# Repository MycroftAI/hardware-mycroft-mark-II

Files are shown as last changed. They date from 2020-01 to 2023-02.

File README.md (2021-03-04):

# Mycroft Mark II Hardware

*⛵️ Note that this repository is a work-in-progress. It will be updated and improved on over time.*

This repository contains all of the designs and technical details of the Mycroft Mark II Prototypes.

Each sub-directory represents a prototype device. Currently this consists of:
- [Mark II RPi OTS](./mark-II-rpi-ots) - the first Mark II prototype released in February 2020 made from off-the-shelf components. [Deprecated]
- [Mark II RPi DevKit](./mark-II-Rpi-devkit) - the second iteration of the Mark II prototype. This includes a custom daughterboard (SJ201) that integrates the components from the OTS prototype into a single PCB.

## Our open hardware principles
* **Copy our designs** – build your own Mycroft Mark 2 - Raspberry Pi Edition or its individual parts
* **Modify our designs** – remixing is encouraged
* **Sell products based on our designs** – commercial use is permitted
* **Always keep the open license** – contribute your output back to the community
* **Credit the original author(s)** – like they do in science

## Feedback or ideas

We are always keen to hear from the community about ways to improve these designs. Whether you're a hacker, maker, engineer, or something else - join us in the:
- [Community Forums](https://community.mycroft.ai)
- [Community Chat](https://chat.mycroft.ai)
- or email us at [dev@mycroft.ai](mailto:dev@mycroft.ai)

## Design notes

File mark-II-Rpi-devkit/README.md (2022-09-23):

# Mycroft Mark II - DevKit Prototype

## Kit Major Components
* Raspberry Pi 4
* SJ201 Daugherboard
* Audio Chamber
* Dual 5W Speaker drivers
* 4.2" Full Color touchscreen LCD
* Acrylic Enclosure
* Universal 12V power supply (USA, EU,UK, AUS, CCC)

## SJ201 Daughterboard
This prototype includes a custom daughterboard (SJ201) that integrates the components from the OTS prototype into a single PCB.

The SJ201 interfaces directly to the Raspberry Pi 4 via the 40-pin GPIO adding a high-quality speaker and microphone array, as well as LEDs and hardware inputs for non-voice interaction and feedback.

The part number SJ201 is derived from Mike’s “Simon Jester” alias in “The Moon is a Harsh Mistress”.

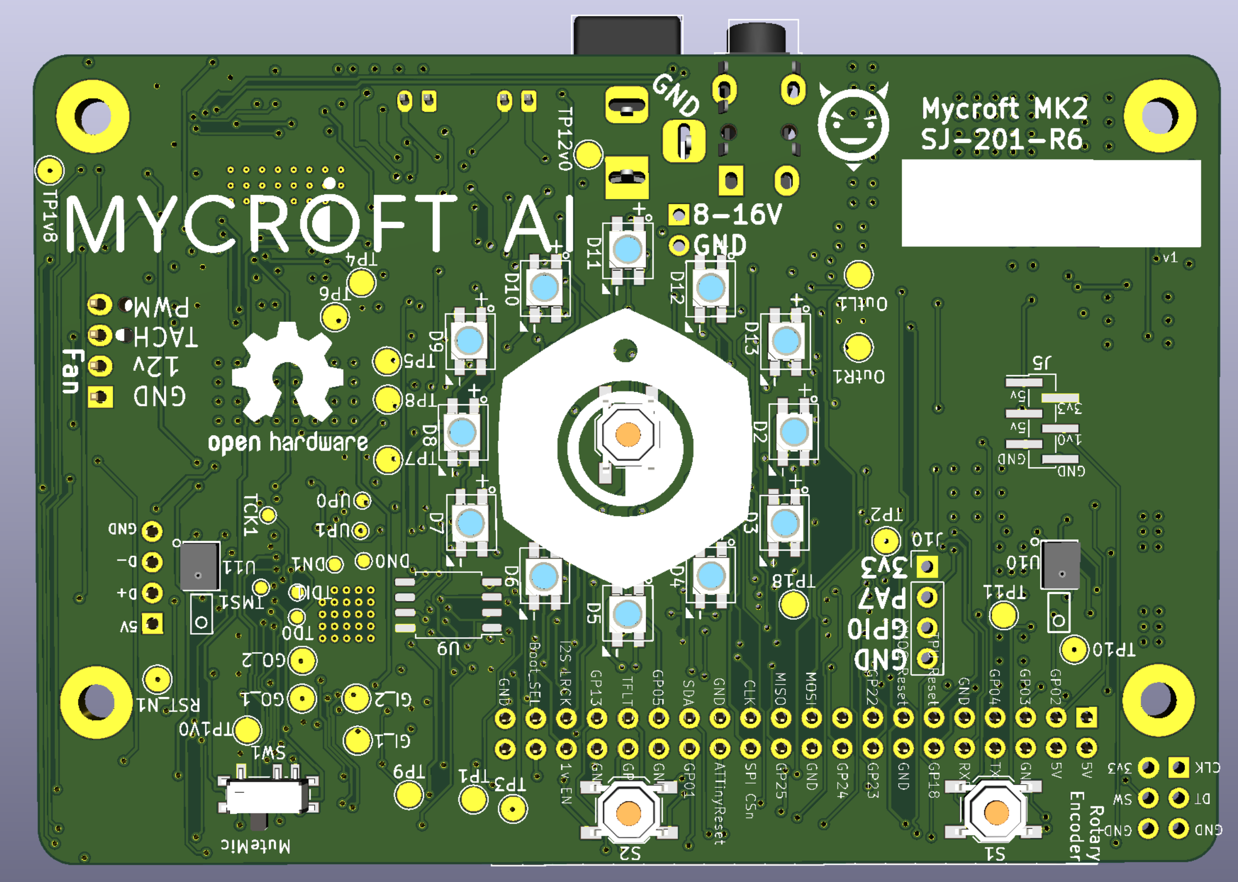
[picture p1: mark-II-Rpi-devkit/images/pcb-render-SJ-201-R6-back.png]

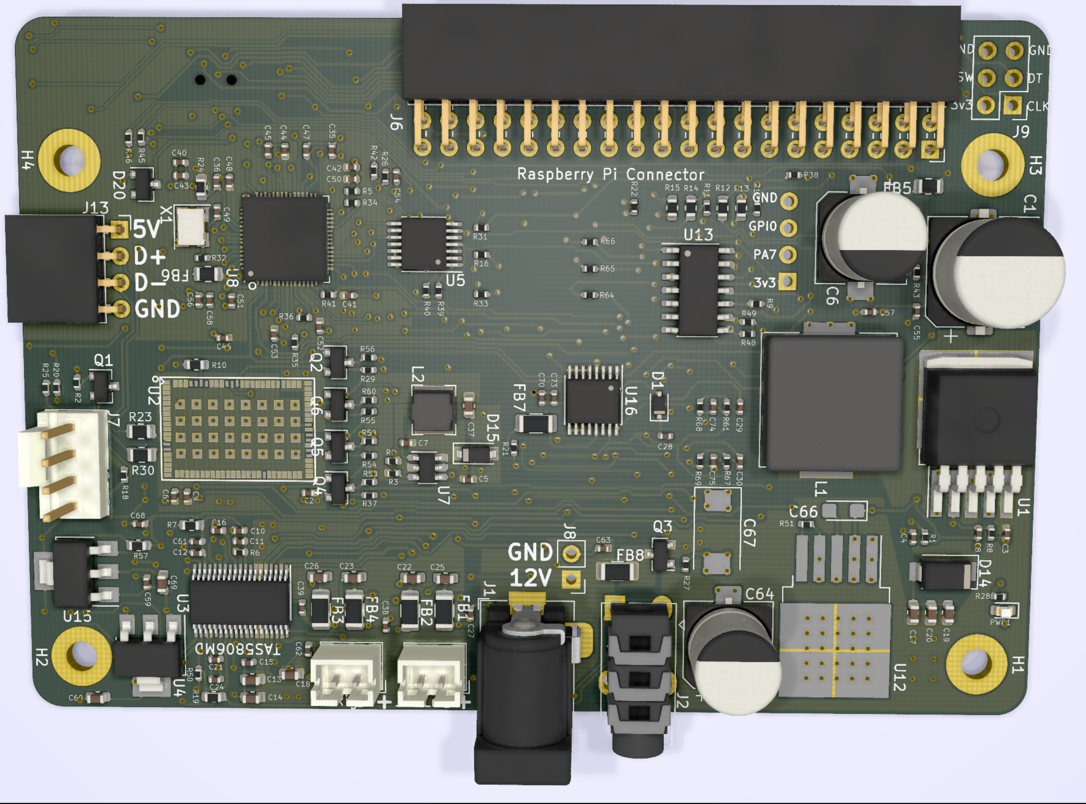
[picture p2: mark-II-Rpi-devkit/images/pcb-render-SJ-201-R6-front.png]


### SJ201 Major Components
* Audio Front End (XMOS XVF-3510) - for Microphone input processing
* I2S to Line Out (UDA1334ATS)
* 23W Amplifier (Texas Instruments TAS5806)
* 2 Digital MEMS Microphones (ST Micro MP34DT05)
* 12 RGB LEDs (WorldSemi WS2812B-MINI)
* 3 momentary buttons (volume up, volume down, action)
* 1 toggle switch (mic mute)
* ATtiny1614 - control LEDs, other I/O

### Technical Documentation
For technical details of these board see the 
* [SJ201-Datasheet](./KiCAD/SJ201-Raspberry%20Pi%204%20Daughterboard/README.md).

## New Form Factor
The SJ201 connects to the Raspberry Pi GPIO header at a 90 degree angle. This allows the microphone array and hardware inputs to be well positioned in the enclosure, whilst maintaining the simplicity of a direct connection to the main board. 

This interface makes a landscape form factor the most viable for this prototype. The blocking of the major components can be found within the [Mechanical CAD > MkII Blocking r2.zip](./Mechanical%20CAD/MkII%20Blocking%20r2.zip). 

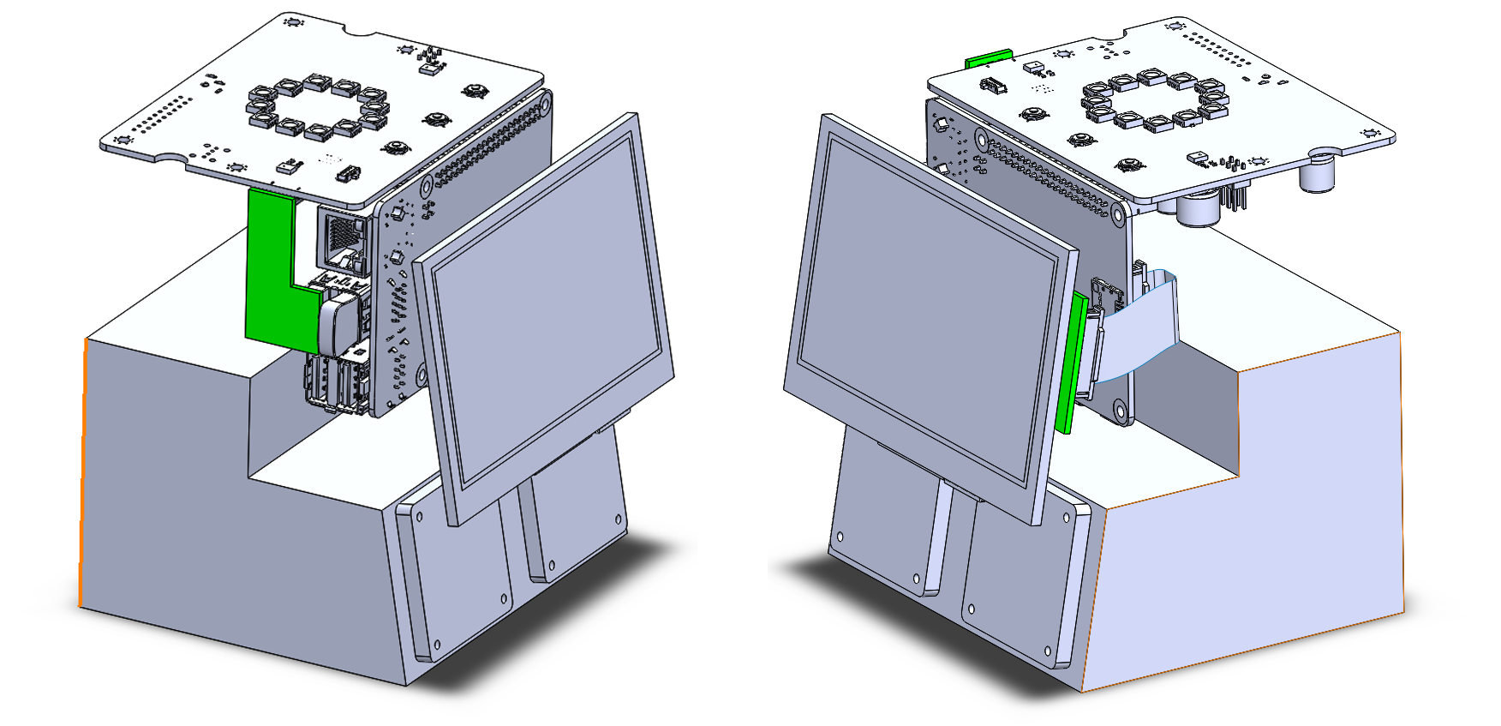
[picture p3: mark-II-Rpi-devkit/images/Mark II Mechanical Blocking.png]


## 3D Printable Case
STL files for 3D printing are available in this directory to print your own enclosure. For final construction you will also need threaded inserts and screws. For the inserts we recommend - Thread Diameter: M2.5; Pitch: 0.45; Outer Dia: 3.5mm; Length: 4mm. [Available here](https://www.amazon.com/uxcell-Threaded-Insert-Embedment-Knurled/dp/B01N8QX6RX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).

Complete assembly instructions can be found [here on Instructables](https://www.instructables.com/Mycroft-Mark-II-3D-Printed-Developer-Kit-Assembly/).

## Our open hardware principles
* **Copy our designs** – build your own Mycroft Mark 2 - Raspberry Pi Edition or its individual parts
* **Modify our designs** – remixing is encouraged
* **Sell products based on our designs** – commercial use is permitted
* **Always keep the open license** – contribute your output back to the community
* **Credit the original author(s)** – like they do in science

## Feedback or ideas

We are always keen to hear from the community about ways to improve these designs. Whether you're a hacker, maker, engineer, or something else - join us in the:
- [Community Forums](https://community.mycroft.ai)
- [Community Chat](https://chat.mycroft.ai)
- or email us at [dev@mycroft.ai](mailto:dev@mycroft.ai)

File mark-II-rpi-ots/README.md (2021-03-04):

# Mycroft Mark II - Rpi Prototype Hardware
*Mycroft's Mark II Raspberry Pi 3 based prototype designs*  
*⛵️ This design is not longer offcially supported by Mycroft *

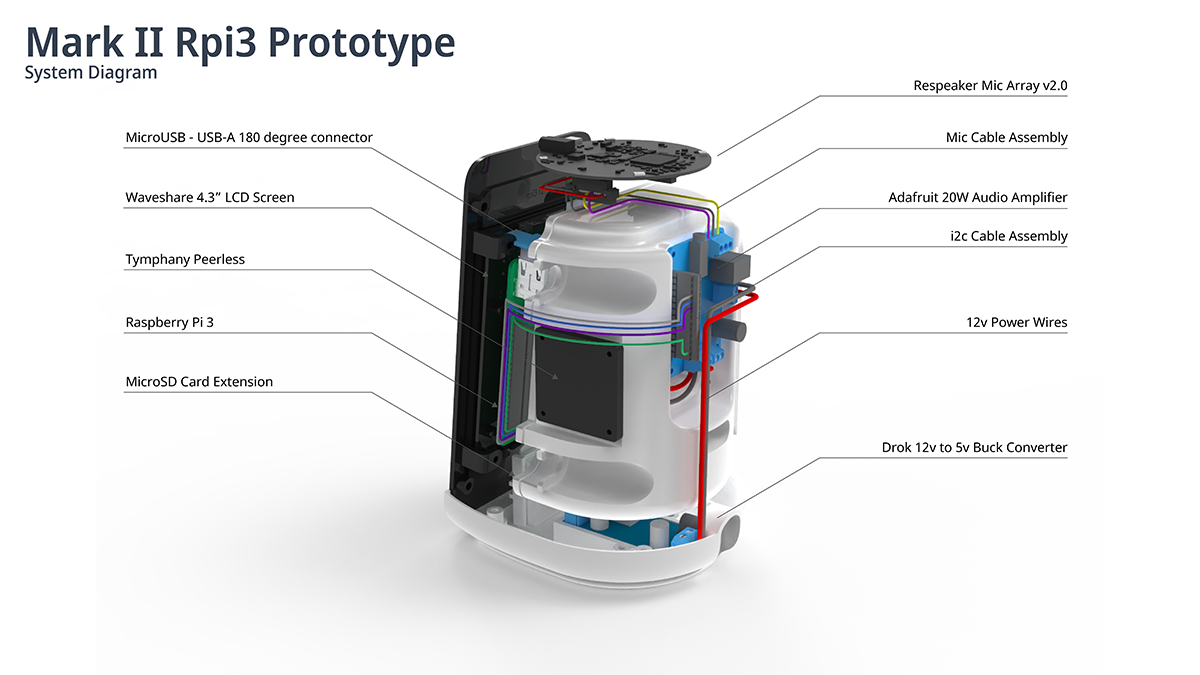
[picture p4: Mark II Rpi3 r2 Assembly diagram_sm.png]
Exploded view of prototype


## Our open hardware principles
* **Copy our designs** – build your own Mycroft Mark 2 - Raspberry Pi Edition or its individual parts
* **Modify our designs** – remixing is encouraged
* **Sell products based on our designs** – commercial use is permitted
* **Always keep the open license** – contribute your output back to the community
* **Credit the original author(s)** – like they do in science

## License
We're open-sourcing all our designs under the CERN Open Hardware License, which is one of the open hardware licenses recommended by OSHWA, the Open Source Hardware Association. The release involves every single piece of our design except components we have no control over, like the Raspberry Pi. We've also joined the Open Source Hardware Certification Program.

Open Source Hardware Logo OSHW (https://certification.oshwa.org/)

## Instructions
### Getting Started
To begin you need to purchase the parts listed in the [Bill of Materials (BOM)](BOM.md). The Mark II Raspberry Pi 3 prototype consists of 7 major components and many smaller components needed to connect them together. The 7 major components are:

* **Raspberry Pi 3B (not 3B+ or 4 yet)**
* **Seeed Studios Respeaker Mic Array v2.0**
* **Waveshare 4.3" IPS 800x480 LCD**
* **Drok 12v to 5v 5A buck converter part # 200217**
* **Adafruit 20W Stereo class D Amplifer - MAX9744**
* **A pair of Tymphany Peerless TC5FC07-04 speaker drivers**
* **A set of 3D printed Mark II Raspbery Pi 3 prototype parts**

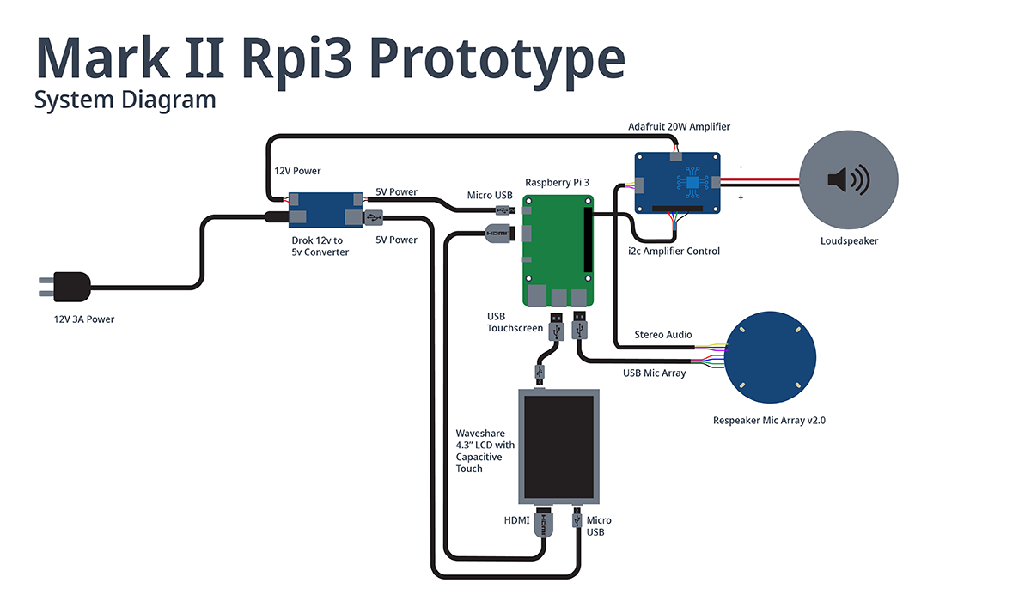
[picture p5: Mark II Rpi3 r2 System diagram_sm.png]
System diagram


### Creating the Custom Cable Assemblies
To connect the Raspberry Pi, Respeaker Mic Array V2.0, and Adafruit Amplifer two custom cable assemblies are required. The first cable assembly allows the Respeaker Mic Array to communicate to the Raspberry Pi via USB and to the Amplifer via analog stereo audio. To create the Microphone cable assembly follow this video guide:  
Microphone cable assembly video guide (https://youtu.be/UepmmYCgYgI)

The second cable assembly connects the i2c interface from the GPIO on the Raspberry Pi to the Adafruit amplifier. This allows the Raspberry Pi to digitally control the gain on the amplifier. To create the GPIO to i2c cable assembly follow this video guide:  
GPIO to i2c cable assembly video guide (https://youtu.be/yoYU8CrY8kU).

The connectors and ribbon cables required to build both of these cable assemblies are listed in the BOM.

### 3D Printing the Housing
The parts for the housing are shared as both STL and STP files under [CAD](https://github.com/MycroftAI/hardware-mycroft-mark-II-rpi/tree/master/CAD). Our prototypes are printed on a Formlabs SLA 3D printer but these can be adapted for printing on an FFF machine as well. You will need to orient the parts and slice them based on the requirements of your printer. Some parts require the additoin of threaded inserts for assembly. Two sizes of threaded inserts are used in the prototype m2.5 and m2. These can be installed in the parts with a soldering iron if using FFF printing, or with Cyanoacrylate glue (super glue) if you're using an SLA printer. SLA printed parts do not melt like FFF parts so installation with a soldering iron won't work. These images show the size and location of the threaded inserts [threaded insert locations](https://github.com/MycroftAI/hardware-mycroft-mark-II-rpi/tree/master/CAD/threaded%20insert%20locations)

### Assembling the Amplifier and Preparing the Speakers
Follow [this guide](https://learn.adafruit.com/adafruit-20w-stereo-audio-amplifier-class-d-max9744) on Adafruit's website to assemble the amplifier. Soldering skills are needed. You will also need to solder leads onto the Tymphany speaker drivers. There is a small dot marking the positive side of the speaker. It is important that you wire the speakers correctly or they will be out of phase. Use the red 22 gauge wire for positive and the black for negative.

### Assembling the Audio Chamber
The audio chamber is printed in two parts and glued together with hot glue. The Tymphany drivers are installed on either side of the Audio chamber and the wires go through holes in the back to allow for easy connection to the speaker terminals on the amplifier. Install the Amplifer to the back of the Audio Chamber with 4 m2x6mm screws.

### Final Assembly
A video is coming soon. Connect the Raspberry Pi3 to the Waveshare display with the Waveshare included stand-offs. Connect the HDMI to HDMI connector (included with Waveshare display) and USB-A to MicroUSB connector (included with the Waveshare display) to the Rpi3 and the display. Install the Waveshare display and Rpi3 assembly through the front facing side of the Front Piece. It is a tight squeeze so you will need to angle the display to get it in. The ports should be facing up. Secure the display with 4 m2.5x6mm screws through the 4 L-shaped brackets. Attach the two Body pieces to the threaded inserts on the Front Piece. Next attach the the Drok Power Supply to the Base. The barrel connector should line up with a hole in the base. Plug the Cerrxian USB-A to MicroUSB cable into the USB port on the Drok. Attach a MicroUSB cable with positive and negative leads to the terminal next to the USB port on the Drok power converter. Next hot glue the SD Card extension behind the Drok Power Converter so that it is facing down and the MicroSD card slot will be accessible from the bottom of the device. Bring the Body/Front Piece assembly and Base together and plug the MicroSD card extension into the Rpi3. Now attach the Base to the Body and Front Piece assembly via 4 m2.5x10mm screws through the holes in the base of the Mark II. Attach the Respeaker Mic Array v2.0 to the Top-2 with 3 m2x4mm screws. Attach the Top-2 and Mic Array assembly to the Top piece with 4 m2x6mm screws. Attach the Microphone Cable Assembly to the bottom of the Respeaker Mic Array. Plug the USB into the Raspberry Pi, and slide the assembled Microphone Array and Top into the slots at the top of the Body. Attach the i2c Cable Assembly to the Raspberry Pi 3. Install the Audio Chamber onto the 4 screw bosses on the Body. The Audio Chamber won't be secure until the Back is installed. Placing the Mark II face down on a soft surface at this point is probably the easiet for installation. Connect the 12v terminal on the Drok power converter to the 12v terminal on the Amplifier with red and black 22 gauge wire. Connect the 3 audio cables from the Mic Cable Assembly to the L, N, R terminals on Amplifier. Now install the back piece through the Audio Chamber and secure it to the Body. The Mark II prototype assembly is now complete.

### Software
We still need to release the GUI prototype software, but once the software is relased, download the image burn it to a 16gb or larger SD card with Etcher and plug it into the bottom of the Mark II. Plug in the power supply and follow the instructions.

## Contact
If you are doing, or planning to do, something interesting with our designs, or if you just have a question regarding the files, get in touch with our Chief of Design Derick! (He was the one who designed Mycroft Mark II’s enclosure.)

Derick

**Derick Schweppe**  
Mycroft AI’s Chief of Design  
derick.schweppe@mycroft.ai

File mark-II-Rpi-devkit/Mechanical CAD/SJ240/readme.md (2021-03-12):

# Mycroft Mark II - SJ240 3D Printed Housing
## This 3D printed Housing for use with the SJ201

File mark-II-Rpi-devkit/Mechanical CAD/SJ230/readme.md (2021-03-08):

# Mycroft Mark II - SJ230 Laser Cut Acrylic Housing

## This Acrylic Housing is used in the Enhanced Dev Kit
The cut file for the housing (DXF, SVG) contains the following parts arranged for cutting on a 12" x 18" Sheet of 1/4" Acrylic (ture thickness of 5.5mm)

* SJ230-01	Top (contains 4 m2.5 threaded inserts)
* SJ230-02	Right Side
* SJ230-03	Left Side
* SJ230-04	Front (contains 2 m2.5 threaded inserts)
* SJ230-05	Bottom
* SJ230-06	Speaker Mount, Right (contains 2 m2.5 threaded inserts)
* SJ230-07	Speaker Mount, Left (contains 2 m2.5 threaded inserts)
* SJ230-08	Camera alignment

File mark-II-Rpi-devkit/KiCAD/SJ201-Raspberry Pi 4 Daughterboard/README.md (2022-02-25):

# SJ201 Datasheet - Rev 8

This board interfaces directly to the Raspberry Pi 4 via the 40-pin GPIO adding a high-quality speaker and microphone array, as well as LEDs and hardware inputs for non-voice interaction and feedback.

The part number SJ201 is derived from Mike’s “Simon Jester” alias in “The Moon is a Harsh Mistress”.




## About this Document

This Datasheet will contain all the relevant information for the manufacturing of the SJ201 including information about PCB design, PCB manufacturing process.

## Major Components
* Audio Front End (XMOS XVF3510) - for Microphone input processing
* 23W I2S Digital Amplifier (Texas Instruments TAS5806MD)
* 2 Digital MEMS Microphones ([Knowles SPK0641HT4H-1](https://www.digikey.com/en/products/detail/knowles/SPK0641HT4H-1/8573345))
* 12 RGB LEDs (WorldSemi WS2812B-MINI)
* 3 momentary buttons (volume up, volume down, action)
* 1 toggle switch (mic mute)
* ATtiny1614 - control LEDs, other I/O

## Hardware Notes

- The SJ201 is plugged into the GPIO header of the Raspberry Pi 4 board.
- The pins required for the operation of the Raspberry Pi 4 MIPI and CSI are not used on the SJ201 GPIO header. The display and camera do not connect to the SJ201.
- The barrel jack on the SJ201 requires a 12V, 3A regulated DC input.

## Software Notes
- SHTDN (GPIO pin GPIO5) must be set high to enable the audio amplifier.
- The TAS5806 outputs I2S to the XMOS chip. 

## Configuration options

### Default Use Case

The SJ201 is connected to a Raspberry Pi4 via the header. 

12V is supplied to the SJ201 via the barrel jack.

The SJ201 creates 5V using a 3A buck converter, which powers the Raspberry Pi.

The SJ201 creates 3.3V using a linear regulator, which powers the on-board devices.

4.4ohm, 5W speakers are connected to the JST connectors. [Note, in the current implementation the amplifier is capable of supplying 13W to each speaker, so volume must be limited in software to avoid damage.]

### Test Configuration Options

The J5 header serves as a test point for the 3.3V, 5V and 12V supplies. 

The J5 header can also be used to bypass the on-board buck converter and/or linear regulator.

The buck converter does not need to be turned off - it can tolerate an external supply. To completely disable it, lift the appropriate pin.

The 1.0V supply can be tested using Test Point TP1_0V1 near the XMOS IC.

## Design Notes

### Power Domains

The SJ201 is powered by an external 12V 3A DC supply (wall wart) via a barrel connector. The SJ201 has 4 voltage domains:

- VDD 12V externally supplied power

- PVDD 12V Analog Audio Power

- 5V  5V derived from VDD

- 3V  3.3V derived from 5V

- 1V  1.0V derived from 5V for the XMOS core

All power domains share a common ground.

- GND  Ground

### Microphone DSP

### Audio Amplifier

**Filterless modulation**  
We are using the TAS5806, in a "filterless amplifier" design. This is lower cost than using a true LC filter for each output, but can be susceptible to large EMI output if not done properly. This can lead to failure to meet FCC and other standards required for consumer electronics. The following design rules are intended to minimize EMI in the system.

**Speaker power**  
With a 4ohm speaker and a 12V supply, each channel can achieve ~13W. The speaker we're using is 4.4ohm, 5W max. The volume must be limited in software to avoid damaging the speaker.

## PCB Layout Checklist

Boxes marked 🗹 are for version 6.02 (also labeled R6 v2) of the KiCAD files.

### Layers - PCB checklist

Layer 1:  Main ICs, connectors and signal routing - Power (1.0v, PVDD 12v)

Layer 2:  GND

Layer 3:  Power (12V, 5V, 3V3)

Layer 4:  Buttons, LEDs, signal routing (this layer faces upwards on device) 

### Power - PCB checklist

#### External Power Supply (VDD)

1. Barrel jack is centered on 10.6mm from the board edge.

2. Ferrite bead close to barrel jack to reduce EMI transmission along power cord to wall
   - Spec'd to handle 12V 3A

3. AO3401A MOSFET to protect against reverse voltage (i.e. user plugs in a non-standard external power supply with GND on the center pin instead of on the outside of the barrel connector.)

4. Low resistance traces for VDD and GND connecting to power planes.

#### Analog Audio Power (PVDD)

1. PVDD does not contain loops (areas of PVDD that enclose non-PVDD areas)

2. PVDD does not contain narrow antenna-like features.

3. PVDD is primarily located on layer 3

4. PVDD connects to layer 1 traces through multiple vias for lower resistance

5. See Audio Amplifier for additional considerations

#### 5V power

XL Semiconductor's XL4015 buck converter is used to generate 5V at up to 5A from the barrel jack power. This part supports a minimum input voltage of 8V and a max of 36V. 

🗹  <http://www.xlsemi.com/datasheet/XL4015%20datasheet.pdf>

🗹  R1 and R8 are 1% tolerance (these set the output voltage. 10% resistors could result in an output range of 4.4V - 5.9V.)

#### 3.3V power

A linear regulator is used to derive 3.3V from 5V.

-   AZ1117CH-3.3

-   <https://www.diodes.com/assets/Datasheets/AZ1117C.pdf> 

### Microphones (MP34DT05-A)- PCB checklist

🗹  <https://www.st.com/content/ccc/resource/technical/document/datasheet/group3/c7/90/d3/f6/b7/e7/40/c8/DM00415595/files/DM00415595.pdf/jcr:content/translations/en.DM004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> 

🗹  Power supply decoupling capacitors (100 nF ceramic, 1 μF ceramic) should be placed as near as possible to pin 1 of the device (common design practice). 

🗹  The L/R pin must be connected to Vdd or GND (refer to Table 6. L/R channel selection).

### LED (WS2812B-Mini)- PCB checklist

🗹  <https://datasheet.lcsc.com/szlcsc/2005251033_Worldsemi-WS2812B-Mini_C527089.pdf>

### Power on Reset - PCB checklist

-   <https://www.onsemi.com/pub/Collateral/NCP302-D.PDF> 

-   ~~This circuit monitors multiple power supply rails for undervoltage conditions. If any of the three power supplies are in an undervoltage condition, the NCP302 reset output will be immediately set to an active low level. All three power supplies must be above their minimum voltage levels for the NCP302 reset output to generate a "Power Good" level (Reset Output = Power Supply 1 or VP).~~ Replaced by Raspberry Pi control for startup routine.

### SG-210STF 24MHz clock - PCB checklist

🗹 Use recommended pad layout per datasheet.

-   <https://support.epson.biz/td/api/doc_check.php?mode=dl&lang=en&Parts=SG-210STF> 

### XMOS XVF3510 - PCB checklist 

Datasheets:

-   <https://www.xmos.com/documents/vocalfusionavs>

From page 26-27 of the XMOS VocalFusion XVF3510 datasheet (dated 2019-10-22).

10.1 SCHEMATICS DESIGN CHECK LIST

10.1.1. POWER SUPPLIES

🗹 The VDD (core) supply ramps monotonically (rises constantly) from 0V to its final value (0.95V - 1.05V) within 10ms (Section 6.1).

🗹 The VDD (core) supply is capable of supplying 1400mA (Section 6.1).

🗹 PLL_AVDD is filtered with a low pass filter, for example an RC filter, (Section 6.1)

10.1.2. POWER SUPPLY DECOUPLING

🗹 The design has multiple decoupling capacitors per supply, for example less than 12 402 or 0603 size surface mount capacitors of 100nF in value, per supply (Section 6.1).

🗹 A bulk decoupling capacitor of at least 10uF is placed on each supply (Section 6.1).

10.1.3. POWER ON RESET

🗹 The RST_N pins are asserted (low) until all supplies are good. There is enough time between VDDIO power good and RST_N to allow any boot flash to settle (Section 6.1).

10.1.4. CLOCKS

🗹 The CLK input pin is supplied with a clock with monotonic rising edges and low jitter.

🗹 A 24MHz reference clock must be connected to the CLK pin for all implementations.

🗹 MCLK_INOUT is connected to MCLK_IN via a PCB trace outside the device

🗹 All clock signals (CLK, MIC_CLK, QSPI_CLK, SPI_CLK, MCLK_IN, MCLK_INOUT, BCLK, LRCLK) and other audio signals must be routed well following high speed digital design guidelines, and may need buffering.

10.1.5. BOOT

~~🗹 To boot from QSPI flash, QSPI_CS_N, QSPI_D0 .. QSPI_D3, QSPI_D1_BOOTSEL, QSPI_CLK are connected and QSPI_D1_BOOTSEL is connected to QSPI D1 pin on flash device or pulled low/left floating (Section 6.4).~~ Boot from Raspi

🗹 To boot from the local host processor through SPI, QSPI_D1_BOOTSEL must be pulled high and SPI_CS_N, SPI_MOSI and SPI_MISO must be connected.

10.1.6. MICROPHONES

🗹 Both MIC_DATA pins are connected to the PCB (Section 4.4).

10.1.7. JTAG AND DEBUGGING

🗹 You have decided as to whether you need an XSYS header or not (Section 7)

🗹 If you have not included an XSYS header, you have devised a method to program the SPI-flash (Section 7).

10.2 PCB LAYOUT DESIGN CHECK LIST

10.2.1. GROUND PLANE

🗹 Multiple vias (eg, 16) have been used to connect the ground paddle to the PCB ground plane. These minimize impedance and conduct heat away from the device. (Section 6.1)

🗹 Other than ground vias, there are no (or only a few) vias underneath or closely around the device. This creates a good, solid, ground plane.

10.2.2. POWER SUPPLY DECOUPLING

🗹 The decoupling capacitors are all placed close to a supply pin (Section 6.1).

🗹 The decoupling capacitors are spaced around the device (Section 6.1).

🗹 The ground side of each decoupling capacitor has a direct path back to the center ground of the device.

10.2.3. PLL_AVDD

🗹 The PLL_AVDD filter (especially the capacitor) is placed close to the PLL_AVDD pin (Section 6.1).

### Audio Amplifier - PCB checklist

The following notes are related to the PCB layout wrt the TAS5806. We also used the MAX9744 design notes, as that was the amplifier for the first iteration and the notes are generally applicable.

1. 🗹 Ferrite bead close to 12V barrel connector
   - "It is sometimes helpful to insert RF chokes in series with the power supplies for the amplifier. Properly placed, they can confine high-frequency transient currents to local loops near the amplifier, instead of being conducted for long distances down the power supply wires." [Ref 1]

2. 🗹 Compact LC circuit from output of amplifier to JST speaker connectors
   - "the entire LC filter (including the speaker wiring) should be laid out as compactly as possible, and kept close to the amplifier." [Ref 1]

3. 🗹 Make speaker connections parallel and close to minimize area and therefore the "antenna" created
   - "Traces for current drive and return paths should be kept together to minimize loop areas." [Ref 1]

4. 🗹 Speaker wires from JST to speaker element are twisted pair and less than 10cm long.
   - "to minimize loop areas ... using twisted pairs for the speaker wires is helpful)" [Ref 1]

5. 🗹 Connect PGND to GND at a single point on the PCB. [Ref 3, p23]

6. 🗹 Connect all VDD power supplies together and bypass with a 1uF cap to GND. [Ref 3, p23]

7. 🗹 Place a bulk capacitor between PVDD and PGND. [Ref 3, p23]

8. 🗹 Use large, low-resistance output traces to speaker filters and JST connectors. [Ref 3, p23]

9. 🗹 Use large traces for the power-supply to PVDD and PGND. [Ref 3, p23]

10. 🗹 Thermal pad (area fill exposed copper) under amplifier on layer 1. [Ref 3, p23]
   - There should be no solder-mask in this area. [TODO: verify]

11. 🗹 Connect thermal pad on layer 1 to PGND on layer 2 using multiple vias. PGND area as large as practical for better heat dissipation. [Ref 3, p23]

## Production Checklist

WS2812 Mini

- [] This has to be baked for 48 hours at the baking temperature of 70-75℃ before being used. 

- [] Use up with 2 hours after taking out from oven.

- [] Please replace the unused LEDs into oven.

## References

1\. [Texas Instruments Class D Thermal Considerations](https://www.ti.com/lit/an/slaa880/slaa880.pdf?ts=1615242326443&ref_url=https%253A%252F%252Fwww.google.com%252F)

2\. [TAS5806MD data sheet](https://www.ti.com/lit/ds/symlink/tas5806md.pdf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)

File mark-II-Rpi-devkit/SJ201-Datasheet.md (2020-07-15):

# SJ201 Datasheet

## About this Document

This Datasheet will contain all the relevant information for the manufacturing of the SJ201 including information about PCB design, PCB manufacturing process.

*⛵️ Note that this repository is a work-in-progress. It will be updated and improved on over time.*

## Hardware Notes

- The SJ201 is plugged into the GPIO header of the Raspberry Pi 4 board.
- The pins required for the operation of the Raspberry Pi 4 MIPI and CSI are not used on the SJ201 GPIO header. The display and camera do not connect to the SJ201.
- The USB port on the SJ201 is aligned to connect to the USB port on the Raspberry Pi board. This utilizes a non-standard USB-A to USB-A PCB jumper board.
- The barrel jack on the SJ201 requires a 12V, 3A regulated DC input.
- We intend to experiment with lower voltage supplies, as 12V provides too much power for the speaker drivers we are likely to use in the Mark II Development Kit.

## Software Notes

- SHTDN (GPIO pin XYZ) must be set high to enable the audio amplifier.
- Due to limitations of the XMOS chip's current firmware, the audio output from the Raspberry Pi 4 goes to the USB Sound card, which then outputs to the XMOS and the amplifier in parallel. Software must configure the sound card and XMOS appropriately, including programming the XMOS to expect the proper delay from the digital audio between its input and the microphone inputs to get the best barge-in performance.
  -   In the preferred implementation, the XMOS would get the audio input from the Pi 4 directly via an I2S connection, and would then pass through that audio to the amplifier. This would reduce part count and complexity, as well as allowing the XMOS to perform DSP operations on the audio before sending it to the amplifier.

## Configuration options

### Default Use Case

The SJ201 is connected to a Raspberry Pi4 via the header. 

12V is supplied to the SJ201 via the barrel jack.

The SJ201 creates 5V using a 3A buck converter, which powers the Raspberry Pi.

The SJ201 creates 3.3V using a linear regulator, which powers the on-board devices.

4.4ohm, 5W speakers are connected to the JST connectors. [Note, in the current implementation the amplifier is capable of supplying 13W to each speaker, so volume must be limited in software to avoid damage.]

### Test Configuration Options

The J5 header serves as a test point for the 3.3V, 5V and 12V supplies. 

The J5 header can also be used to bypass the on-board buck converter and/or linear regulator.

The buck converter does not need to be turned off - it can tolerate an external supply. To completely disable it, lift the appropriate pin.

By cutting J2 trace, the J5 PVDD pin can be used to supply alternate voltages to the audio amplifiers PVDD domain, to allow for optimization of the amplifier subsystem.

The 1.0V supply can be tested using Test Point TP1_0V1 near the XMOS IC.

#### USB-Mode

To use this mode, solder USB_Power1 jumper closed.

The SJ201 can be used as a stand-alone USB device, without the Pi. In this use case, the board derives power from the USB port and does not utilize the 12V barrel supply. The audio amplifier is put into low-power shutdown mode and speaker connectors are inactive [The MAX9744 SHDN pin is pulled low by a 10K resistor].

In USB mode, it can be connected to a PC and used as a multi-mic processor with barge-in capability. The PC should be configured to output simultaneously to the SJ201 and the PC's speakers. The SJ201 is then used as a mic input to the PC, with the PC's output cancelled and the user voice isolated from the ambient room audio. 

## Design Notes

### Power Domains

The SJ201 is powered by an external 12V 3A DC supply (wall wart) via a barrel connector. The SJ201 has 4 voltage domains:

- VDD 12V externally supplied power

- PVDD  12V Analog Audio Power

- 5V  5V derived from VDD (or USB Powered if Jumper USB_Power1 soldered)

- 3V  3.3V derived from 5V

Additionally, there are two ground domains:

- GND  Ground

- PGND Analog Audio Ground

### Microphone DSP

### Audio Amplifier

**Filterless modulation**  
We are using the MAX9744, in a "filterless amplifier" design. This is lower cost than using a true LC filter for each output, but can be susceptible to large EMI output if not done properly. This can lead to failure to meet FCC and other standards required for consumer electronics. The following design rules are intended to minimize EMI in the system.

**Spread Spectrum Mode**  
The SYNC pin of the MAX9744 is pulled high to enable the spread spectrum, internally generated clock. 

**Speaker power**  
With a 4ohm speaker and a 12V supply, each channel can achieve ~13W. The speaker we're using is 4.4ohm, 5W max. The volume must be limited in software to avoid damaging the speaker. During evaluation, we may decide to supply a lower-voltage supply, such as a 7.5V wall-wart supply, to limit the output power to 5W. This would require redesign of the buck converter that derives the 5V domain for the Pi, as the current design requires a minimum of 9V.

**USB as power source**  
If USB-C is an option, then USB-powered amplification could be achieved. In the current implementation, however, this is not designed for.

### USB Sound card

- PCM2706

- <https://www.digikey.com/product-detail/en/texas-instruments/PCM2706CPJTR/296-40481-1-ND/5178358> 

### USB Hub

- FE1.1S

- <https://cdn-shop.adafruit.com/product-files/2991/FE1.1s+Data+Sheet+(Rev.+1.0).pdf>

## PCB Layout Checklist

Boxes marked 🗹 are for version 0.60 of the KiCAD files.

### Layers - PCB checklist

Layer 1:  Main ICs, connectors and signal routing - Power (1.0v, PVDD 12v)

Layer 2:  GND and PGND

Layer 3:  Power (12V, 5V)

Layer 4:  Buttons, LEDs, signal routing (this layer faces upwards on device) 

Power (3.3V) & PGND

### Power - PCB checklist

#### External Power Supply (VDD)

1. Barrel jack is centered on LED ring

2. Ferrite bead close to barrel jack to reduce EMI transmission along power cord to wall
   - Spec'd to handle 12V 3A

3. AOD4184A MOSFET to protect against reverse voltage (i.e. user plugs in a non-standard external power supply with GND on the center pin instead of on the outside of the barrel connector.)

4. Low resistance traces for VDD and GND connecting to power planes.

#### Analog Audio Power (PVDD)

1. PVDD does not contain loops (areas of PVDD that enclose non-PVDD areas)

2. PVDD does not contain narrow antenna-like features.

3. PVDD is primarily located on layer 3

4. PVDD connects to layer 1 traces through multiple vias for lower resistance

5. See Audio Amplifier for additional considerations

#### 5V power

XL Semiconductor's XL4015 buck converter is used to generate 5V at up to 5A from the barrel jack power. This part supports a minimum input voltage of 8V and a max of 36V. 

🗹  <http://www.xlsemi.com/datasheet/XL4015%20datasheet.pdf>

🗹  R1 and R8 are 1% tolerance (these set the output voltage. 10% resistors could result in an output range of 4.4V - 5.9V.)

#### 3.3V power

A linear regulator is used to derive 3.3V from 5V.

-   AZ1117CH-3.3

-   <https://www.diodes.com/assets/Datasheets/AZ1117C.pdf> 

### Microphones (MP34DT05-A)- PCB checklist

🗹  <https://www.st.com/content/ccc/resource/technical/document/datasheet/group3/c7/90/d3/f6/b7/e7/40/c8/DM00415595/files/DM00415595.pdf/jcr:content/translations/en.DM004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> 

🗹  Power supply decoupling capacitors (100 nF ceramic, 1 μF ceramic) should be placed as near as possible to pin 1 of the device (common design practice). 

🗹  The L/R pin must be connected to Vdd or GND (refer to Table 6. L/R channel selection).

### LED (WS2813-Mini)- PCB checklist

🗹  <https://datasheet.lcsc.com/szlcsc/1810010024_Worldsemi-WS2813-Mini-WS2813-3535_C189639.pdf>

### USB Hub (FE1.1S) - PCB checklist

🗹  <https://cdn-shop.adafruit.com/product-files/2991/FE1.1s+Data+Sheet+(Rev.+1.0).pdf>

### Power on Reset - PCB checklist

-   <https://www.onsemi.com/pub/Collateral/NCP302-D.PDF> 

-   This circuit monitors multiple power supply rails for undervoltage conditions. If any of the three power supplies are in an undervoltage condition, the NCP302 reset output will be immediately set to an active low level. All three power supplies must be above their minimum voltage levels for the NCP302 reset output to generate a "Power Good" level (Reset Output = Power Supply 1 or VP).

### SG-210STF 24MHz clock - PCB checklist

🗹 Use recommended pad layout per datasheet.

-   <https://support.epson.biz/td/api/doc_check.php?mode=dl&lang=en&Parts=SG-210STF> 

### XMOS XVF3510 - PCB checklist 

Datasheets:

-   <https://www.xmos.com/documents/vocalfusionavs>

From page 26-27 of the XMOS VocalFusion XVF3510 datasheet (dated 2019-10-22).

10.1 SCHEMATICS DESIGN CHECK LIST

10.1.1. POWER SUPPLIES

🗹 The VDD (core) supply ramps monotonically (rises constantly) from 0V to its final value (0.95V - 1.05V) within 10ms (Section 6.1).

☐ The VDD (core) supply is capable of supplying 1400mA (Section 6.1).

🗹 PLL_AVDD is filtered with a low pass filter, for example an RC filter, (Section 6.1)

10.1.2. POWER SUPPLY DECOUPLING

🗹 The design has multiple decoupling capacitors per supply, for example less than 12 402 or 0603 size surface mount capacitors of 100nF in value, per supply (Section 6.1).

🗹 A bulk decoupling capacitor of at least 10uF is placed on each supply (Section 6.1).

10.1.3. POWER ON RESET

🗹 The RST_N pins are asserted (low) until all supplies are good. There is enough time between VDDIO power good and RST_N to allow any boot flash to settle (Section 6.1).

10.1.4. CLOCKS

🗹 The CLK input pin is supplied with a clock with monotonic rising edges and low jitter.

🗹 A 24MHz reference clock must be connected to the CLK pin for all implementations.

🗹 MCLK_INOUT is connected to MCLK_IN via a PCB trace outside the device

🗹 All clock signals (CLK, MIC_CLK, QSPI_CLK, SPI_CLK, MCLK_IN, MCLK_INOUT, BCLK, LRCLK) and other audio signals must be routed well following high speed digital design guidelines, and may need buffering.

10.1.5. BOOT

🗹 To boot from QSPI flash, QSPI_CS_N, QSPI_D0 .. QSPI_D3, QSPI_D1_BOOTSEL, QSPI_CLK are connected and QSPI_D1_BOOTSEL is connected to QSPI D1 pin on flash device or pulled low/left floating (Section 6.4).

🗹 To boot from the local host processor through SPI, QSPI_D1_BOOTSEL must be pulled high and SPI_CS_N, SPI_MOSI and SPI_MISO must be connected.

10.1.6. MICROPHONES

🗹 Both MIC_DATA pins are connected to the PCB (Section 4.4).

10.1.7. JTAG AND DEBUGGING

🗹 You have decided as to whether you need an XSYS header or not (Section 7)

🗹 If you have not included an XSYS header, you have devised a method to program the SPI-flash (Section 7).

10.2 PCB LAYOUT DESIGN CHECK LIST

10.2.1. GROUND PLANE

🗹 Multiple vias (eg, 16) have been used to connect the ground paddle to the PCB ground plane. These minimize impedance and conduct heat away from the device. (Section 6.1)

🗹 Other than ground vias, there are no (or only a few) vias underneath or closely around the device. This creates a good, solid, ground plane.

10.2.2. POWER SUPPLY DECOUPLING

🗹 The decoupling capacitors are all placed close to a supply pin (Section 6.1).

🗹 The decoupling capacitors are spaced around the device (Section 6.1).

🗹 The ground side of each decoupling capacitor has a direct path back to the center ground of the device.

10.2.3. PLL_AVDD

🗹 The PLL_AVDD filter (especially the capacitor) is placed close to the PLL_AVDD pin (Section 6.1).

### Audio Amplifier - PCB checklist

The following notes are related to the PCB layout wrt the MAX9744.

1. 🗹 Ferrite bead close to 12V barrel connector
   - "It is sometimes helpful to insert RF chokes in series with the power supplies for the amplifier. Properly placed, they can confine high-frequency transient currents to local loops near the amplifier, instead of being conducted for long distances down the power supply wires." [Ref 1]

2. 🗹 Compact LC circuit from output of MAX9744 to JST speaker connectors
   - "the entire LC filter (including the speaker wiring) should be laid out as compactly as possible, and kept close to the amplifier." [Ref 1]

3. 🗹 Make speaker connections parallel and close to minimize area and therefore the "antenna" created
   - "Traces for current drive and return paths should be kept together to minimize loop areas." [Ref 1]

4. 🗹 Speaker wires from JST to speaker element are twisted pair and less than 10cm long.
   - "to minimize loop areas ... using twisted pairs for the speaker wires is helpful)" [Ref 1]

5.  🗹 Connect PGND to GND at a single point on the PCB. [Ref 3, p23]

6. 🗹 Connect all VDD power supplies together and bypass with a 1uF cap to GND. [Ref 3, p23]

7. 🗹 Place a bulk capacitor between PVDD and PGND. [Ref 3, p23]

8. 🗹 Use large, low-resistance output traces to speaker filters and JST connectors. [Ref 3, p23]

9. 🗹 Use large traces for the power-supply to PVDD and PGND. [Ref 3, p23]

10. 🗹 Thermal pad (area fill exposed copper) under MAX9744 on layer 1. [Ref 3, p23]
   - There should be no solder-mask in this area. [TODO: verify]

11. 🗹 Connect thermal pad on layer 1 to PGND on layer 2 using multiple vias. PGND area as large as practical for better heat dissipation. [Ref 3, p23]

## Production Checklist

WS2813 Mini

- [] This has to be baked for 48 hours at the baking temperature of 70-75℃ before being used. 

- [] Use up with 2 hours after taking out from oven.

- [] Please replace the unused LEDs into oven.

## References

1\. Analog Class D Amps

- <https://www.analog.com/en/analog-dialogue/articles/class-d-audio-amplifiers.html>
  - Class-D audio amplifiers. 
  - Good information about the why's of component placement and trace layout.

2\. MAXIM Class D Thermal Considerations

- <https://www.maximintegrated.com/en/design/technical-documents/app-notes/3/3879.html>
  - Board layout
  - Speaker impedance choice

3\. MAX9744 data sheet

## Part Numbering Schema

**SJXYY[-ZZ] [rRR][.MM]**

The SJ prefix is used for component and assembly part numbers. The MYC prefix is used for packaged and ready-to-ship products.

If any part of the numbering is omitted, the reference is to the part in general or the grouping. This is permitted in documentation, but when it comes to inventory or bug reports the entire part number must be used.

SJXYY is the product family. SJ2YY refers to the Mark II family of parts. E.g. SJ200 is the Mark II Development Kit, assembled. SJ201 is the daughterboard described by this document. SJ201-01 is this datasheet.

ZZ is an optional sub-component number. E.g. SJ201-01 is this Datasheet. If SJ203 is the plastic enclosure in its entirety, SJ203-01 might be the left half, SJ203-02 might be the right half, etc.

RR is the revision number. The revision number is updated if any material changes have been made after the previous manufacturing run. This number is not changed during the iterative development process. Those revisions are tracked via the revision control system in use for development (e.g. GitHub).

MM is the manufacturing run number. Each run is assigned a new number, whether it is the same or a different facility. A large run may get multiple numbers if the manufacturer makes material changes during production. For components purchased in bulk (rather than manufactured), this number refers to the purchase number. This number may not appear on the product itself, or may simply be a sticker, but must be used for purchase orders and for labeling inventory.

## Related Parts
<table>
<tr>
    <th align="left" width="120px">Part number</th>
    <th align="left">Description</th>
</tr>
<tr>
    <td valign=top>MYC200 r01.01</td>
    <td>
    Packaged, ready-to-ship, Mark II for N.A. 
    r01 refers to the specific manifest of subcomponents used, which includes packaging, power supply, instructions, etc, which may be different from region to region. r01.01 refers to the first "print run" (i.e. purchase order).
    </td>
</tr>
<tr>
    <td valign=top>MYC201 r01.01</td>
    <td>
    Packaged, ready-to-ship, Mark II for the EU.
    The same manifest as the MYC200, with the exception of a different wall-wart.
    </td>
</tr>
<tr>
    <td valign=top>SJ200</td>
    <td>
    The assembled Mark II, sans external power supply. SJ200 (without the revision and manufacture designation) is a class of products, not a specific thing we can inventory.
    </td>
</tr>
<tr>
    <td valign=top>SJ200 r01.01</td>
    <td>
    The assembled Mark II, sans external power supply, rev 1, run 1
    r01 refers to the specific manifest of subcomponents used. 
    .01 is required for the purchase order. The same manifest (r01) may be used over and over if, for example, we order test assembly runs from a large inventory. Each of these gets a unique r01.##.
    </td>
</tr>
<tr>
    <td valign=top>SJ201</td>
    <td>
    The Raspberry Pi 4 Daughterboard (the part described by this document)
    </td>
</tr>
<tr>
    <td valign=top>SJ201-01</td>
    <td>
    This document.
    </td>
</tr>
<tr>
    <td valign=top>SJ201-01 r01</td>
    <td>
    This document, matched to the SJ201 r01 version.
    </td>
</tr>
<tr>
    <td valign=top>SJ202</td>
    <td>
    USB jumper board to connect the Pi4 to the SJ201
    </td>
</tr>
<tr>
    <td valign=top>SJ203</td>
    <td>
    The plastic enclosure, design A (anticipating that there might be more than one form factor someday). This does not refer to a manufactured item, because the enclosure consists of multiple parts.
    </td>
</tr>
<tr>
    <td valign=top>SJ203-ZZ</td>
    <td>
    The plastic enclosure parts, for ZZ = 00 to ??.
    </td>
</tr>
<tr>
    <td valign=top>SJ204-ZZ</td>
    <td>
    Retail packaging parts for production of MYC200, enclosure SJ205. ZZ = 00 to ??, for things like the printed cardbox box, quick-start pamphlet, etc. Not all of these parts will be used in a particular MYC20X manufacturing run, because it contains variants for different regions.
    </td>
</tr>
<tr>
    <td valign=top>SJ205</td>
    <td>
    LCD with custom FPC. Connects via MIPI on the Pi 4.
    </td>
</tr>
<tr>
    <td valign=top>SJ206</td>
    <td>
    Camera. Connects via the Pi 4 CSI connector.
    </td>
</tr>
<tr>
    <td valign=top>SJ207</td>
    <td>
    120V AC to 12V 3A DC power supply, N.A. style
    </td>
</tr>
<tr>
    <td valign=top>SJ208</td>
    <td>
    The Raspberry Pi 4. This part number is used for specifying the correct part for purchase orders and to inventory it for final assembly.
    </td>
</tr>
</table>

## Serial Numbers

TODO. Concept: Use large random numbers to make it difficult to make knock-off products that take advantage of Mycroft warranty or support. Serial numbers are to be pseudo-random numbers generated using a secure algorithm. Serial numbers are sent securely to the manufacturer. At a TBD Serial Number verification website, a number can be entered, and it will report if it is a genuine Mycroft serial number, and what product it is for, and if we know of any unlicensed copies. This website will have a rate limiter for queries, so serially searching for valid numbers will be unlikely to find valid numbers.

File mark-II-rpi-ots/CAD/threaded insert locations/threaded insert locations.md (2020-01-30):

These are the locations for the m2.5 and m2 threaded inserts

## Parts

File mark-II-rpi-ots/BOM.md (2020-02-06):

# Mark II Raspberry Pi Prototype 3 Bill of Materials

| Part # | Part | Description | Link |
| --- | ---- | --- | ---- |
| 1 | Raspberry Pi 3 | Single Board Computer | [Element 14](https://www.newark.com/raspberry-pi/raspberrypi3-modb-1gb/sbc-raspberry-pi-3-mod-b-1gb-ram/dp/77Y6520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)
| 2 | Respeaker Mic Array v2.0 | Multi microphone array and DSP | [Seeed Respeaker Mic Array](https://www.seeedstudio.com/ReSpeaker-Mic-Array-v2-0.html)
| 3 | Waveshare LCD | WS 4.3" Capacitive touch 800x480 LCD |  [Waveshare](https://www.waveshare.com/4.3inch-hdmi-lcd-b.htm)
| 4 | Amplifier | Adafruit 20W Class D Audio Amplifier | [Adafruit](https://www.adafruit.com/product/1752)
| 5 | Power Converter | Drok 12v to 5.2v 5A Buck Converter | [Drok](https://www.droking.com/Power-Supply-Module-DC-9V-36V-to-5.2V-5A-Double-Output-Buck-Converter-USB-Charger-Voltage-Regulator-Adapter-Driver-Module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)
| 6 | Speaker Drivers | Peerless TC5FC07-04 1-1/2" Full-Range Driver 4 Ohm | [parts express](https://www.parts-express.com/peerless-tc5fc07-04-1-1-2-paper-cone-full-range-driver-4-ohm--264-1626)
| 7 | MicroSD Extension | 15cm MicroSD card extender | [ebay](https://www.ebay.com/c/1331472913)
| 8 | Power Supply | Tri-Mag 12v 3A 36W power supply | [digikey](https://www.digikey.com/product-detail/en/tri-mag-llc/L6R36-120/364-1282-ND/7682645)
| 9 | Mic Headers | Two 2x8 Headers Amphenol 57202-G52-08LF | [Digikey](https://www.digikey.com/product-detail/en/amphenol-icc-fci/57202-G52-08LF/609-2620-ND/1090045)
| 10 | Mic Connector | Connectors Pro 16 pin IDT 2mm 2x8 | [Amazon](https://www.amazon.com/dp/B07F3V7MRM/ref=psdc_172544_t1_B07F3VHMDB)
| 11 | Mic wire | 1mm 16p ribbon wire | [Amazon](https://www.amazon.com/uxcell-Ribbon-Length-1-27mm-Connecting/dp/B07S7WDCQC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)
| 12 | Mic USB connector | USB A break out board | [Amazon](https://www.amazon.com/gp/product/B07MQFJQLT/ref=ppx_yo_dt_b_asin_title_o09_s00?ie=UTF8&psc=1)
| 13 | i2c - Rpi Connector | 40 pin 2.54mmm pitch 2x20 Rpi connector | [Amazon](https://www.amazon.com/gp/product/B00K2NTSJE/ref=ppx_yo_dt_b_search_asin_title?ie=UTF8&psc=1)
| 14 | i2c - Amplifier Connector | 16 pin 2mm pitch | [Mouser](https://www.mouser.com/ProductDetail/200-IDSS16D05.00G)
| 15 | i2c 40p Cable | 40 pin IDC 1.27mm pitch riboon cable | [Amazon](https://www.amazon.com/dp/B07V4MH8HH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)
| 16 | Mic Screws | m2 x 4mm Philips Machine Screw | [m2 x 4mm screws](https://www.mcmaster.com/92000a011)
| 17 | M2.5x6 screws | m2.5 x 6mm Philips Machine Screw 92000A104 | [m2.5 x 6m screws](https://www.mcmaster.com/92000a104)
| 18 | M2.5x10 screws | m2.5 x 10mm Philips Machine Screw 92000A106 | [m2.5 x 10m screws](https://www.mcmaster.com/92000A106)
| 19 | Red wire | Red 22 gauge solid core wire | [Adafruit](https://www.adafruit.com/product/288)
| 20 | Black wire | Black 22 gauge solid core wire | [Adafruit](https://www.adafruit.com/product/290)
| 21 | LA USB-A to LA MicroUSB | Cerrxian Left Angle USB-A to Left Angle MicroUSB | [Amazon](https://www.amazon.com/gp/product/B01N5OOYE1/ref=ppx_yo_dt_b_asin_title_o01_s00?ie=UTF8&th=1)
| 22 | Mark II Rpi3 R2 Housing | The Mark II Rpi3 R2 3d printed housing | [CAD](https://github.com/MycroftAI/hardware-mycroft-mark-II-rpi/tree/master/CAD)
| 23 | M2.5 Threaded inserts | Uxcell M2.5 Threaded inserts 3.5 mm OD x 4 mm | [Amazon](https://www.amazon.com/gp/product/B01N8QX6RX/ref=ppx_yo_dt_b_search_asin_title?ie=UTF8&psc=1)
| 24 | M2 Threaded inserts | Uxcell M2 Threaded inserts 3.2 mm OD x 3 mm | [Amazon](https://www.amazon.com/gp/product/B07LBQFNQD/ref=ppx_yo_dt_b_search_asin_title?ie=UTF8&psc=1)

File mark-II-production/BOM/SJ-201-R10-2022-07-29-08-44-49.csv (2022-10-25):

Ref | Qnty | Value | Footprint | Description | Vendor | MPN | SKU | Digikey | LCSC | Link | Qty100 | Ref20
C1 | 1 | 220uF/50V | Capacitor_SMD:CP_Elec_10x10 |  | LCSC | VE-221M1HTR-1010 |  |  | C134732 | https://datasheet.lcsc.com/szlcsc/Lelon-VE-221M1HTR-1010_C134732.pdf | 100 | C1
C2,C9,C11,C12,C28,C29,C30,C31,C32,C33,C35,C36,C40,C41,C42,C43,C44,C45,C46,C47,C48,C49,C50,C51,C52,C53,C54,C57,C58,C63,C65 | 31 | 100NF | Capacitor_SMD:C_0402_1005Metric | Unpolarized capacitor, small symbol |  | CC0402KRX7R8BB104 | 302010024 |  | C1525 |  | 3100 | C2,C9,C11,C12,C28...
C3,C4,C15,C16,C21,C24,C34,C55,C56,C61 | 10 | 1uF | Capacitor_SMD:C_0402_1005Metric | Unpolarized capacitor, small symbol |  | CL05A105KA5NQNC |  |  | C52923 |  | 1000 | C3,C4,C15,C16,C21...
C5,C59 | 2 | 10UF | Capacitor_SMD:C_0402_1005Metric | Unpolarized capacitor, small symbol |  | CC0402MRX5R5BB106 | 302010053 |  | C15525 |  | 200 | C5,C59
C6 | 1 | 330uF/25V | Capacitor_SMD:CP_Elec_8x10.5 |  |  | RVT1E331M0810 |  |  | C286135 |  | 100 | C6
C7 | 1 | 10nF | Capacitor_SMD:C_0402_1005Metric | Unpolarized capacitor, small symbol |  | CL05B103KB5NNNC |  |  | C15195 |  | 100 | C7
C8 | 1 | 33NF | Capacitor_SMD:C_0402_1005Metric | Unpolarized capacitor, small symbol |  | GRM155R71A333KA01D |  |  | C1585 |  | 100 | C8
C10 | 1 | 4.7UF | Capacitor_SMD:C_0402_1005Metric | Unpolarized capacitor, small symbol |  | CL05A475MP5NRNC |  |  | C23733 |  | 100 | C10
C13,C14,C19,C20,C37,C60 | 6 | 22UF | Capacitor_SMD:C_0603_1608Metric | Unpolarized capacitor, small symbol |  | CL10A226MQ8NRNE |  |  | C59461 |  | 600 | C13,C14,C19,C20,C...
C17,C18 | 2 | 100NF | Capacitor_SMD:C_0603_1608Metric | Unpolarized capacitor, small symbol |  | CC0603KRX7R9BB104 |  |  | C14663 |  | 200 | C17,C18
C22,C23,C25,C26 | 4 | 220nF | Capacitor_SMD:C_0603_1608Metric | Unpolarized capacitor, small symbol |  | CL10B224KA8NNNC |  |  | C21120 |  | 400 | C22,C23,C25,C26
C27,C38,C39,C62 | 4 | 1NF | Capacitor_SMD:C_0402_1005Metric | Unpolarized capacitor, small symbol |  | 0402B102K500NT |  |  | C1523 |  | 400 | C27,C38,C39,C62
C64 | 1 | 470UF/16V | Capacitor_SMD:CP_Elec_8x10.5 |  |  | SMD CAP Aluminum 470uF-16V;D8.0*H10.2mm | 302030006 |  | C176671 |  | 100 | C64
D1 | 1 | 250mA/100V | Diode_SMD:D_SOD-323F | Diode |  | 1N4148WSF-7 |  |  | C2128 |  | 100 | D1
D2,D3,D4,D5,D6,D7,D8,D9,D10,D11,D12,D13 | 12 | WS2812B | Mycroft:LED_WS2812_Mini_3.5x3.5mm_P1.1mm | RGB LED with integrated controller |  | WS2812B-MINI(WS2812B-3535) |  |  | C527089 | https://lcsc.com/product-detail/Others_WS2812B-Mini-WS2812B-3535_C189639.html | 1200 | D2,D3,D4,D5,D6,D7...
D14 | 1 | D_Schottky | Diode_SMD:D_SMA | Schottky diode |  | SS54F |  |  | C22452 |  | 100 | D14
D15 | 1 | D_Schottky | Diode_SMD:D_SOD-123 | Schottky diode |  | B5819W |  |  | C8598 |  | 100 | D15
D16,D20 | 2 | TVS | Diode_SMD:D_SMB | Transient voltage suppressor diode (bi-directional) |  |  |  |  | C78408 |  | 200 | D16,D20
D17,D18,D19 | 3 | TVS | Diode_SMD:D_SOD-323 | Transient voltage suppressor diode (bi-directional) |  |  |  |  | C139297 |  | 300 | D17,D18,D19
F1 | 1 | 0.5A Hold, 1A Trip | Fuse:Fuse_1206_3216Metric | Resettable fuse, polymeric positive temperature coefficient, small symbol |  |  |  |  | C163512 |  | 100 | F1
FB1,FB2,FB3,FB4 | 4 | FB | Resistor_SMD:R_1206_3216Metric |  |  | MLB3216-301P3A(f) |  |  | C29107 |  | 400 | FB1,FB2,FB3,FB4
FB5,FB6 | 2 | 1000R | Resistor_SMD:R_0805_2012Metric |  |  | MMZ1608Y601BTA00 |  |  | C1017 |  | 200 | FB5,FB6
FB8 | 1 | 4A 28mΩ | Resistor_SMD:R_1812_4532Metric |  |  | FBMH4532HM681-T |  |  | C92881 |  | 100 | FB8
J1 | 1 | Barrel_Jack | Connector_BarrelJack:BarrelJack_Horizontal | DC Barrel Jack with an internal switch |  | DC-005-5A-2.0 |  |  | C381116 | https://lcsc.com/product-detail/Power-Connectors_XKB-Connectivity-DC-012-5A-2-0_C381117.html | 100 | J1
J3,J4 | 2 | SPK | Connector_JST:JST_PH_B2B-PH-K_1x02_P2.00mm_Vertical |  |  | B2B-PH-K-S(LF)(SN) |  |  | C131337 |  | 200 | J3,J4
J6 | 1 | Raspberry_Pi_4 | Connector_PinSocket_2.54mm:PinSocket_2x20_P2.54mm_Horizontal | expansion header for Raspberry Pi 2 & 3 |  | FH412-2*20P 0.8U |  |  |  | https://www.taydaelectronics.com/connectors-sockets/2x20-pin-2-54mm-dounle-row-right-angle-female-pin-header.html | 100 | J6
J7 | 1 | FanConnector | Mycroft:FanPinHeader_1x04_P2.54mm_Vertical | Generic connector, single row, 01x04, script generated (kicad-library-utils/schlib/autogen/connector/) |  | 744-81-04TG1B |  |  | C402775 |  | 100 | J7
J11 | 1 | I2C | Connector_IDC:IDC-Header_2x05_P2.54mm_Horizontal | Generic connector, double row, 02x05, odd/even pin numbering scheme (row 1 odd numbers, row 2 even numbers), script generated (kicad-library-utils/schlib/autogen/connector/) |  | C9140 |  |  | C9140 |  | 100 | J11
L1 | 1 | 47uH | Inductor_SMD:L_Wuerth_HCI-1365 | Inductor |  | YSPI1365-470M |  |  | C497913 | https://lcsc.com/product-detail/Power-Inductors_YJYCOIN-YSPI1365-470M_C497913.html | 100 | L1
L2 | 1 | 2.7uH ±30% 2.35A | Inductor_SMD:L_Bourns-SRN4018 | Inductor |  | SRR4028-2R7Y |  |  |  | https://www.digikey.com/en/products/detail/SRR4028-2R7Y/SRR4028-2R7YCT-ND/2127503 | 100 | L2
Q1 | 1 | MMBT3904 | Package_TO_SOT_SMD:SOT-23 | 0.2A Ic, 40V Vce, Small Signal NPN Transistor, SOT-23 |  | MMBT3904 |  |  | C382281 | https://lcsc.com/product-detail/New-Arrivals_KEXIN-MMBT3904_C382281.html | 100 | Q1
Q3 | 1 | WST4041 | Package_TO_SOT_SMD:SOT-23 | MOSFET P-CH 30V 4A SOT23 |  | WST4041 |  |  | C148357 |  | 100 | Q3
R1,R25,R38,R39,R50 | 5 | 10k | Resistor_SMD:R_0402_1005Metric | Resistor, small symbol |  | RC0402FR-0710KL |  |  | C25744 |  | 500 | R1,R25,R38,R39,R50
R2,R18,R41,R42 | 4 | 4.7k | Resistor_SMD:R_0402_1005Metric | Resistor, small symbol |  | 0402WGF4701TCE |  |  | C25900 |  | 400 | R2,R18,R41,R42
R3,R10 | 2 | 47k | Resistor_SMD:R_0402_1005Metric | Resistor, small symbol |  | 0402WGF4702TCE |  |  | C25792 |  | 200 | R3,R10
R4 | 1 | 200k | Resistor_SMD:R_0402_1005Metric | Resistor, small symbol |  | 0402WGF2003TCE |  |  | C25764 |  | 100 | R4
R5 | 1 | 10R | Resistor_SMD:R_0402_1005Metric | Resistor, small symbol |  | 0402WGF100JTCE |  |  | C25077 |  | 100 | R5
R6 | 1 | 120k | Resistor_SMD:R_0402_1005Metric | Resistor, small symbol |  | 0402WGF1203TCE |  |  | C25750 |  | 100 | R6
R7,R8,R9,R12,R13,R14,R15 | 7 | 3.3K | Resistor_SMD:R_0402_1005Metric | Resistor, small symbol |  | 0402WGF3301TCE |  |  | C25890 |  | 700 | R7,R8,R9,R12,R13,...
R11,R17,R19,R21,R64 | 5 | 470R | Resistor_SMD:R_0603_1608Metric | Resistor, small symbol |  | 0603WAF4700T5E |  |  | C23179 |  | 500 | R11,R17,R19,R21,R64
R16,R32,R33,R34,R65 | 5 | 33R | Resistor_SMD:R_0402_1005Metric | Resistor, small symbol |  | 0402WGF330JTCE |  |  | C25105 |  | 500 | R16,R32,R33,R34,R65
R20 | 1 | 27k | Resistor_SMD:R_0402_1005Metric | Resistor, small symbol |  | 0402WGF2702TCE |  |  | C25771 |  | 100 | R20
R22 | 1 | 330R | Resistor_SMD:R_0402_1005Metric | Resistor, small symbol |  | RC0402FR-07330RL | 301010466 |  | C25104 |  | 100 | R22
R24 | 1 | 4R7 | Resistor_SMD:R_0603_1608Metric | Resistor, small symbol |  | RC0402FR-074R7L |  |  | C23164 |  | 100 | R24
R27 | 1 | 100k | Resistor_SMD:R_0402_1005Metric | Resistor, small symbol |  | RC0402JR-07100KL | 301010033 |  | C25741 |  | 100 | R27
R40 | 1 | 47K | Resistor_SMD:R_0402_1005Metric | Resistor, small symbol |  | RC0402JR-0747KL |  |  | C25792 |  | 100 | R40
R43,R44,R45,R46 | 4 | 100R | Resistor_SMD:R_0402_1005Metric | Resistor, small symbol |  | 0402WGF1000TCE |  |  | C25076 |  | 400 | R43,R44,R45,R46
S1,S2,S3 | 3 | Button | Button_Switch_SMD:SW_SPST_TL3342 | SWITCH PUSHBUTTON SPST 1A 30V |  | TL3342F160QG/TR |  | EG2531TR-ND | C318884 | https://www.digikey.com/product-detail/en/e-switch/TL3342F160QG-TR/EG2531CT-ND/379004 | 300 | S1,S2,S3
SW1 | 1 | MuteMic | Button_Switch_SMD:SW_SPDT_PCM12 | Switch, single pole double throw |  | PCM12SMTR |  | 401-2016-2-ND | C221841 |  | 100 | SW1
U1 | 1 | XL4501E1 | Package_TO_SOT_SMD:TO-263-5_TabPin3 |  |  | XL4501E1 |  |  | C73025 | https://lcsc.com/product-detail/DC-DC-Converters_XLSEMI-XL4501E1_C73025.html | 100 | U1
U3 | 1 | TAS5806MD | TAS:TAS5806MDDCPR |  |  | TAS5806MDDCPR |  |  |  | https://www.mouser.com/ProductDetail/Texas-Instruments/TAS5806MDDCPR/ | 100 | U3
U4 | 1 | AMS1117-3.3 | Package_TO_SOT_SMD:SOT-223-3_TabPin2 | 1A 20V Fixed LDO Linear Regulator, 3.3V, SOT-89/SOT-223/TO-220/TO-252/TO-263 |  | AMS1117-3.3 |  |  | C6186 | https://lcsc.com/product-detail/Dropout-Regulators-LDO_ON-Semiconductor-ON-NCP565ST12T3G_C556400.html | 100 | U4
U5 | 1 | SN74LVC125APWR | Package_SO:TSSOP-14_4.4x5mm_P0.65mm |  |  | SN74LVC125APWR |  |  | C7813 |  | 100 | U5
U7 | 1 | MP2359 | Package_TO_SOT_SMD:TSOT-23-6 |  |  | MP2359DJ-LF-Z |  |  | C14259 | https://www.mouser.com/ProductDetail/Monolithic-Power-Systems-MPS/MP2359DJ-LF-Z/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 | 100 | U7
U8 | 1 | XMOS-XVF3510 | XMOS:QFN-60-1EP_7x7mm_P0.4mm_EP5.6x5.6mm |  |  | XVF3510-QF60-C |  |  |  | https://www.digikey.com/products/en/integrated-circuits-ics/audio-special-purpose/741?k=XVF3510 | 100 | U8
U10,U11 | 2 | SPK0641HT4H-1 | user:HCLGA-MP34DT05 |  |  | SPK0641HT4H-1 |  | 423-1425-1-ND |  | https://www.digikey.com/product-detail/en/knowles/SPK0641HT4H-1/423-1425-1-ND/8573351 | 200 | U10,U11
X1 | 1 | 24MHz | Oscillator:Oscillator_SMD_SeikoEpson_SG210-4Pin_2.5x2.0mm | CMOS Crystal Oscillator SPXO |  | 2N24000G33YC |  |  | C252326 | https://lcsc.com/product-detail/Oscillators_SJK-SHENZHEN-CRYSTAL-TECH-2N24000G33YC_C252326.html | 100 | X1

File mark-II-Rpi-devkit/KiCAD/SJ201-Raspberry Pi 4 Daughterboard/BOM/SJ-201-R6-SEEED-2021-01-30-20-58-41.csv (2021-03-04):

Designator | MPN | Qty | Link
C1 | VE-221M1HTR-1010 | 1 | https://datasheet.lcsc.com/szlcsc/Lelon-VE-221M1HTR-1010_C134732.pdf
C3,C4,C15,C16,C21,C24,C29,C30,C55,C56,C61 | CL05A105KA5NQNC | 11
C5,C59,C73 | 302010053 | 3
C6 | RVT1E331M0810 | 1
C7,C74,C75 | CL05B103KB5NNNC | 3
C8 | GRM155R71A333KA01D | 1
C10 | CL05A475MP5NRNC | 1
C11,C12,C28,C35,C36,C40,C41,C42,C43,C44,C45,C46,C47,C48,C49,C50,C51,C52,C53,C54,C57,C58,C63,C70 | 302010024 | 24
C13,C14,C19,C20,C37,C60 | CL10A226MQ8NRNE | 6
C17,C18 | CC0603KRX7R9BB104 | 2
C22,C23,C25,C26 | CL10B224KA8NNNC | 4
C27,C38,C39,C62 | 0402B102K500NT | 4
C64 | 302030006 | 1
D1 | 1N4148WSF-7 | 1
D2,D3,D4,D5,D6,D7,D8,D9,D10,D11,D12,D13 | WS2812B-MINI(WS2812B-3535) | 12 | https://lcsc.com/product-detail/Others_WS2812B-Mini-WS2812B-3535_C189639.html
D14 | SS54F | 1
D15 | B5819W | 1
D20 | BAT54ALT1G | 1
FB1,FB2,FB3,FB4,FB7,FB8 | MLB3216-301P3A(f) | 6
FB5,FB6 | MMZ1608Y601BTA00 | 2
J1 | DC-005-5A-2.0 | 1 | https://lcsc.com/product-detail/Power-Connectors_XKB-Connectivity-DC-012-5A-2-0_C381117.html
J2 | PJ-3210-4A | 1 | https://lcsc.com/product-detail/Audio-Video-Connectors_Korean-Hroparts-Elec-PJ-3210-4A_C136686.html
J3,J4 | B2B-PH-K-S(LF)(SN) | 2
J6 | FH412-2*20P 0.8U | 1 | https://www.taydaelectronics.com/connectors-sockets/2x20-pin-2-54mm-dounle-row-right-angle-female-pin-header.html
J7 | 744-81-04TG1B | 1
J13 | A2541HWR-4P | 1 | https://lcsc.com/product-detail/Pin-Header-Female-Header_CJT-Changjiang-Connectors-A2541HWR-4P_C225512.html
L1 | YSPI1365-470M | 1 | https://lcsc.com/product-detail/Power-Inductors_YJYCOIN-YSPI1365-470M_C497913.html
L2 | SRR4018-1R8Y | 1 | https://www.digikey.com/en/products/detail/bourns-inc/SRR4018-1R8Y/2563553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
PWR1 | 19-217/GHC-YR1S2/3T | 1 | https://lcsc.com/product-detail/Light-Emitting-Diodes-LED_0603-Green-light_C72043.html/?href=jlc-SMT
Q1 | MMBT3904 | 1 | https://lcsc.com/product-detail/New-Arrivals_KEXIN-MMBT3904_C382281.html
Q3 | AO3401A | 1
R1,R11,R17,R21,R25,R38,R39,R48,R49,R50 | RC0402FR-0710KL | 10
R2,R9,R18,R41,R42 | 0402WGF4701TCE | 5
R3 | 0402WGF4702TCE | 1
R4 | 0402WGF2003TCE | 1
R5 | 0402WGF100JTCE | 1
R6 | 0402WGF1203TCE | 1
R7 | 0603WAF0000T5E | 1
R8 | 0402WGF3301TCE | 1
R12,R13,R14,R15,R19 | 0603WAF4700T5E | 5
R16,R31,R32,R33,R34,R35,R36,R64,R65,R66 | 0402WGF330JTCE | 10
R20 | 0402WGF2702TCE | 1
R22 | 301010466 | 1
R24 | RC0402FR-074R7L | 1
R26,R40 | RC0402JR-0747KL | 2
R27 | 301010033 | 1
R28 | 0402WGF6800TCE | 1
R43,R44,R45,R46,R68,R69 | 0402WGF1000TCE | 6
R61,R67 | 0402WGF2203TCE | 2
S1,S2,S3 | TL3342F160QG/TR | 3 | https://www.digikey.com/product-detail/en/e-switch/TL3342F160QG-TR/EG2531CT-ND/379004
SW1 | PCM12SMTR | 1
U1 | XL4501E1 | 1 | https://lcsc.com/product-detail/DC-DC-Converters_XLSEMI-XL4501E1_C73025.html
U3 | TAS5806MDDCPR | 1 | https://www.mouser.com/ProductDetail/Texas-Instruments/TAS5806MDDCPR/
U4 | AMS1117-3.3 | 1 | https://lcsc.com/product-detail/Dropout-Regulators-LDO_ON-Semiconductor-ON-NCP565ST12T3G_C556400.html
U5 | SN74LVC125APWR | 1
U7 | MP2359DJ-LF-Z | 1 | https://www.mouser.com/ProductDetail/Monolithic-Power-Systems-MPS/MP2359DJ-LF-Z/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
U8 | XVF3510-QF60-C | 1 | https://www.digikey.com/products/en/integrated-circuits-ics/audio-special-purpose/741?k=XVF3510
U10,U11 | SPK0641HT4H-1 | 2 | https://www.digikey.com/product-detail/en/knowles/SPK0641HT4H-1/423-1425-1-ND/8573351
U13 | ATTINY1614-SSNR | 1
U16 | UDA1334ATS/N2,118 | 1 | https://lcsc.com/product-detail/New-Arrivals_NXP-Semicon-UDA1334ATS-N2-118_C494494.html
X1 | SG-210STF 24.0000ML3 | 1 | https://www.digikey.com/product-detail/en/epson/SG-210STF-24.0000ML3/SER4323CT-ND/7932310

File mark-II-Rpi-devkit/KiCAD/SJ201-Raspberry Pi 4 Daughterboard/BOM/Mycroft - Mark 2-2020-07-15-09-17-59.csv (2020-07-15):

Ref | Qnty | Value | Footprint | Description | Vendor | MPN | SKU | Digikey | Link
ACT1, P1, P2, P3, P4, PWR1, PWR2, | 7 | LED | LED_SMD:LED_0603_1608Metric | Light emitting diode |  | TJ-S1608SW6TGLC2R-A5
C1, | 1 | 220uF/50V | Capacitor_SMD:CP_Elec_10x10 | Polarized capacitor |  | VZH221M1HTR-1010
C2, C3, C4, C9, C11, C12, C15, C16, C55, C56, C61, | 11 | 1uF | Capacitor_SMD:C_0402_1005Metric |  |  | CC0402KRX5R6BB105 | 302010040
C6, | 1 | 330uF/25V | user:CP_Elec_8x10.5_OPL |  |  | RVT1E331M0810 | -----------------
C8, | 1 | 33NF | Capacitor_SMD:C_0402_1005Metric |  |  | GRM155R71A333KA01D | -----------------
C10, | 1 | 10UF | OPL_Capacitor:AVX-A(1206) |  |  | TAJA106K010RNJ | 302020011
C13, C14, C24, C25, C26, C27, | 6 | 470pF | Capacitor_SMD:C_0402_1005Metric |  |  | 0402B471K500NT | -----------------
C17, C18, C19, C20, C21, C22, C28, C29, C31, C33, C35, C36, C40, C41, C42, C43, C44, C45, C46, C47, C48, C49, C50, C51, C52, C53, C54, C57, C58, C63, | 30 | 100NF | Capacitor_SMD:C_0402_1005Metric |  |  | CC0402KRX7R8BB104 | 302010024
C23, | 1 | 2.2UF | Capacitor_SMD:C_0402_1005Metric |  |  | CC0402MRX5R5BB225 | 302010233
C30, C32, C34, C37, C39, C59, | 6 | 10UF | Capacitor_SMD:C_0402_1005Metric | Unpolarized capacitor, small symbol |  | CC0402MRX5R5BB106 | 302010053
C38, | 1 | 47pf | Capacitor_SMD:C_0402_1005Metric |  |  | CC0402JRNPO9BN470 | 302010007
C60, | 1 | 22UF | Capacitor_SMD:C_0603_1608Metric | Unpolarized capacitor, small symbol |  | CL10A226MQ8NRNC
C62, C64, | 2 | 470UF/16V | user:CP_Elec_8x10.5_OPL |  |  | SMD CAP Aluminum 470uF-16V;D8.0*H10.2mm | 302030006
C65, | 1 | 2.2NF | Capacitor_SMD:C_0402_1005Metric |  |  | CC0402KRX7R9BB222 | 302010022
C66, | 1 | 1NF | Capacitor_SMD:C_0402_1005Metric |  |  | CC0402KRX7R9BB102 | 302010005
D1, | 1 | 250mA/100V | Diode_SMD:D_SOD-323F | Diode |  | 1N4148WSF-7
D2, D3, D4, D5, D6, D7, D8, D9, D10, D11, D12, D13, | 12 | WS2813 | user:LED_WS2813_3.5x3.5mm_P1.1mm | RGB LED with integrated controller |  | WS2813-MINI(WS2813-3535)
D14, | 1 | D_Schottky | Diode_SMD:D_SMA | Schottky diode |  | SS54F
D20, | 1 | BAT54A | Package_TO_SOT_SMD:SOT-23 | schottky barrier diode |  | BAT54ALT1G
FB1, FB2, FB3, FB4, FB7, FB8, | 6 | FB | Resistor_SMD:R_0805_2012Metric | Ferrite bead, small symbol |  | MPZ2012S101AT000
FB5, FB6, | 2 | 1000R | Resistor_SMD:R_0603_1608Metric | Ferrite bead, small symbol |  | MMZ1608Y601BTA00
H1, H2, H3, H4, | 4 | MountingHole | MountingHole:MountingHole_3mm_Pad_Via | Mounting Hole without connection
H5, | 1 | MountingHole | mycroft:mycroft_logo_graphic | Mounting Hole without connection
H6, | 1 | MountingHole | Symbol:OSHW-Symbol_6.7x6mm_SilkScreen | Mounting Hole without connection
H7, | 1 | MountingHole | mycroft:mycroft_logo_words | Mounting Hole without connection
J1, | 1 | Barrel_Jack | mycroft:CUI_PJ-090H | DC Barrel Jack with an internal switch |  | PJ-090H |  | 102-5561-2-ND | https://www.digikey.com/product-detail/en/cui-devices/PJ-090H/102-5561-1-ND/9830192
J2, | 1 | PVDD Jumper | Jumper:SolderJumper-2_P1.3mm_Bridged_RoundedPad1.0x1.5mm | Generic connector, single row, 01x02, script generated (kicad-library-utils/schlib/autogen/connector/)
J3, | 1 | SPKLEFT | Connector_JST:JST_PH_B2B-PH-SM4-TB_1x02-1MP_P2.00mm_Vertical | Generic connector, single row, 01x02, script generated (kicad-library-utils/schlib/autogen/connector/)
J4, | 1 | SPKRIGHT | Connector_JST:JST_PH_B2B-PH-SM4-TB_1x02-1MP_P2.00mm_Vertical | Generic connector, single row, 01x02, script generated (kicad-library-utils/schlib/autogen/connector/)
J5, | 1 | PowerTP | Connector_PinHeader_2.54mm:PinHeader_2x03_P2.54mm_Vertical | Generic connector, double row, 02x03, odd/even pin numbering scheme (row 1 odd numbers, row 2 even numbers), script generated (kicad-library-utils/schlib/autogen/connector/)
J6, | 1 | Raspberry_Pi_4 | Connector_PinSocket_2.54mm:PinSocket_2x20_P2.54mm_Horizontal | expansion header for Raspberry Pi 2 & 3 |  | FH412-2*20P 0.8U |  |  | https://www.taydaelectronics.com/connectors-sockets/2x20-pin-2-54mm-dounle-row-right-angle-female-pin-header.html
J7, | 1 | USB_B_Micro | user:USB_Micro-B_GCT_USB3076-30-A | USB Micro Type B connector |  | U254-051T-4BH83-F1B |  | 2073-USB3076-30-ATR-ND
J9, | 1 | USB_A | Connector_USB:USB_A_Wuerth_614004134726_Horizontal | USB Type A connector
J10, | 1 | Debug Connector | Connector_PinHeader_2.54mm:PinHeader_2x10_P2.54mm_Vertical | Generic connector, double row, 02x10, odd/even pin numbering scheme (row 1 odd numbers, row 2 even numbers), script generated (kicad-library-utils/schlib/autogen/connector/)
L1, | 1 | 47uH | Inductor_SMD:L_Wuerth_HCI-1365 | Inductor |  | TMAX-1365-470-M
L3, | 1 | 2.2UH-20%-1.2A_0805 | OPL_Inductor:L0805 |  |  | LQM2MPN2R2MG0 | 303010086
NT1, | 1 | Net-Tie_2 | NetTie:NetTie-2_SMD_Pad0.5mm | Net tie, 2 pins
Q3, | 1 | AO3415A | digikey-footprints:SOT-23-3 | MOSFET P-CH 30V 4A SOT23 |  | AO3415A |  | 785-1193-1-ND
Q4, | 1 | FDV301N | digikey-footprints:SOT-23-3 | MOSFET N-CH 25V 220MA SOT-23 |  | FDV301N
R1, R20, R39, R42, R47, R48, R49, R50, R51, R52, | 10 | 10k | Resistor_SMD:R_0402_1005Metric | Resistor, small symbol |  | RC0402FR-0710KL
R8, | 1 | 3.3K | Resistor_SMD:R_0402_1005Metric | Resistor, small symbol |  | 0402WGF3301TCE
R9, R12, R13, R14, R15, R16, | 6 | 22R | Resistor_SMD:R_0402_1005Metric | Resistor, small symbol |  | RC0402FR-0722RL
R10, | 1 | 1M | Resistor_SMD:R_0402_1005Metric | Resistor, small symbol |  | 0402WGF1004TCE
R11, R19, | 2 | 1k5 | Resistor_SMD:R_0402_1005Metric | Resistor, small symbol |  | 0402WGF1501TCE
R17, R18, R21, R22, | 4 | 20k | Resistor_SMD:R_0402_1005Metric | Resistor, small symbol |  | 0402WGF2002TCE
R23, R25, R26, R40, | 4 | 47K | Resistor_SMD:R_0402_1005Metric | Resistor, small symbol |  | RC0402JR-0747KL | 301010005
R24, | 1 | 4R7 | Resistor_SMD:R_0402_1005Metric | Resistor, small symbol |  | RC0402FR-074R7L
R27, R30, | 2 | 100k | Resistor_SMD:R_0402_1005Metric | Resistor, small symbol |  | 0402WGF1003TCE
R28, R29, R33, R38, R53, | 5 | 330R | Resistor_SMD:R_0402_1005Metric | Resistor, small symbol |  | RC0402FR-07330RL | 301010466
R31, | 1 | 2.7k | Resistor_SMD:R_0402_1005Metric | Resistor, small symbol |  | 0402WGF2701TCE
R32, R35, R36, | 3 | 33R | Resistor_SMD:R_0402_1005Metric | Resistor, small symbol |  | 0402WGF330JTCE
R34, | 1 | 43R2 | Resistor_SMD:R_0402_1005Metric | Resistor, small symbol |  | RC0402FR-0743R2L
R37, | 1 | 30K | Resistor_SMD:R_0402_1005Metric | Resistor, small symbol |  | RC0402FR-0730KL
R41, | 1 | 4.7k | Resistor_SMD:R_0402_1005Metric | Resistor, small symbol |  | 0402WGF4701TCE
R43, R44, R45, R46, | 4 | 100R | Resistor_SMD:R_0402_1005Metric | Resistor, small symbol |  | 0402WGF1000TCE
S1, | 1 | Action | Button_Switch_SMD:SW_SPST_TL3342 | SWITCH PUSHBUTTON SPST 1A 30V |  | TL3342F160QG/TR |  | EG2531TR-ND | https://www.digikey.com/product-detail/en/e-switch/TL3342F160QG-TR/EG2531CT-ND/379004
S2, | 1 | VolUp | Button_Switch_SMD:SW_SPST_TL3342 | SWITCH PUSHBUTTON SPST 1A 30V |  | TL3342F160QG/TR |  | EG2531TR-ND | https://www.digikey.com/product-detail/en/e-switch/TL3342F160QG-TR/EG2531CT-ND/379004
S3, | 1 | VolDown | Button_Switch_SMD:SW_SPST_TL3342 | SWITCH PUSHBUTTON SPST 1A 30V |  | TL3342F160QG/TR |  | EG2531TR-ND | https://www.digikey.com/product-detail/en/e-switch/TL3342F160QG-TR/EG2531CT-ND/379004
SW1, | 1 | MuteMic | Button_Switch_SMD:SW_SPDT_PCM12 | Switch, single pole double throw |  | PCM12SMTR |  | 401-2016-2-ND
TP0, TP1, TP1_0V1, TP2, TP3, TP4, TP5, TP6, TP7, TP8, TP9, TP10, TP11, TP12, TP13, TP14, TP15, TP16, TP17, TP18, TP19, TP20, TP21, TP22, TP23, TP24, TP26, TP27, | 28 | TestPoint | TestPoint:TestPoint_Pad_D1.0mm | test point
U1, | 1 | XL4015 | Package_TO_SOT_SMD:TO-263-5_TabPin3 |  |  | XL4015E1
U2, | 1 | PCM2706 | Package_QFP:TQFP-32_7x7mm_P0.8mm |  |  | PCM2706CPJTR |  |  | https://www.digikey.com/product-detail/en/texas-instruments/PCM2706CPJTR/296-40481-1-ND/5178358
U3, | 1 | MAX9744 | max9744:max9744eth&plus_ | IC AMP AUDIO PWR 22.5W D 44TQFN |  | MAX9744ETH+T
U4, | 1 | AZ1117CH-3.3 | Package_TO_SOT_SMD:SOT-223-3_TabPin2 | 1A 20V Fixed LDO Linear Regulator, 3.3V, SOT-89/SOT-223/TO-220/TO-252/TO-263 |  | AZ1117CH-3.3TRG1
U5, | 1 | 74LVC125A | mycroft:DHVQFN14 |  |  | 74LVC125ABQ,115
U6, | 1 | FE1.1s | Package_SO:SSOP-28_3.9x9.9mm_P0.635mm | USB 2.0 High Speed 4-Port Hub Controller, SSOP-28 |  | FE1.1S
U7, | 1 | AP3428A | Package_TO_SOT_SMD:TSOT-23-5 |  |  | AP3428A |  |  | https://www.digikey.com/product-detail/en/diodes-incorporated/AP3428AKTTR-G1/AP3428AKTTR-G1DITR-ND/6186983
U8, | 1 | XMOS-XVF3510 | user:QFN-60-1EP_7x7mm_P0.4mm_EP5.6x5.6mm | XMOS-XVF3510 |  | XVF3510 |  |  | https://www.digikey.com/products/en/integrated-circuits-ics/audio-special-purpose/741?k=XVF3510
U9, | 1 | AT25SF161 16MBIT | Package_SO:SOIC-8_3.9x4.9mm_P1.27mm | Microchip SPI Serial EEPROM, DIP-8/SOIC-8/TSSOP-8 |  | AT25SF161 16MBIT |  | 1265-1230-1-ND | https://www.digikey.com/product-detail/en/adesto-technologies/AT25SF161-SSHD-T/1265-1230-2-ND/6124893
U10, U11, | 2 | MP34DT05 | user:HCLGA-MP34DT05 |  |  | MP34DT05 |  | 497-17809-1-ND | https://www.digikey.com/product-detail/en/stmicroelectronics/MP34DT05TR-A/497-17809-1-ND/8535500
U12, | 1 | NCP303LSN30 | Package_TO_SOT_SMD:SOT-23-5 |  |  | NCP303LSN30T1G
USB_Power1, | 1 | USB Jumper | Jumper:SolderJumper-2_P1.3mm_Open_TrianglePad1.0x1.5mm | Generic connector, single row, 01x02, script generated (kicad-library-utils/schlib/autogen/connector/)
X1, | 1 | SG-210STF 24M | Oscillator:Oscillator_SMD_SeikoEpson_SG210-4Pin_2.5x2.0mm | CMOS Crystal Oscillator SPXO |  | SG-210STF 24M |  |  | https://www.digikey.com/product-detail/en/epson/SG-210STF-24.0000ML3/SER4323CT-ND/7932310
Y1, Y2, | 2 | 12MHz | Crystal:Crystal_SMD_3225-4Pin_3.2x2.5mm | Four pin crystal, GND on pins 2 and 3 |  | X322512MSB4SI

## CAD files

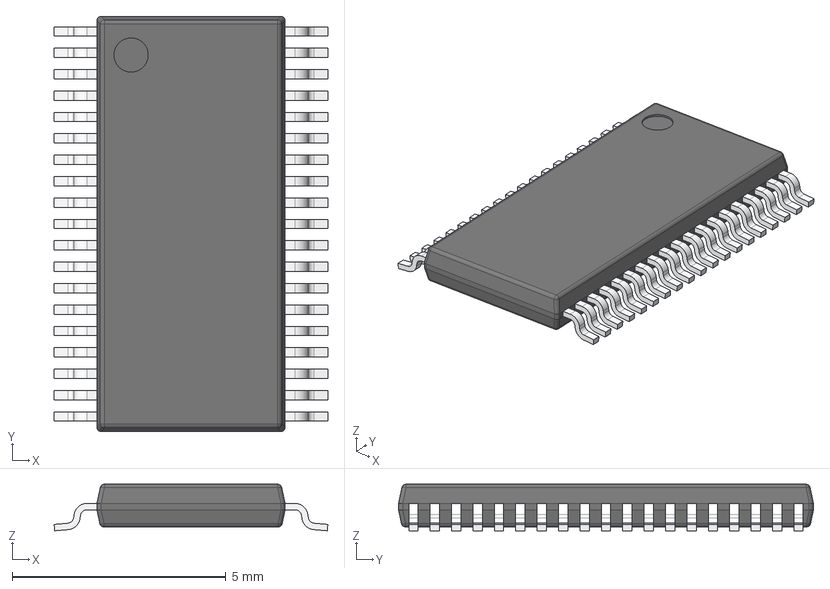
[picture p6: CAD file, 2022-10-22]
mark-II-production/shapes3D/TAS5806MD.stp
6.40 x 9.70 x 1.09 mm
BODY-TSSOP
LEAD-TSSOP x 38
PIN1
DAP

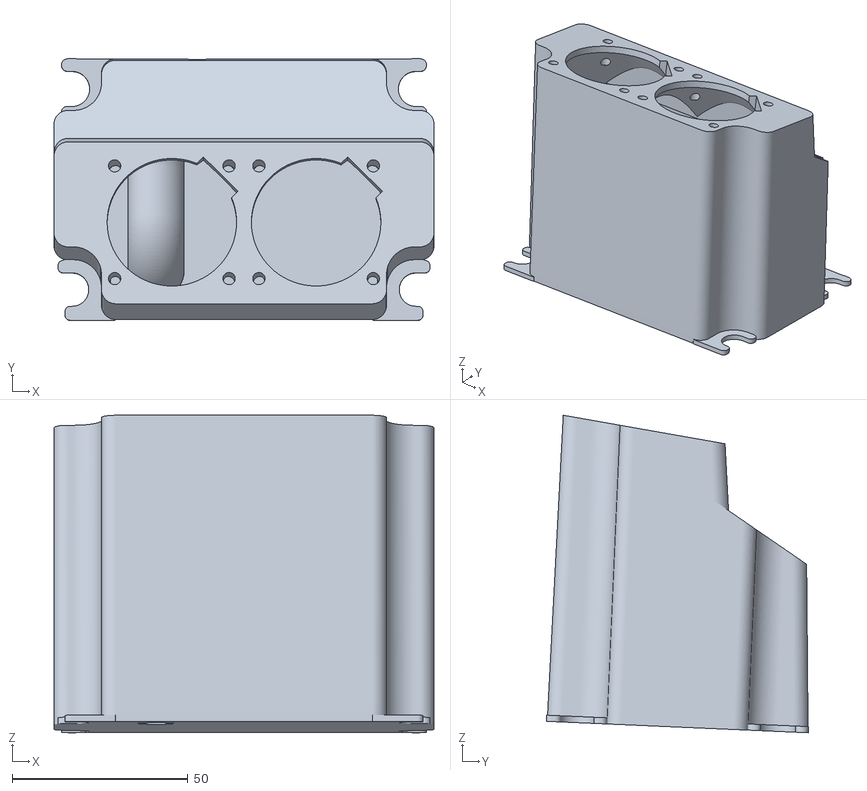
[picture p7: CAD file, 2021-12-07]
mark-II-Rpi-devkit/Mechanical CAD/SJ230/MKII Audio Chamber r9.STL
108.0 x 74.5 x 90.2

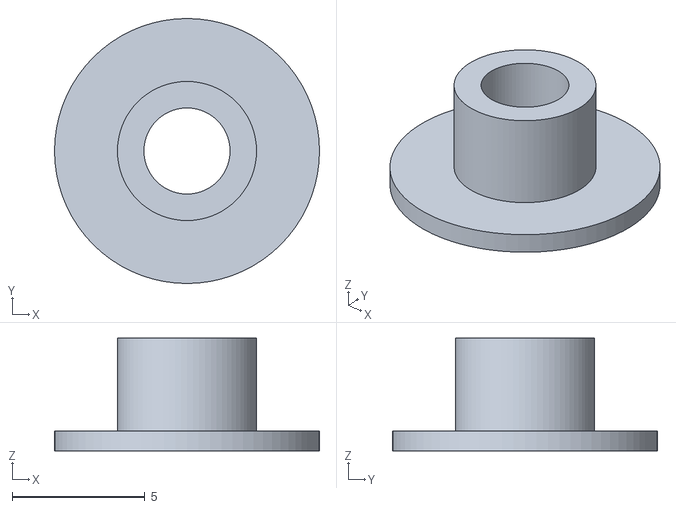
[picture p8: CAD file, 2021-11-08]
mark-II-Rpi-devkit/Mechanical CAD/SJ240/MKII AC spacer r2.STL
10.0 x 10.0 x 4.25

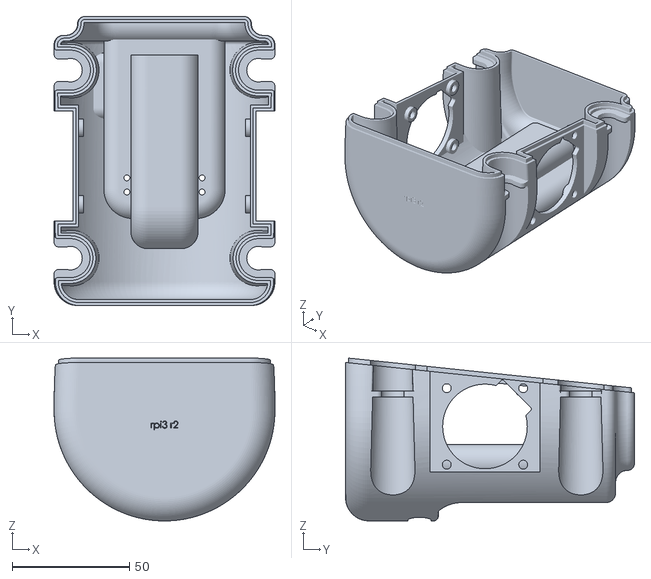
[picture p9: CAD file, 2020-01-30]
mark-II-rpi-ots/CAD/STL/MIIr_AC_pi3_r2.1.STL
94.0 x 123.0 x 69.3

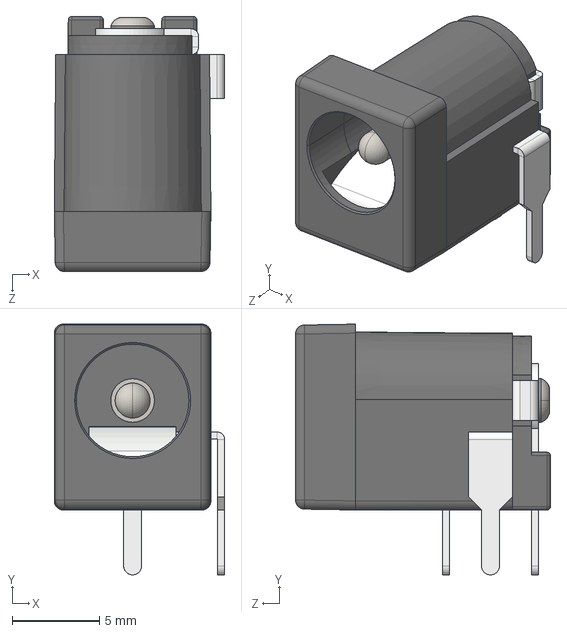
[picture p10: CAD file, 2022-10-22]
mark-II-production/shapes3D/DC Power Jack 5.5mm x 2.1mm.STEP
9.77 x 14.4 x 14.6 mm

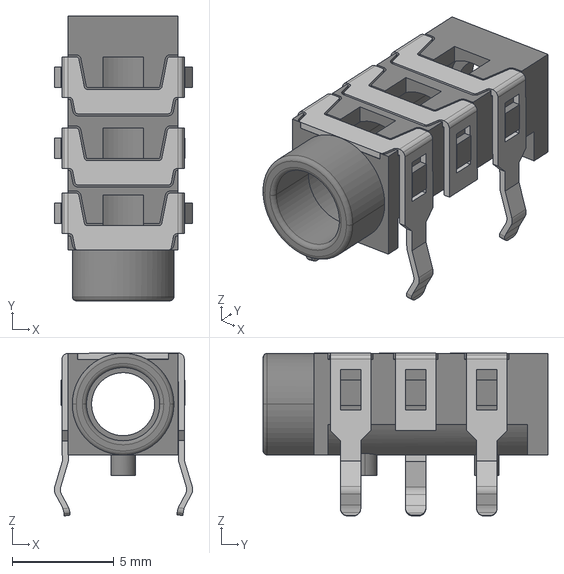
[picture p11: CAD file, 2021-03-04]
mark-II-Rpi-devkit/KiCAD/SJ201-Raspberry Pi 4 Daughterboard/shapes3D/TRS Jack.step
6.81 x 14.0 x 8.02 mm

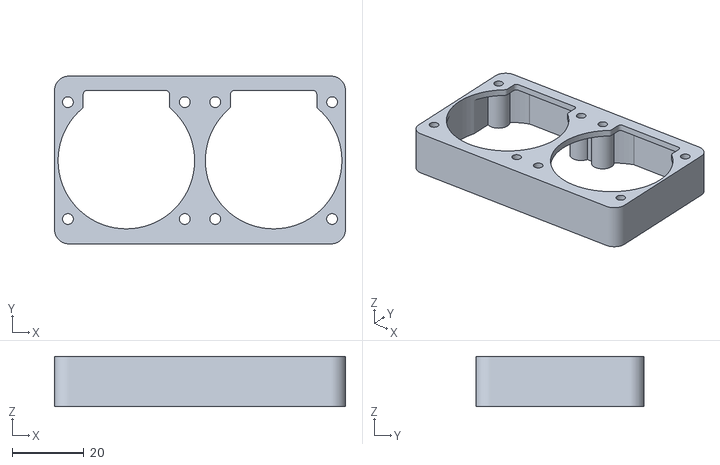
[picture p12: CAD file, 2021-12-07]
mark-II-Rpi-devkit/Mechanical CAD/SJ230/MKII speaker_spacer r9.STL
81.0 x 46.7 x 14.0

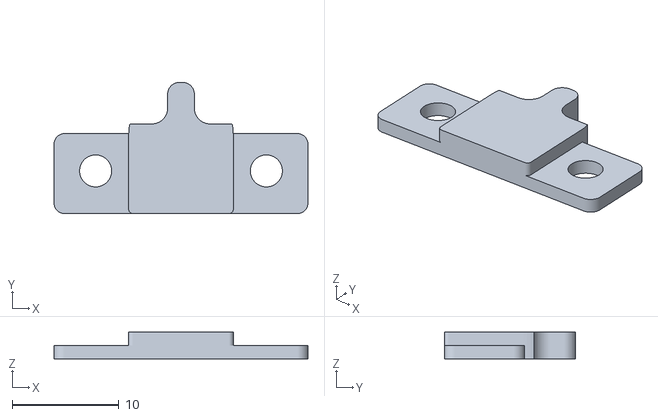
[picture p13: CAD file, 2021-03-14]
mark-II-Rpi-devkit/Mechanical CAD/SJ240/UM2_MKII wire holder r9.stl
23.8 x 12.3 x 2.50

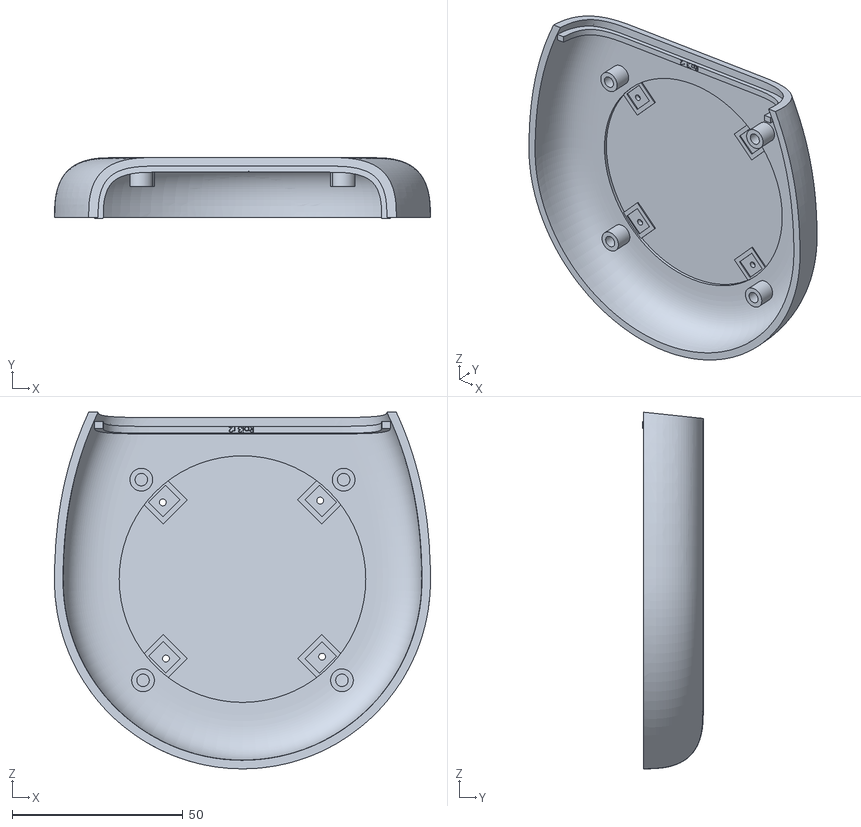
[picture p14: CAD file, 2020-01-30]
mark-II-rpi-ots/CAD/STL/MIIr_top_pi3_r2.STL
110.0 x 17.8 x 104.3

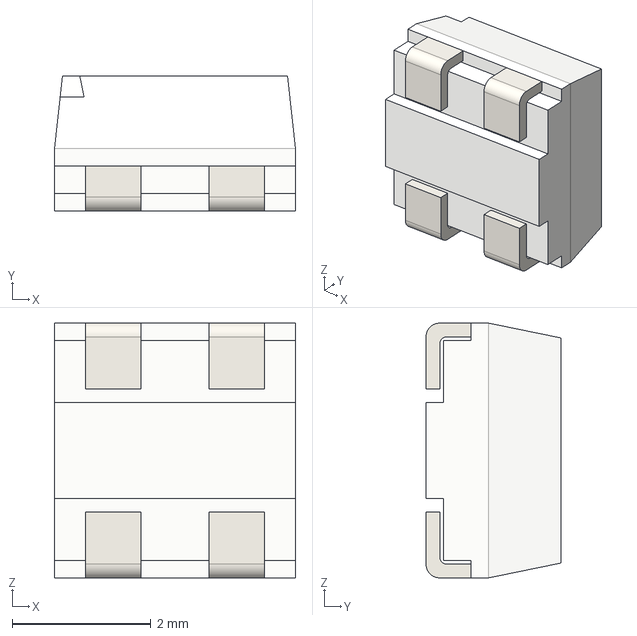
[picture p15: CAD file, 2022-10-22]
mark-II-production/shapes3D/SMD WS2812B Mini.step
3.48 x 1.95 x 3.68 mm

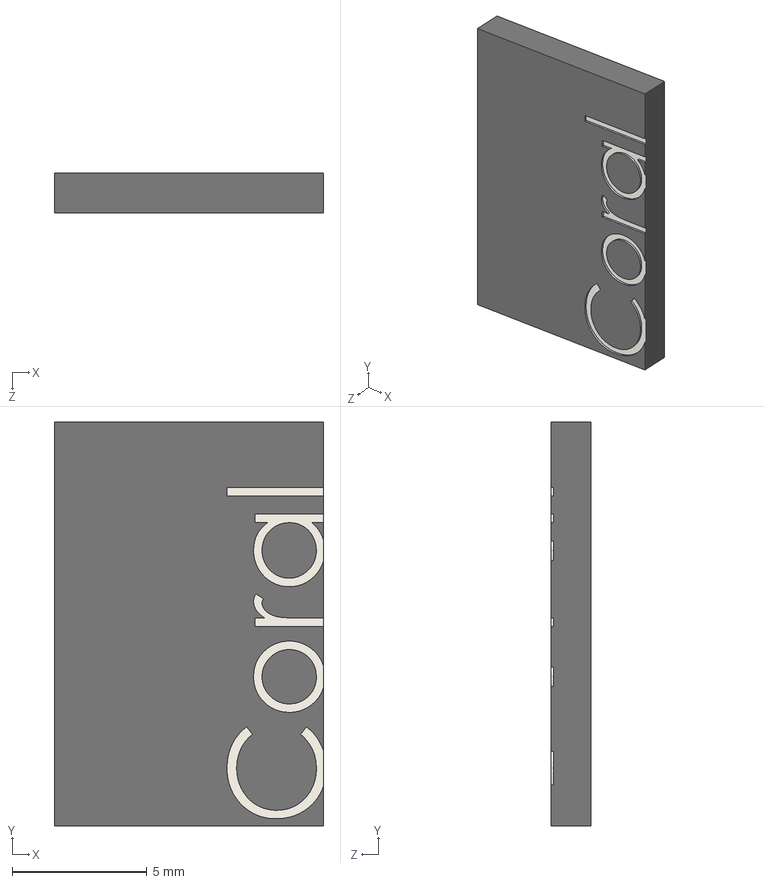
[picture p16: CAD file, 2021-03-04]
mark-II-Rpi-devkit/KiCAD/SJ201-Raspberry Pi 4 Daughterboard/shapes3D/CoralTPU.step
10.0 x 15.0 x 1.50 mm

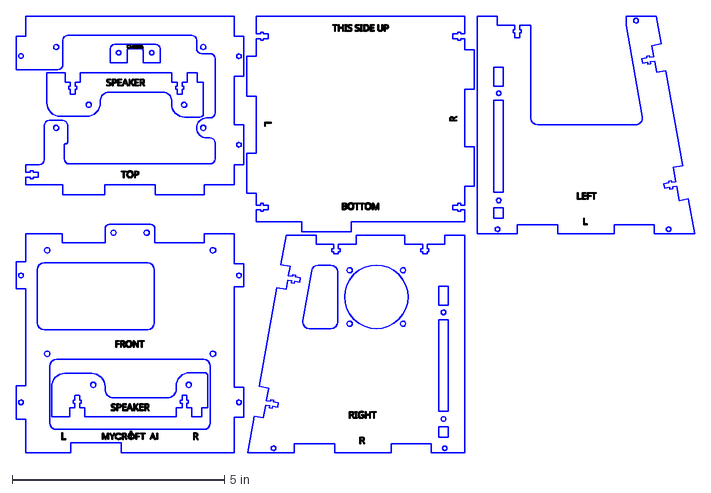
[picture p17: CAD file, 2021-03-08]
mark-II-Rpi-devkit/Mechanical CAD/SJ230/SJ230 lasercut v3 1-06-20.dxf
16.0 x 10.3 in

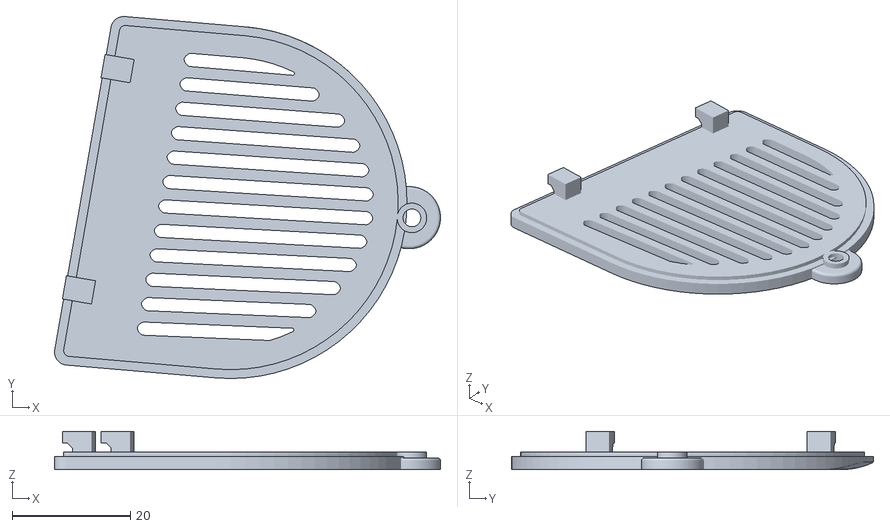
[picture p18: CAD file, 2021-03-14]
mark-II-Rpi-devkit/Mechanical CAD/SJ240/UM2_MkII Door r9.stl
65.3 x 61.3 x 6.50

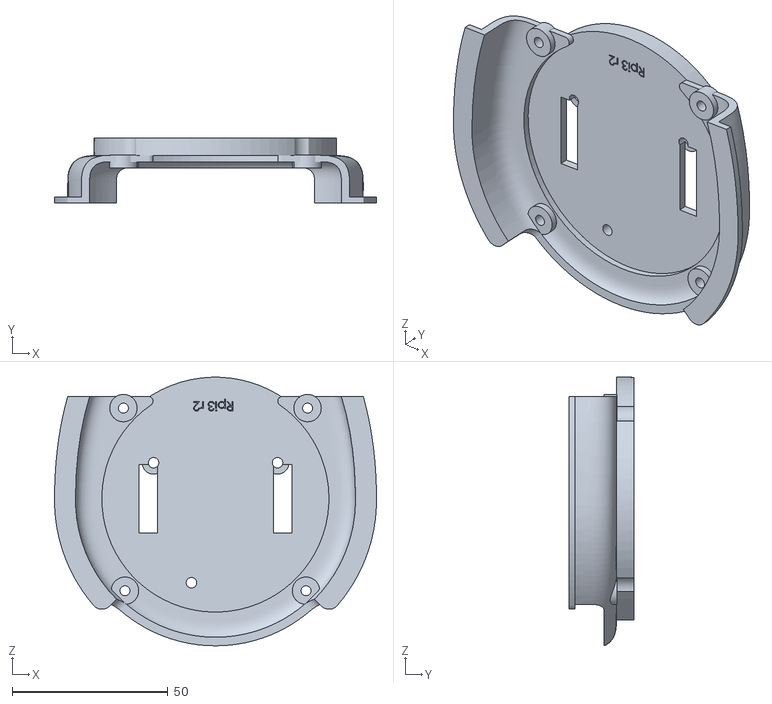
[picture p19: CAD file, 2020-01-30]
mark-II-rpi-ots/CAD/STL/MIIr_top_part2_pi3_r2.STL
103.5 x 21.0 x 86.4

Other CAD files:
mark-II-Rpi-devkit/KiCAD/SJ201-Raspberry Pi 4 Daughterboard/shapes3D/TAS5806MD.step
mark-II-Rpi-devkit/KiCAD/SJ201-Raspberry Pi 4 Daughterboard/shapes3D/DC Power Jack 5.5mm x 2.1mm.step
mark-II-Rpi-devkit/Mechanical CAD/SJ240/MKII Camera Shutter 3 r9.stl
mark-II-rpi-ots/CAD/STL/MIIr_AC_front_pi3_r2.1.STL
mark-II-Rpi-devkit/Mechanical CAD/SJ240/MKII Audio Chamber r9.stl
mark-II-Rpi-devkit/Mechanical CAD/SJ240/MKII Back r9.stl
mark-II-Rpi-devkit/Mechanical CAD/SJ240/MKII Camera Shutter 1 r9.stl
mark-II-Rpi-devkit/Mechanical CAD/SJ240/MKII Camera Shutter 2 r9.stl
mark-II-Rpi-devkit/Mechanical CAD/SJ240/MKII Center Button R9.stl
mark-II-Rpi-devkit/Mechanical CAD/SJ240/MKII Display Bezel R9.stl
mark-II-Rpi-devkit/Mechanical CAD/SJ240/MKII Display Housing r9.stl
mark-II-Rpi-devkit/Mechanical CAD/SJ240/MKII Grill r9.stl
mark-II-Rpi-devkit/Mechanical CAD/SJ240/MKII Top r9.stl
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

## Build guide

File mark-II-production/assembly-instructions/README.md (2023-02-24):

# Mark II Assembly

1. [Assemble Speaker](./speaker.md)
2. [Assemble Top](top.md)
3. [Assemble Display](display.md)
4. [Assemble Body](body.md)

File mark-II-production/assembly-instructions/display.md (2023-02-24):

# AS293 Display & Grill Assembly:

## Parts: 
-   SJ250-17 Display Housing X 1
-   SJ250-02 Grill X 1
-   SJ250-03 Grill Clip R X 1
-   SJ250-04 Grill Clip L X 1
-   SJ250-19 Camera Shutter Slider X 1
-   SJ250-18 Camera Shutter X 1
-   SJ227 Camera X 1
-   SJ225 4.3" Display X 1
-   SJ246 Display Cable X 1
-   SJ245-6 m2.5x6mm thread screw X 4
-   SJ245-8 m2.5x8mm Thread Screw X 4
-   SJ246-6 m2.5x6mm Flat Machine Screw X 6
-   SJ247 Ferrit Bead X 1
-   SJ260-DC RF EMI Shielding Tape (Die Cut) X 1
-   SJ262-2 EMI Shielding Tape 2\"x2\" X 1
-   SJ277 Electrical Tape X 1
-   SJ262 Plastic Adhesive

## Tools: 
-   PH1 Driver
-   Pointy Tweezers
-   X-Acto Knife
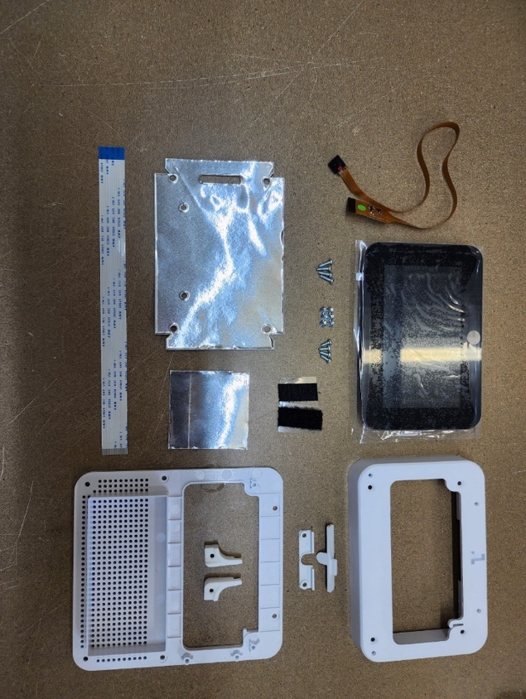
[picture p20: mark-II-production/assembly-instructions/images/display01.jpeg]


### Steps:
1.  Take *SJ225 4.3" Display* and SJ227 Camera and plug both into
    display and camera test jig in and run test while pointing camera at
    something. The *SJ225 4.3" Display* should show the Mycroft logo
    shown below. If the screen remains black, move Display to defective
    parts bin for further review, and start test again with another
    display to assess camera. If camera fails to post a picture, place
    in defective parts bin and restart test with another *SJ227 Camera*




2.  Unplug *SJ225 4.3" Display* and SJ227 Camera remove protective
    covers from 4 corner stand offs and the upper left center stand off
    as shown and set aside.

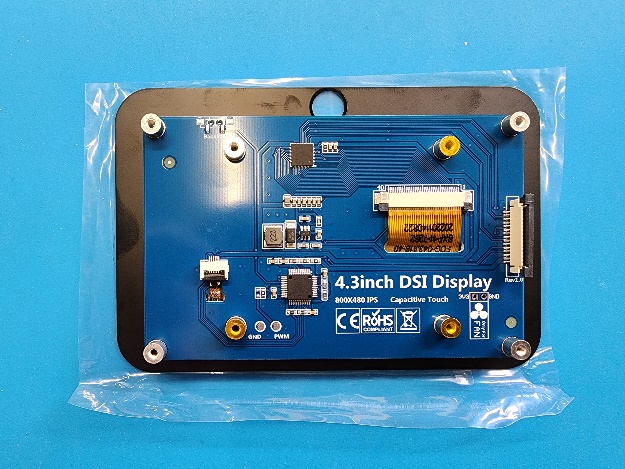
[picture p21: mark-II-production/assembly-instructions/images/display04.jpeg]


3.  Install the *SJ250-19 Camera Shutter Slider* on *SJ250-17 Display
    Housing* as pictured and Slide to one side.

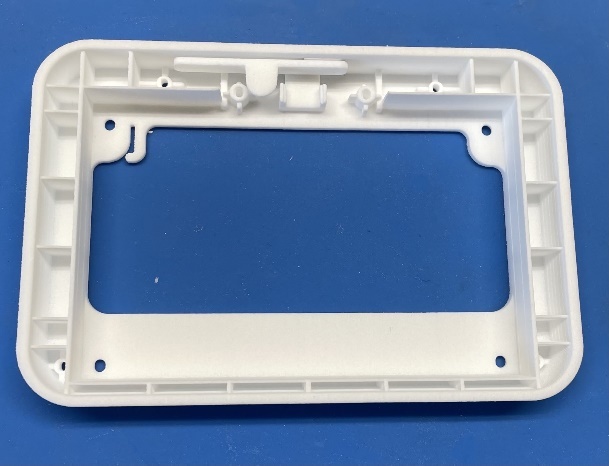
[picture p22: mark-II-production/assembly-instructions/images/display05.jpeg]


4.  Peel the backing off *SJ227 Camera* and stick to *SJ250-17 Display
    Housing* than remove protective cover on *SJ227 Camera*

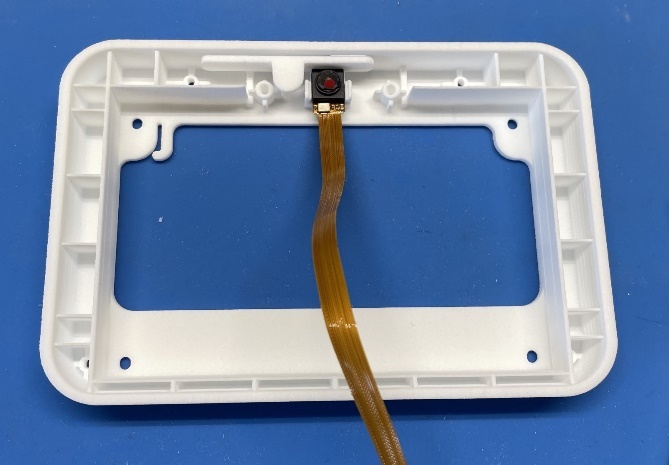
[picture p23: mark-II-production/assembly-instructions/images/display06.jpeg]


5.  Center *SJ250-19 Camera Shutter Slider* and take *SJ250-18 Camera
    Shutter* and slide it straight down over *SJ227 Camera* and secure
    with (2) *SJ245-6 m2.5x6mm Thread Screws.*

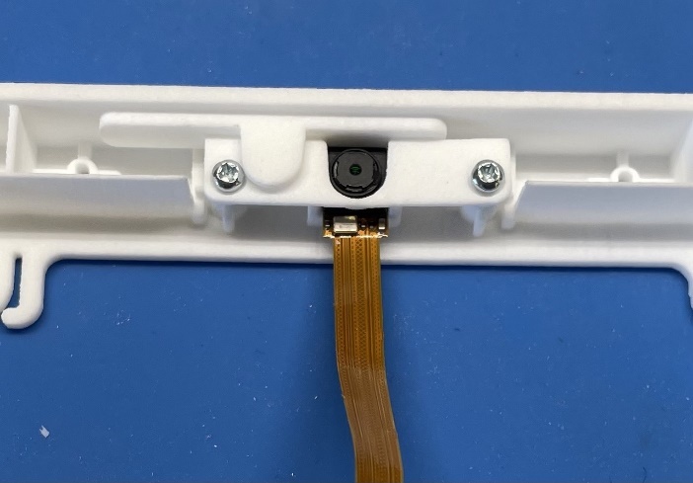
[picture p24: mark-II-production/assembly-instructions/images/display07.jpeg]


6.  *Use Jig to crease* SJ260-DC RF EMI Shielding Tape (Die Cut) *and
    cut along lines
    shown*

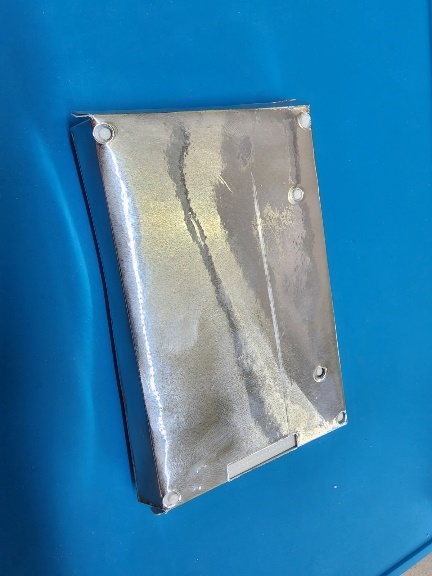
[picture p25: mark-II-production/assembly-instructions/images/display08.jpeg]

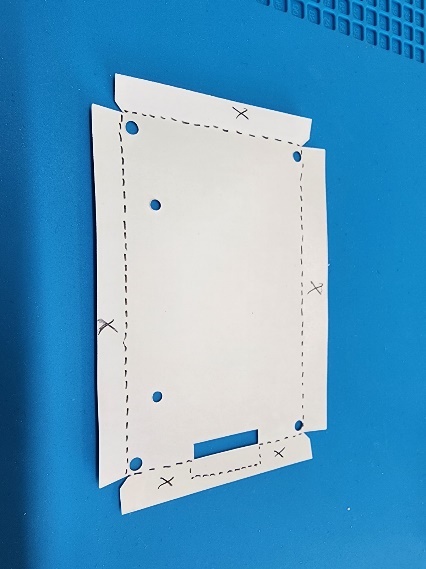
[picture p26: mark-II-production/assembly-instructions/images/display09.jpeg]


7.  Remove backing from shielding as shown

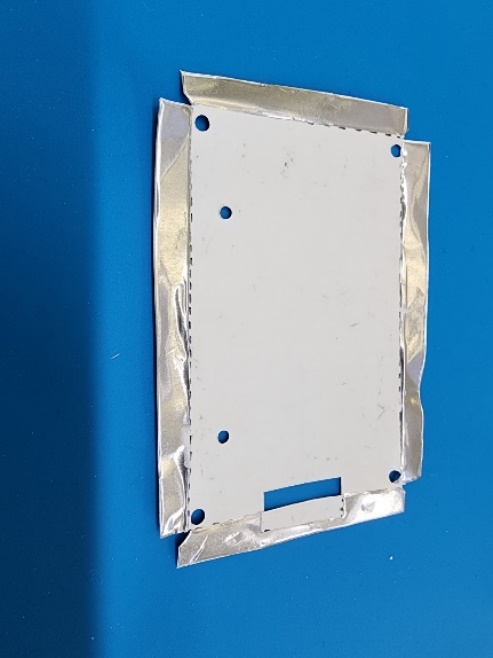
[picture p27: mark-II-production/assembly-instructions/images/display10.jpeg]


8.  Stick shielding down onto Display

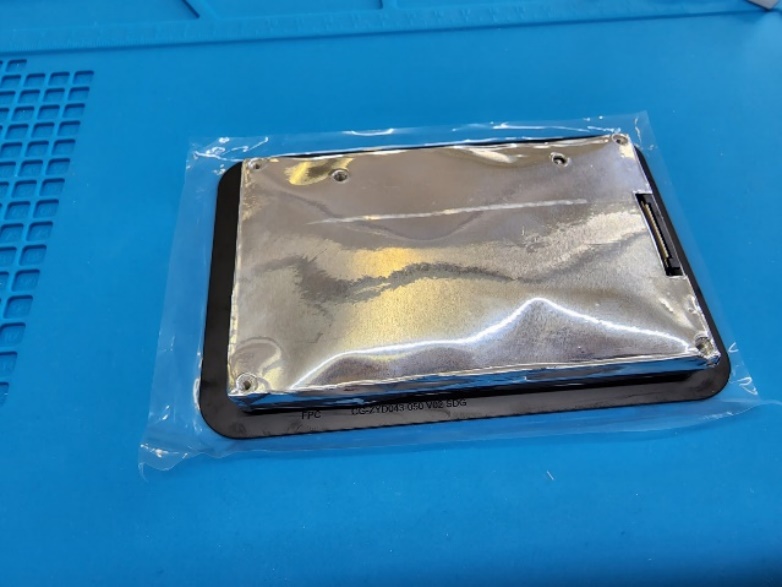
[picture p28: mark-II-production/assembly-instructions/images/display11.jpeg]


9.  Plug *SJ246 Display Cable* through slot into Assembly from step 6
    (The display cable contacts should face inwards) *A*dd *SJ247 Ferrit
    Bead.*

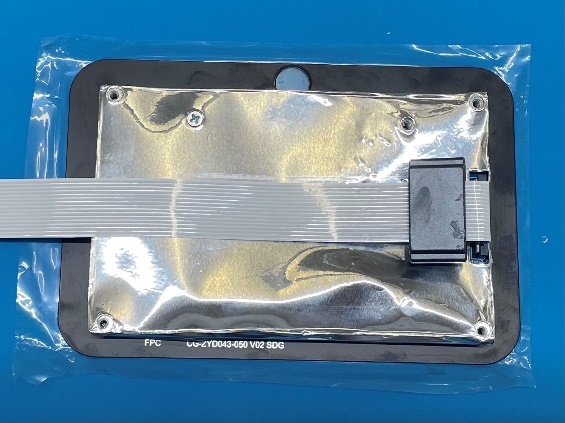
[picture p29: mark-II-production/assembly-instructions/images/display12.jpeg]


10. Take the SJ262-2 EMI Shielding Tape 2\"x2\" and stick down over
    bead, making sure it is folded over the edge of display.

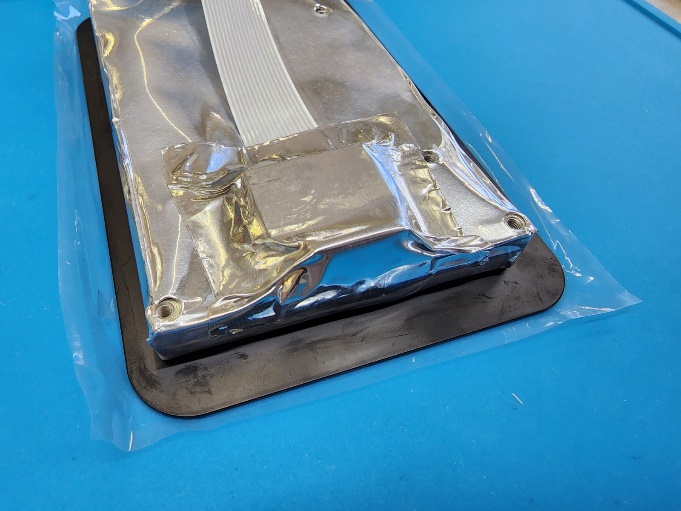
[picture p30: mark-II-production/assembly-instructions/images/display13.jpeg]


11. Install (1) *M2.5x6mm flat machine screw* through *RF Shielding* to
    the left center hole of the display for grounding.

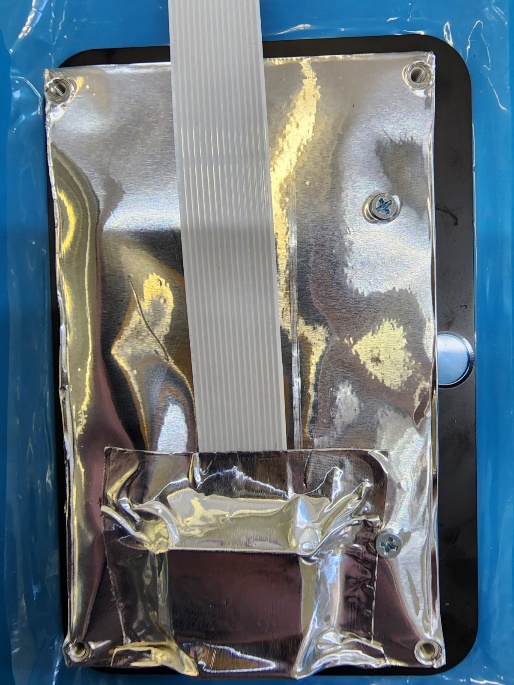
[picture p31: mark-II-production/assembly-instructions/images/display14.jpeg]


12. Cut a small Piece of SJ277 Electrical Tape about 1" long and place
    on shielding directly under the camera hole on the display, as shown

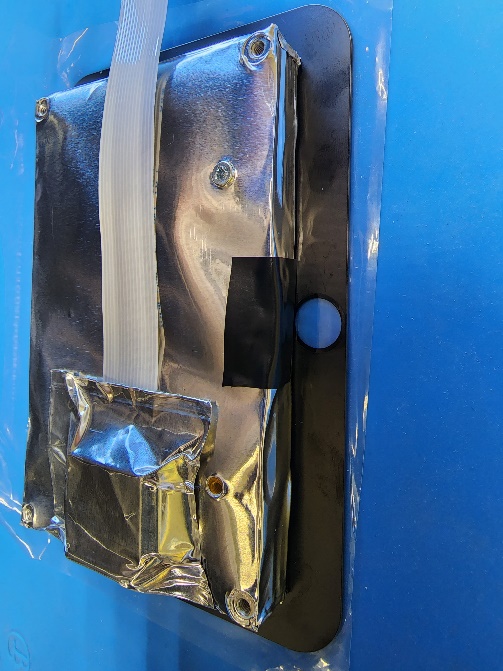
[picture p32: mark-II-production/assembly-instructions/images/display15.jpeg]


13. *Take SJ225 4.3" Display* and install into *SJ250-17 Display
    Housing* using (4) *SJ246-6 - m2.5x6mm Flat Machine Screws*

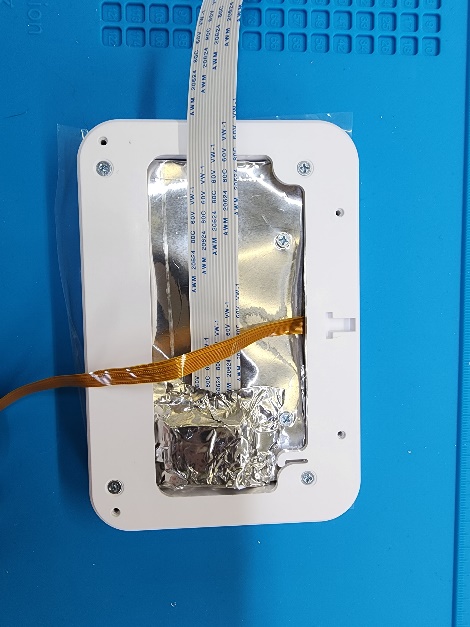
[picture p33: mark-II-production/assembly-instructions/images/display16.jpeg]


14. Feed *SJ227 Camera* through slot on top right of *SJ250-17 Display
    Housing*

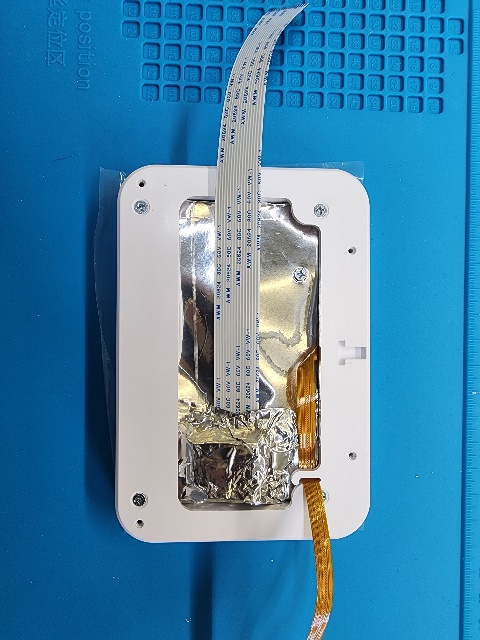
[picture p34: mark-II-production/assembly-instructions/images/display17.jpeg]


15. Using the assembly for step 5, attach *SJ250-02 Grill to the back
    using* (4) *SJ245-8 m2.5x8mm Thread Screws,* Screwed. Install in an
    X pattern.

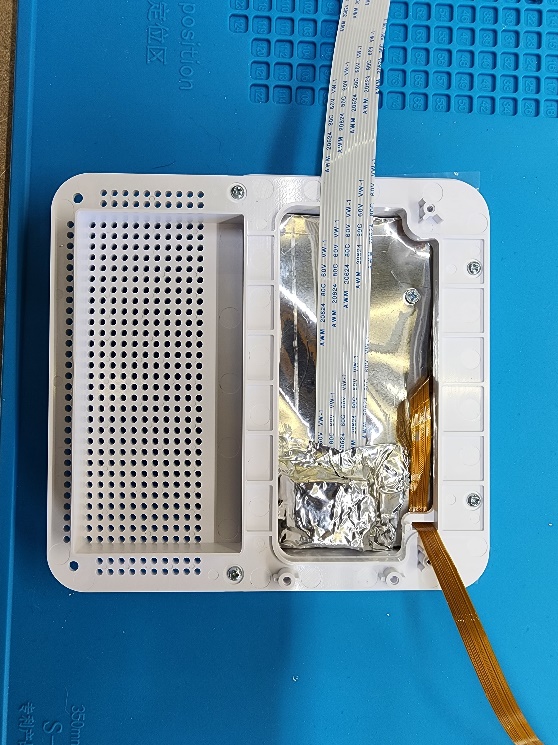
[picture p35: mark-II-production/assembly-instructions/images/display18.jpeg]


16. Using the assembly from step 6, place a small amount of *SJ262
    Plastic Adhesive* at the base of the grill clip mount point and
    attach *SJ250-03 Grill Clip R* and *SJ250-04 Grill Clip L with* (2)
    *SJ245-6 m2.5x6mm thread screws* as shown

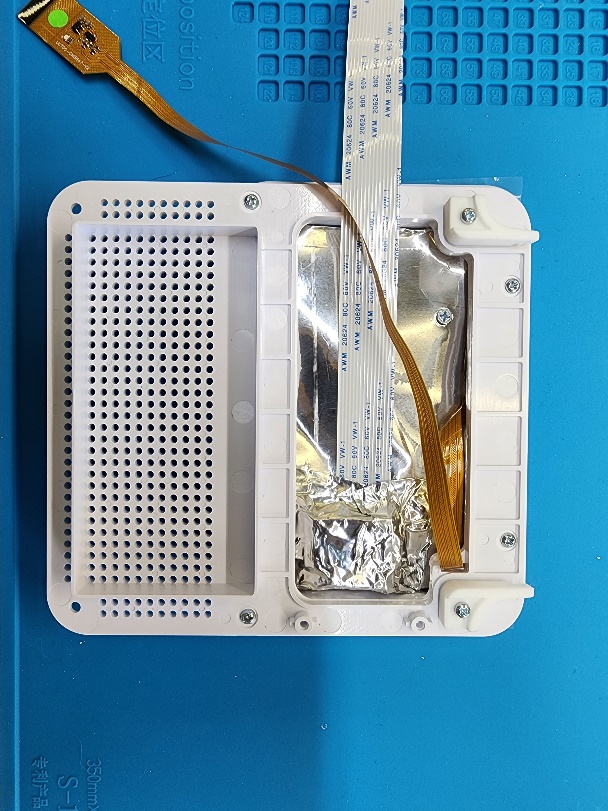
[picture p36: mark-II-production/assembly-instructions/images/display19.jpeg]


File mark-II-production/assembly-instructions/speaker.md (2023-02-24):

# AS292 Loudspeaker Assembly:

## Parts: 
-   SJ250-13 Audio Chamber F X 1
-   SJ250-14 Audio Chamber R X 1
-   SJ250-15 Audio Chamber Port X 1
-   SJ205 Speaker Driver Assembly X 2
-   SJ245-6 m2.5x6mm Thread Screw X 8
-   SJ245-8 m2.5x8mm Thread Screw X 8
-   SJ261 Hot Glue

## Tools:
-   PH1 Screwdriver
-   Needle Nose Plyers
-   Hot Glue Gun
-   Loudspeaker Jig 1
-   Loudspeaker Jig 2

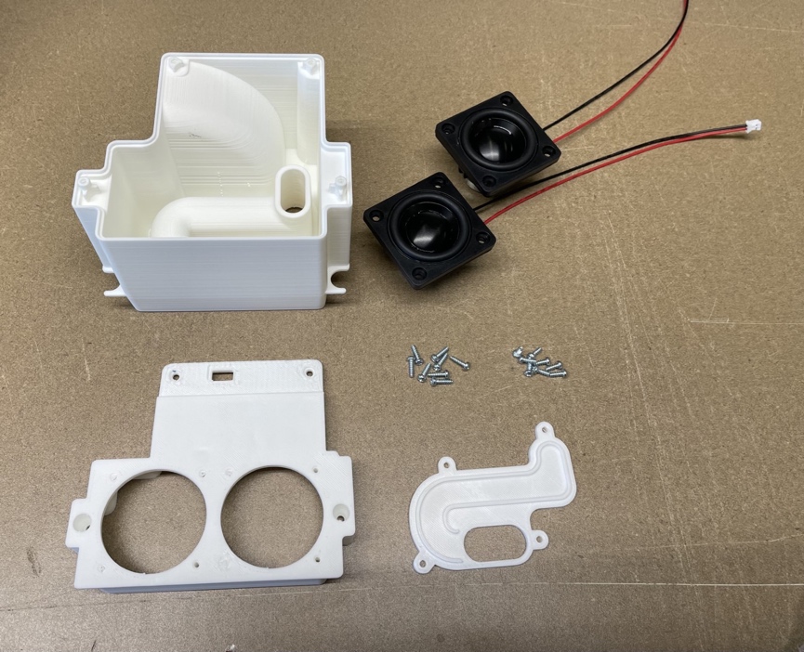
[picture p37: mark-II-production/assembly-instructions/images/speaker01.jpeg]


Step:

1.  Install (2) *SJ205 Speaker Driver Assemblies* into *SJ250-13 Audio
    Chamber F* situating the wires as shown below. Feed wires through
    top hole.

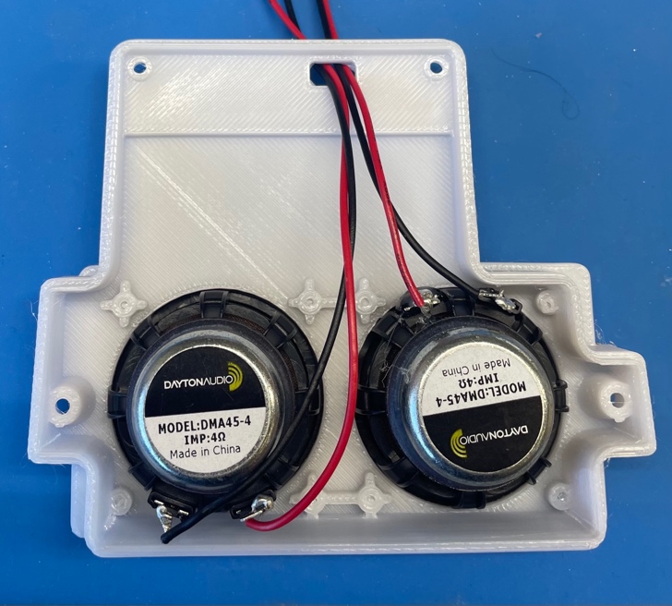
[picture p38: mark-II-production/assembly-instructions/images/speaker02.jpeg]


2.  Place *SJ250-14 Audio Chamber R* into *Loudspeaker Jig 1. P*lace
    assembly from Step 2 onto *SJ250-14 Audio Chamber R.*

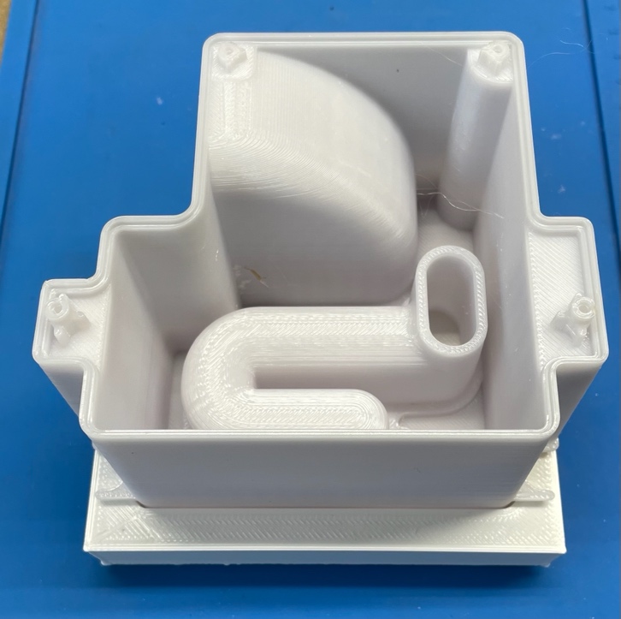
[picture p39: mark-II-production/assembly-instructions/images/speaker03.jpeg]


3.  Install (2) *SJ205 Speaker Driver Assemblies* into *SJ250-13 Audio
    Chamber F* using (8) *SJ245-8 m2.5x8mm Thread Screws*

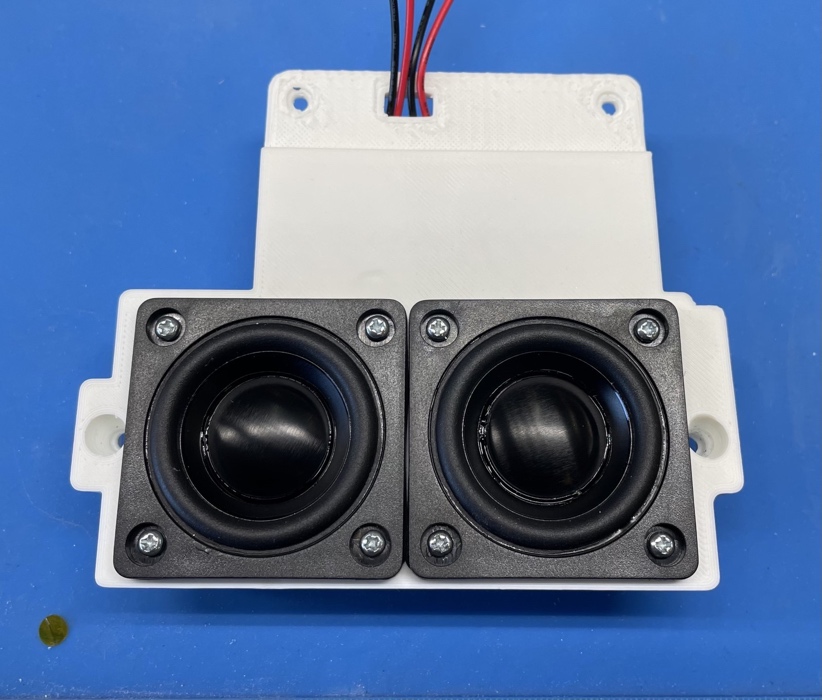
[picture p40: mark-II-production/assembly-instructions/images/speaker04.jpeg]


4.  Attach assembly from step 1 to *SJ250-14 Audio Chamber R* using (4)
    *SJ245-6 m2.5x6mm Thread Screws.* Use *SJ261 Hot Glue* to seal.

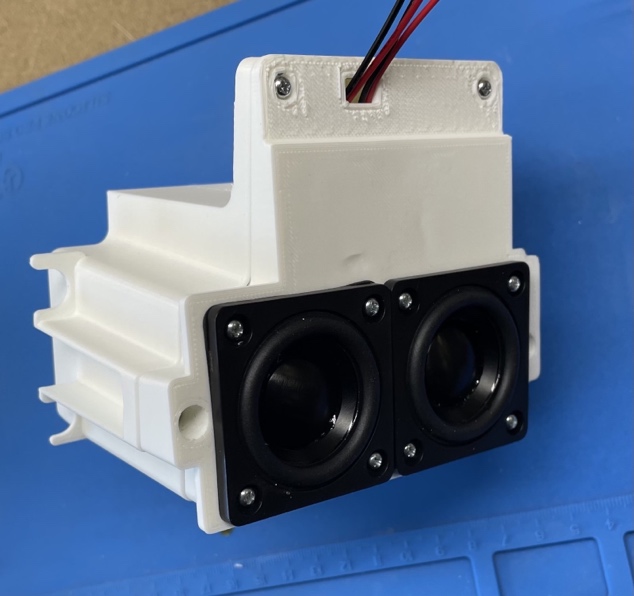
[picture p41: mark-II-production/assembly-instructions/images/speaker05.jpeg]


5.  Apply *SJ261 Hot Glue* around *AS292 Loudspeaker Assembly where
    SJ250-13 Audio Chamber F* and *SJ250-14 Audio Chamber R* meet.

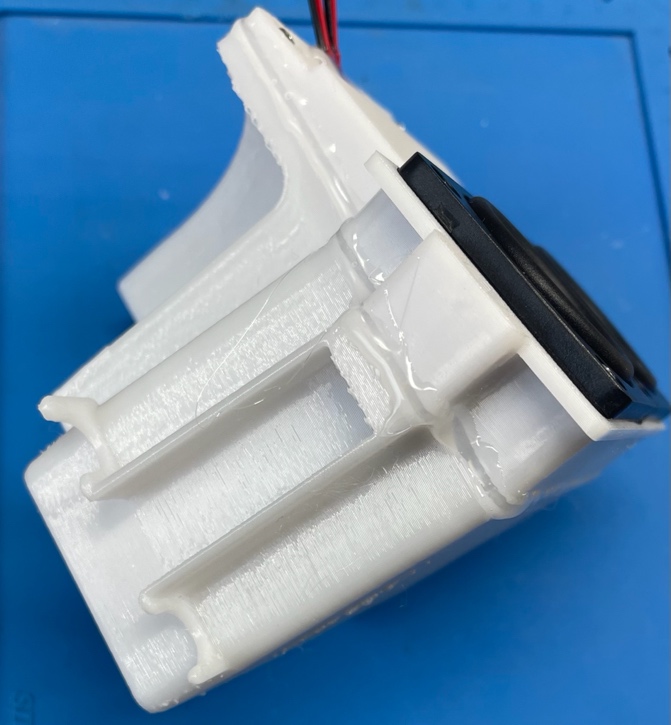
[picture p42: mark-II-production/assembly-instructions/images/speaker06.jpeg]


6.  Using the assembly form step 2, attach *SJ250-15 Audio Chamber Port*
    using (4) m2.5x6mm Thread Screws

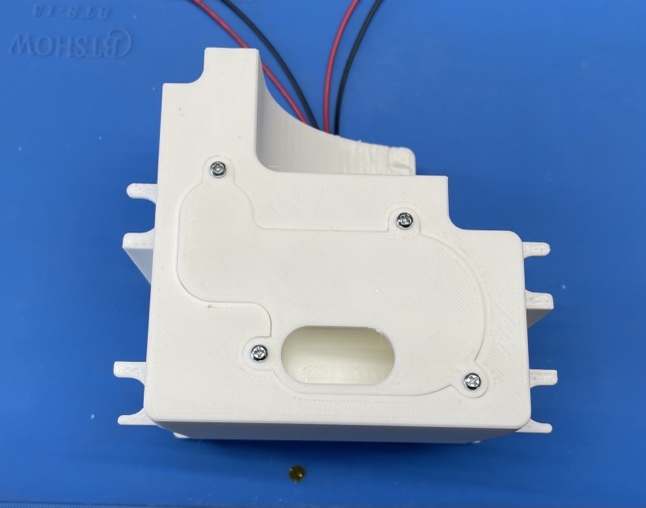
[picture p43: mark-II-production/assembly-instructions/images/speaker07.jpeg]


7.  Apply *SJ261 Hot Glue* around *SJ250-15 Audio Chamber Port* to seal.

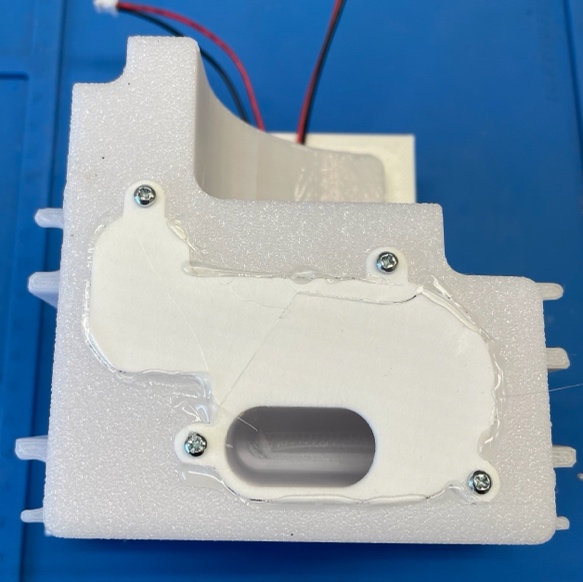
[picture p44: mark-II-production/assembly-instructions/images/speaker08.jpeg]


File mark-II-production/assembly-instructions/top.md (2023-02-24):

# AS291 Top Assembly:

## Parts: 
-   SJ250-08 Top X 1
-   SJ250-09 Center Button X 1
-   SJ250-11 Mute Switch X 1
-   SJ250-10 Volume Button X 1
-   SJ250-07 RPI Mount X 1
-   SJ201 Mycroft Audio Pi Hat X 1
-   SJ220-01 Raspberry Pi 4 2GB X 1
-   SJ220-02 Raspberry Pi 4 Heatsinks X 1
-   SJ250-12 Microphone Gasket X 2
-   SJ242.2 PCB Grommets X 5
-   SJ245-6 m2.5x6mm Thread Screw X 5
-   SJ248 Nylon Plastic Washer M3 X 4

## Tools:
-   PH1 Screwdriver
-   Blunt Tweezers
-   Sharp Tweezers
-   RPI Jig

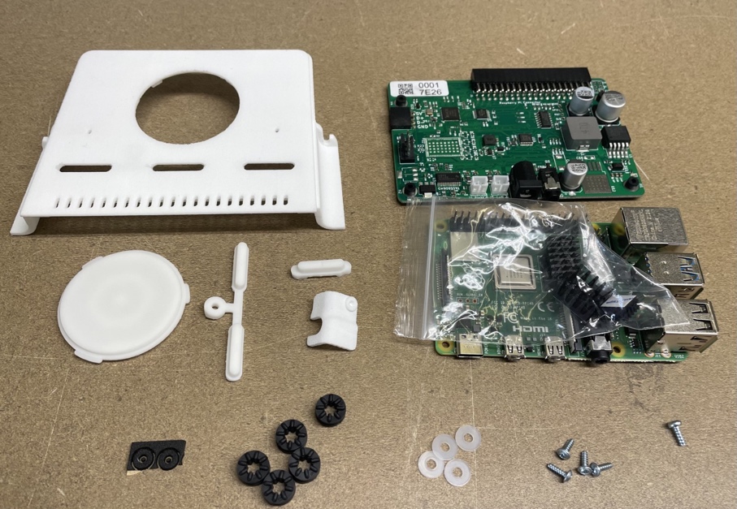
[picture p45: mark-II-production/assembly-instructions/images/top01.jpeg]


Step:

1.  Take *SJ250-08 Top* and place (2) *SJ250-12 Microphone Gaskets* on
    the bottom as shown.

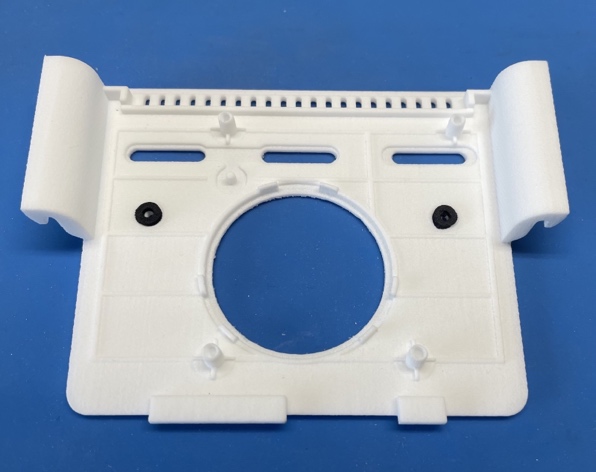
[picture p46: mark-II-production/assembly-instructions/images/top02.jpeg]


2.  Using the assembly from Step 1, place *SJ250-09 Center Button*,
    *SJ250-11 Mute Switch* and SJ250-*10 Volume Button* as shown. (Make
    sure *SJ250-11 Mute Switch* notch is facing middle of assembly)

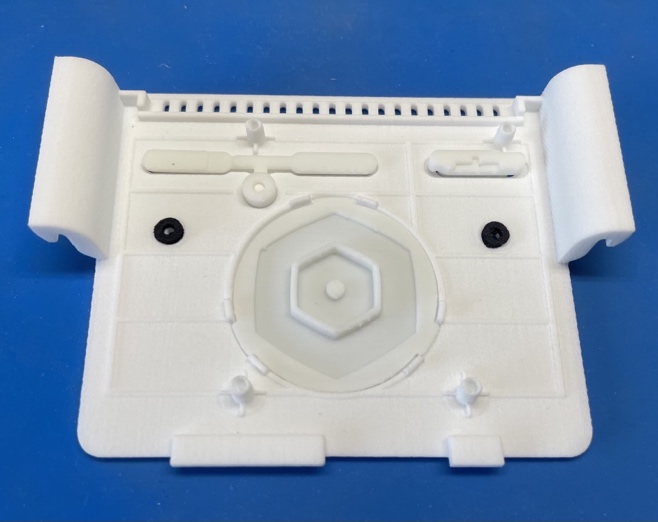
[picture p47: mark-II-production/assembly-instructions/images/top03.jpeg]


3.  Place *SJ250-07 RPI Mount* and *SJ220-01 Raspberry Pi 4 2GB* into
    *RPI Jig* as shown. Attach *RPI Mount* to *Raspberry Pi* using (1)
    *SJ245-6 m2.5x6mm Thread Screw.*

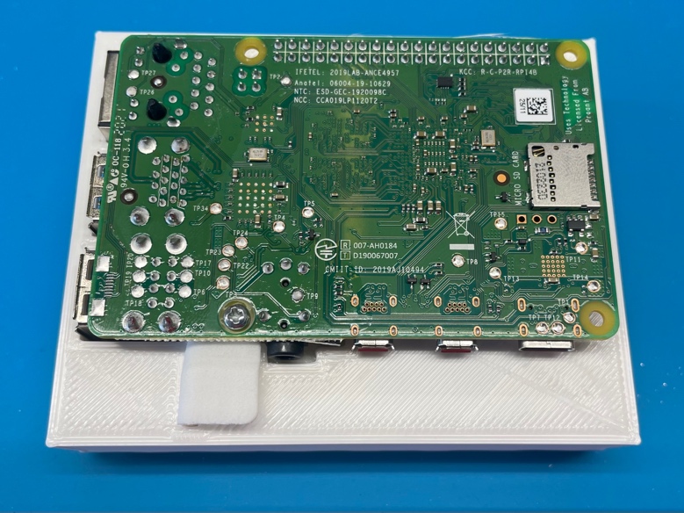
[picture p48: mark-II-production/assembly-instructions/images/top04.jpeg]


4.  Place *SJ220-02 Raspberry Pi 4 Heatsinks on SJ220-01 Raspberry Pi 4
    2GB* as shown. Install *SJ242.2 PCB Grommet on SJ250-07 RPI Mount.*

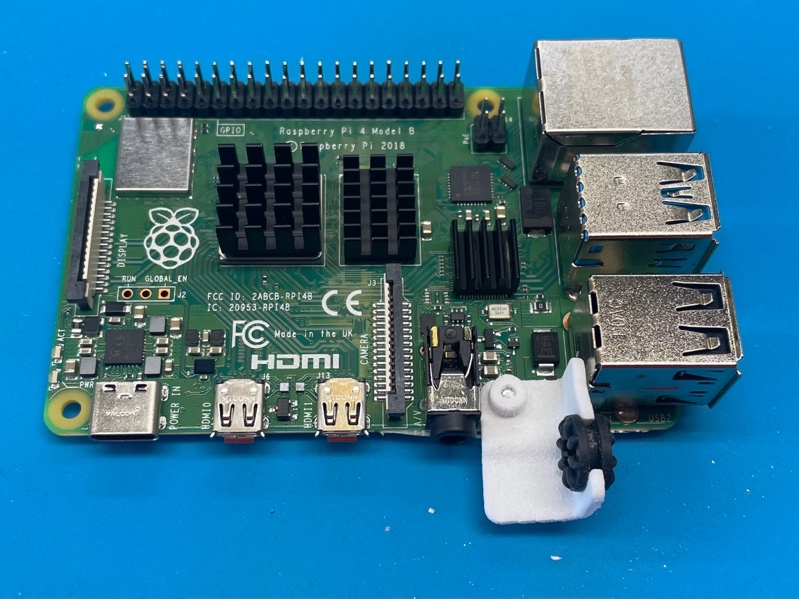
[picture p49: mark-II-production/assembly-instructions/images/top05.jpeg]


5.  Place (*4) SJ242.2 PCB Grommets into holes on SJ201 Mycroft Audio Pi
    Hat as shown.*

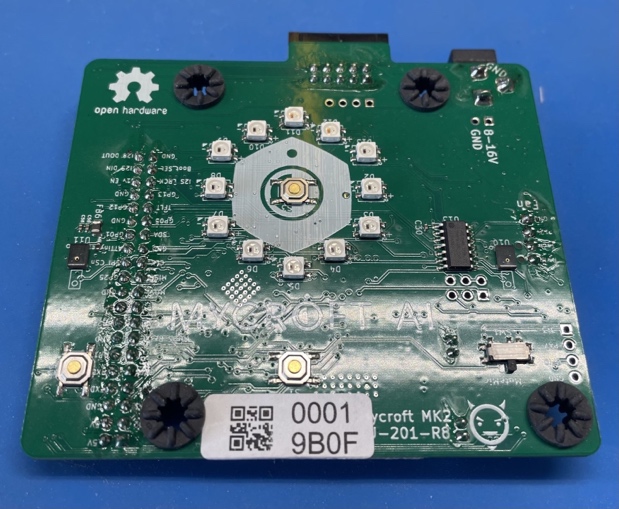
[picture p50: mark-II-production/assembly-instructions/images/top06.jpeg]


6.  Attach *SJ220-01 Raspberry Pi 4 2GB* on *SJ201 Mycroft Audio Pi Hat*
    using existing pins

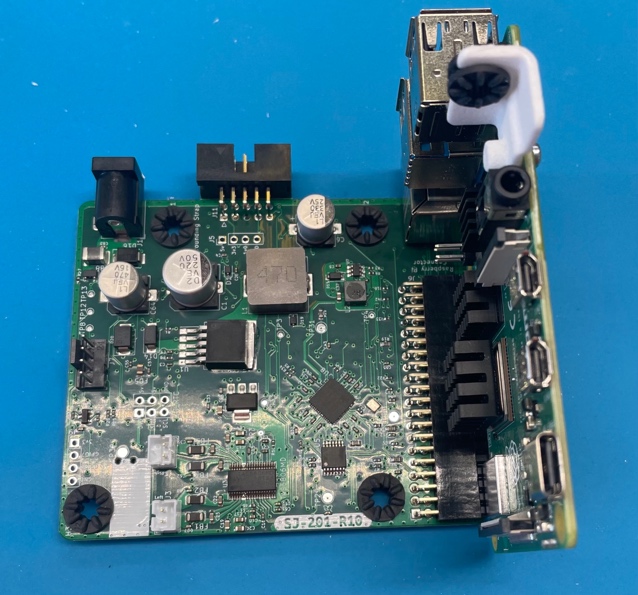
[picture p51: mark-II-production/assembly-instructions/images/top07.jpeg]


7.  *Using (4) SJ245-6 m2.5x6mm Thread Screws* and (4) *SJ248 Nylon
    Plastic Washers*, attach the *Assembly* from Step 6 to the *Top
    Cover Assembly* from Step 2 as shown. *(*Attach screws in an X
    pattern, and test slider switch after installing 2 of the 4 screws
    to verify alignment.)

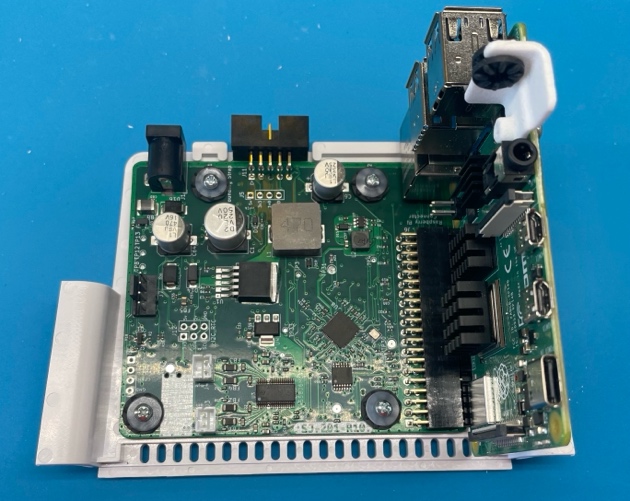
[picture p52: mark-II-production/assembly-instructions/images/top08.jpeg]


8.  Test all buttons and slider a final time.

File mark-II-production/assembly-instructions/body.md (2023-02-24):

# AS290 Body Assembly:
## Parts: 
-   AS291 Top Assembly X 1
-   AS292 Loudspeaker Assembly X 1
-   AS293 Display & Grill Assembly X 1
-   SJ250-01 Body X 1
-   SJ250-05A Boss Ext. R Assembly X 1
-   SJ250-06A Boss Ext. L Assembly X 1
-   SJ232.2 Black Speaker Grommets X 4
-   SJ222 Fan X 1
-   SJ245-10 m2.5x10mm Thread Screw X 4
-   SJ245-8 m2.5x8mm Thread Screw X 7
-   SJ241 Feet X 4
-   SJ243-8 m2.5x8mm Wafer Machine Screw X 2
-   SJ248 Nylon Plastic Washer X 3
-   SJ247 Ferrite Bead X 1
-   SJ263 Adhesive Velcro Loop
-   SJ264 Adhesive Velcro Hook
## Tools: 
-   PH1 Screwdriver
-   Pointy Tweezers
-   Body Assembly Jig

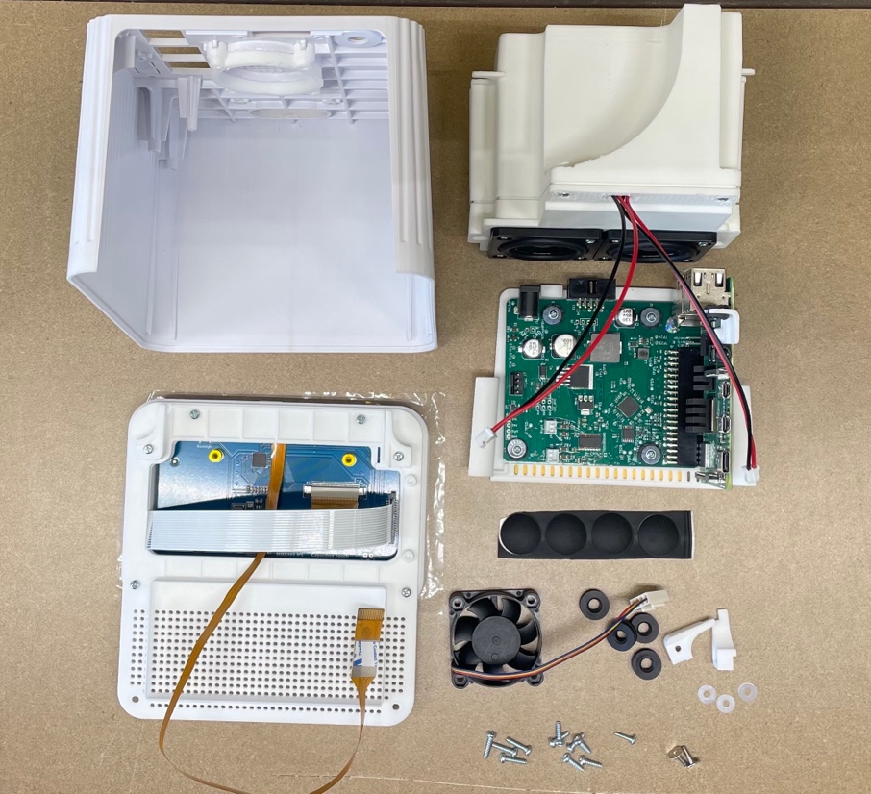
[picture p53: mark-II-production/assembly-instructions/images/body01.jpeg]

Step:

1.  Take the *SJ250-01 Body* and remove any burrs around the upper
    corners pictured below. See before and after pictures:

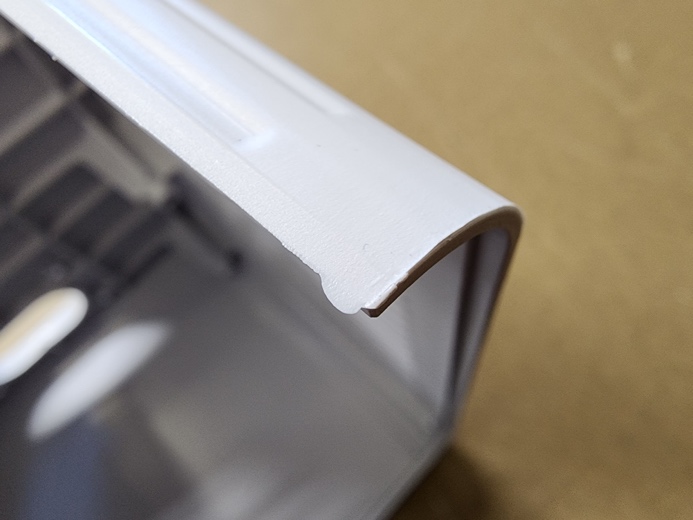
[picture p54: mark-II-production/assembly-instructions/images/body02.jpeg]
Before

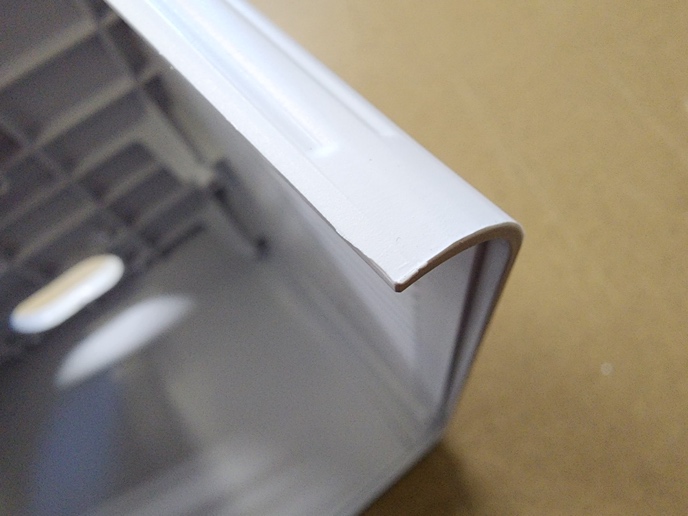
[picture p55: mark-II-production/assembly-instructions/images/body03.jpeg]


2.  Using (4) *SJ245-10 m2.5x10mm* Thread Screws install *SJ222 Fan on
    SJ250-01 Body* with the wire positioned towards the top of the
    assembly as shown

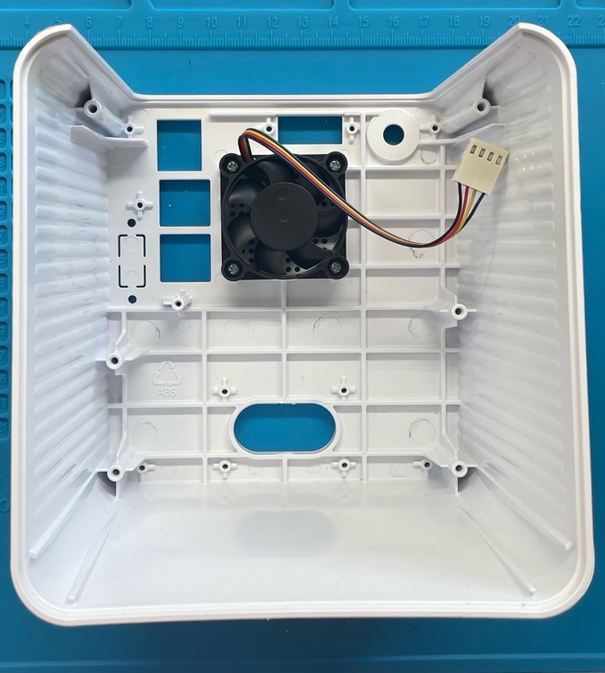
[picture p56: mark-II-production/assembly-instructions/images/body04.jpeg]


3.  Take *AS291 Top Assembly* and slide it into *SJ250-01 Body,* use (2)
    *SJ245-8 m2.5x8mm Thread Screws* to attach the *Top Assembly* to the
    B*ody* at top corners.

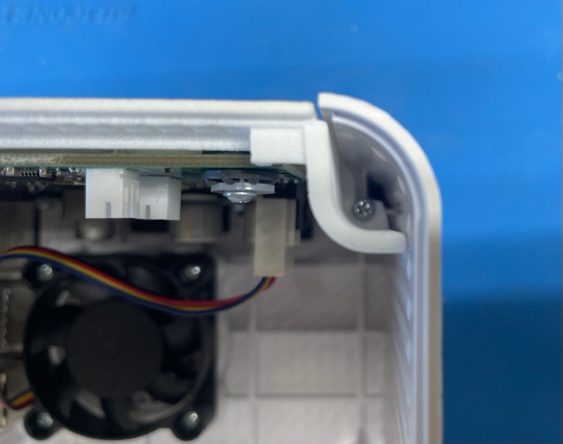
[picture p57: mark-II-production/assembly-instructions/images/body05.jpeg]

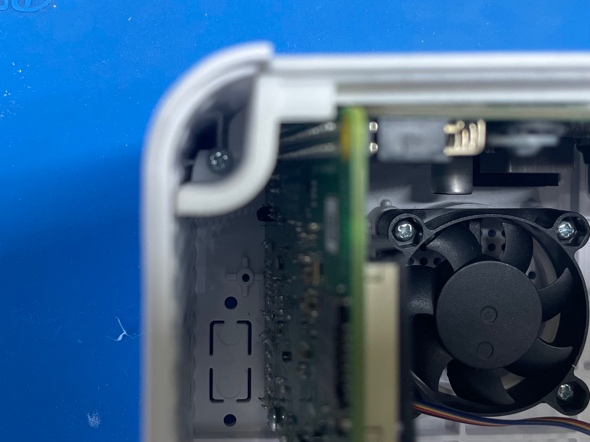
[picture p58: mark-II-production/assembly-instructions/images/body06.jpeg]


4.  Plug in fan

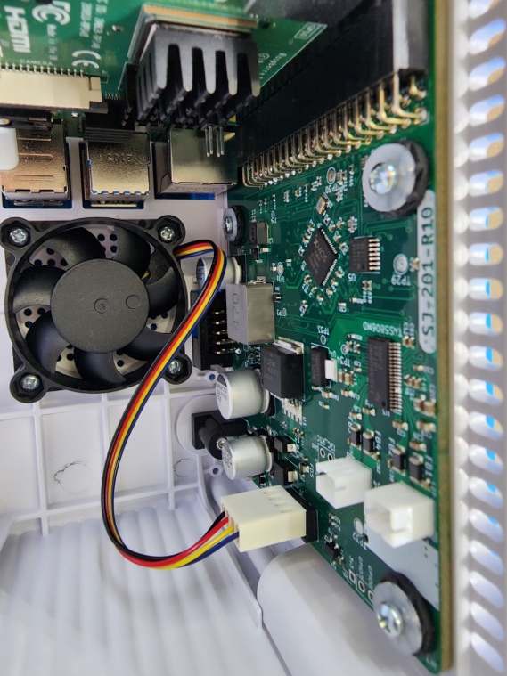
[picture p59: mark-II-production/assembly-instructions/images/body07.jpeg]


5.  Use (1) *SJ244-8 M2 x 8mm Thread Screw* and (1) *SJ248 Nylon Plastic
    Washer* to *secure SJ250-07 RPI Mount* to the *Body.*



6.  Locate *AS293 Display & Grill Assembly. Use* Body Assembly Jig to
    hold the Body and the Display & Grill Assembly. Locate the cable for
    *J227 Camera* and plug into *SJ220 Raspberry Pi Assembly* making
    sure to orient the cable in the correct direction.



7.  Locate *AS292 Loudspeaker Assembly,* place (4) *SJ232.2 Black
    Speaker Grommets* on the *Loudspeaker Assembly* as shown and plug
    in. The short cable should be plugged into the bottom plug and the
    long one into the top plug. (Long = Left channel)



8.  Move the *AS293 Display & Grill Assembly* to the left side and
    rotate the *AS292 Loudspeaker Assembly* into the body making sure
    the fan cable does not get caught on the upper right corner of the
    audio chambe*r.*




9.  Slide *AS292 Loudspeaker Assembly* into SJ250-01 Body. Place (2)
    *SJ248 Nylon Plastic Washers* on each of the upper holes on the
    *AS292 Loudspeaker Assembly* using tweezers, than screw down
    with (2) *SJ245-8 m2.5x8mm Thread Screws.*




10. Locate *Boss Ext. R Assembly* and *Boss Ext. L Assembly* (If
    J*210-IN m2.5 Threaded Inserts* have not been installed on *Boss
    Ext. R* and *Boss Ext. L* do so at this time *--* See Boss Ext.
    Assembly) Using (2) *SJ245-8 m2.5x8mm Thread Screws* install in
    lower corners of *Body.*



11. Place the *AS293 Display & Grill Assembly* back into the jig on the
    right and slide the SJ247 Ferrite Bead onto the display cable and
    plug the cable into the Raspberry Pi with the blue side facing up.



12. Take the loop side of the Velcro and adhere to the loudspeaker
    assembly, stick the hook side of the Velcro onto the bottom of the
    ferrite bead as shown and stick together.



13. Place *AS293 Display Assembly & Grill Assembly* on front of the
    *SJ250-01 Body* and screw closed using (2) SJ243-8 m2.5x8mm Wafer
    Machine Screws.



14. Apply (4) *SJ241 Feet* to the bottom of the *Body* as shown.



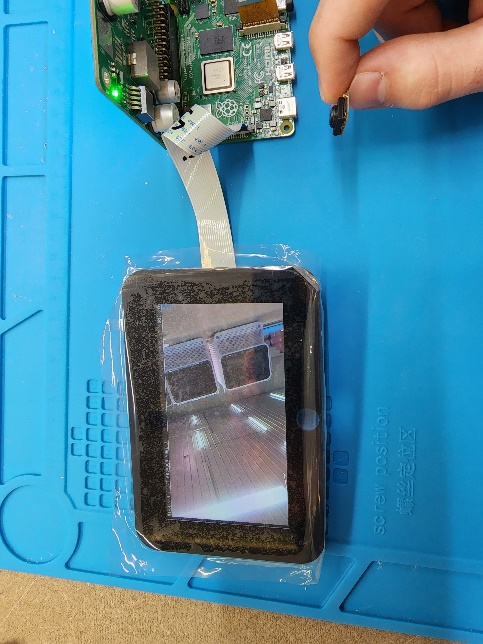
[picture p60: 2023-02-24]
mark-II-production/assembly-instructions/images/display03.jpeg

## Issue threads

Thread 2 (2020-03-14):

Slightly bemused but prob just me

StuartIanNaylor, 2020-03-14:
The Pi4 2gb recently dropped in price as the 1gb model is no longer produced.
https://cpc.farnell.com/raspberry-pi/rpi4-modbp-2gb-bulk/raspberry-pi-4-model-b-2gb-bulk/dp/SC15186
https://cpc.farnell.com/raspberry-pi/rpi3-modbp/raspberry-pi-3-model-b/dp/SC14882
Strangely at farnell the practically same price but the difference is so minimal.
Pi4 you do need to run with a heatsink so guess that adds cost.
https://cpc.farnell.com/pimoroni/com3100/aluminium-heatsink-case-for-pi/dp/SC15306

But its actually a big upgrade that creates much load potential.

This is why I am bemused as the relatively small increase in pi3 to 4 has been chosen whilst the speaker array.
https://www.seeedstudio.com/ReSpeaker-Mic-Array-v2-0.html is much more than
https://www.seeedstudio.com/ReSpeaker-4-Mic-Array-for-Raspberry-Pi.html
Maybe the choice was because of

> Raspberry Pi would have ability to do VAD(Voice Activity Detection), estimate DOA(Direction of Arrival) and show the direction via LED ring, just like Amazon Echo or Google Home.

But the Pi4 is more than capable and the ODAS engine https://wiki.voicen.io/audio_processing/doa/ is sort of cool.
VAD is also easy and relatively low load.
Much with the above choice is using closed source Alango routines whilst we would go totally open-source and also knock $40 off the cost and that means with the Pi4 upgrade and heatsink we are still $25 cheaper.

Alsa when it comes to cost of using the latest audio AI technologies the touchscreen is really superflous whats great about Mycroft is the huge number of skills.
To have the time displayed whilst being told the time is nice but actually not nessacary, I am certainly not going to be squinting at a 4"3 screen and watching video.
But to have it built in is sort of contary to the nature of IoT and even if a Android app is too much to develop a virtual display and any phone could do the same function via VNC.
There are much cheaper offerings personally the screen is as said and reduces a lot of cost if omitted but maybe shop around and go for 7" portrait?
But still in its format and likely positioning the screen could be optional and maybe that should be part of the enclosure design with a fitted cover / blanking port?
If its going to have a screen then not having a camera is an omission.

Also why have I2C volume when the master volume control of the input will do the same?
I purchased a 30watt mono amp as at 24v DC 4ohm you can fit a much better singular speaker.
Stereo in such a small device is relatively pointless because there is no seperation in reality.
I got an aliexpress cheapo that actually sounds great https://www.aliexpress.com/item/32848281225.html

Also a USB hub(s) on all the ports we are stealing would not add much to cost.

I quite like the enclosure but the selection of components as a personal opinion would seem to be unessacary and missmatched.
I would love to get that ODAS lib into Mycroft and use a PI4 for the more load scope it gives the project and add BT5 and disable the broadcom internal.

PI3 with mycroft running is quite load bound PI4 opens up some interesting options of https://www.domoticz.com/ and spare USB ports for zigbee/zwave and even mirocast.

Needs to be much more modular with a base system that throws much out without much loss from what I see of the current BoM.
There is a hole in the maket for a Pi/far-field mic/speaker case in its own right and then add mycroft to that.
When you have an open and module SDK like mycroft that is interchangable with various framewoks and libs then why not have an enclosure system that is in the similar vain?

Just thought I would fire that one across your bows not in a negative, but just wondering you not missing an oppurtunity when there isn't a enclosure for most of the AI kit available.
Continued this on the forum https://community.mycroft.ai/t/hardware-recomendations/8251/7

StuartIanNaylor, 2020-03-16:
Opensource design isn't easy because the materials and purchase qty you have often means everything is a compromise.
With audio enclosures this is a problem as one thing you don't want to do is compromise in density and sound handling or have any components that maybe prone to resonate.

So here is my thoughts on the fundemental design.

1... Basic fundemental audio properties
With audio enclosures this is a problem as one thing you don't want to do is compromise in density and sound handling or have any components that maybe prone to resonate.
One of my first thoughts when I saw the design prototype was wow that 2 speakers on either side of a small device is not stereo as its just anti-phase which is actually what we do digitally with Mycroft to cancel noise.
You can not make stereo like that as it just becomes 2 speakers in a singular sound source all it has done is place more constraint that speaker choice size has halved because we now have 2.
Also its likely to be extremely annoying that because of the anti-phase 90 degree to listener orientation the percieved volume for listener is going to greatly attenuated whilst noise polution greatly increased.
So coupled with the material density and component resonation I couldn't help think for a device in its price range its likely to sound truly awful.

If you are 3d printing I have seen dual wall XXX corragated designs that really help with the ridgidity and density requirements.

```
---
XXX
---
```

So its not XXX porn audio just a double wall construction where the X adds rigidity and also an angle of deflection in an almost similar way acoustic panels do.
You can get fillers that help with the material properties also.
If you are doing 3D printing one thing you can do that isn't really possible with traditional materials is make and design a tuned bass baffle.
But much with sound is cone size especially bass, but look at Google & Alexa designs as these have not just been cost considerations but audio property decisions.

There is also one thing Google & Amazon do that I think is due to designing around a table is a 360 degree design for both mic field and outputed audio that is probably less common in domestic placement and a more directional design could give better volume and clarity.
Thats a minor consideration though to the basic prototype audio flaws.

2... Engineering material choice.
I started wondering about the dificulties in cost, time and final finish of 3D printing and if there are any alternative engineering materials that could give reasonable density, finnish, work and cost.
Unless you have the production qty to merit injection molding then options are extremely limited.
It did occur to me that schedule40 pipe laser cut into sections, with cutout options for display and electronics compartment could be valid as its possible to get low production runs laser cut.

Internally in compression there could be a stack of 3D printed compartments for speaker, CPU/ancillary electronics and Mic array.
So basically you just building up a stack of components in tube shell that can be vinyl wrapped or even clear transparent acrylic for those proud of the internals Mycroft contains.
Its the only alternative of a readily available preformed engineering material with good density, ridgidity, surface finish that even fater laser cutting on low runs could still retain good cost.

But probably going off track but started thinking Mycroft could supply some quite high quality enclosure solutions to a market that seems devoid of any solutions.
Drain pipe caused me some amusement at first, but the more I think about it, its actually just a really good engineering material.
So its a choice of 3D printing or a tube segment enclosing 3D printing components with some consideration to double wall design for rigidity and vibration isolation.
But in terms of basic shape the puck style tube has a lot of advantages as speakers are generally round and maximise cone size and go along with the 'pixel ring' style designs with have come acustom to.
4" is possible but some items are a tight squeeze, 5" makes thing much easier, 6" turning the project into an oversized lump.
Still undecided on what should be AIX format but much is about the speaker.

3... Speaker compartment
A tuned designed audio compartment can massively increase tonal quality and clarity.

I think probably your speaker is likely to be .5 to an inch less in diameter than the internal pipe dimention, but you could squueeze into the max if you choose.

Google home has done some quite neat engineering where they have created another cone shape facing the speaker cone that helps push the audio out into a 360 omnidirectional pattern.
There speakers are top facing but I did wonder if a similar bottom facing might actually also gain some of the benefits of a vibration speaker and use that surface to enhance volume and tone.
Doesn't work on soft furnishings but the tables and shelves these things usually reside it could actually work.
I am not talking full blown vibration speaker same as Google home where a rubberised based with a cone on top will face the speaker that is attached to the speaker fixings on pillars to give approx a 10mm gap.

The advantage is that its not directly underneath the mic array for both pickup, assembly and center of gravity and the base actually becomes a functional property.
I could be being hypocritical here as this might just induce resonance as it does create placement consideration, my audio engineering is lacking but if it works it does have some benefits.

Top or bottom we also have the option to add a tuned bass reflex port with a compressed S design that top vents to bottom or vice versa on whatever you choose.

The bottom side of CPU compartment forms the Speaker roof if bottom mounted or an oppisite arrangement if top mounted.
The speaker compartment is just 2 directional cones with the possibility of a bass refex port that some simple adapter rings could give choice over cone size.
If the Google and Amazon is design around a table for a device that really needs to throw forwards can also be incorporated, dunno but I would go for unidirectional rather than omnidirectional in use. MIcs it makes sense for AEC but audio output less so.

4... CPU/AMP/Mic compartment

Depending on chosen speaker orentation the base or top seals the speaker compartment, as said.
Really all it is a cutout with a blanking cover that allows a blank FRB board that is screwed to the compartment base that you can drill and attach an array of different SBC and amplifier boards to.
Basically you use and array of pillars and create a stack of SBC/AMP/Mic depending on BoM used.
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
krisgesling, 2020-07-16:
Hey Stuart, just closing this as the discussion continued on the Forums:
https://community.mycroft.ai/t/hardware-recomendations/8251/7
and didn't want confusion with the new designs we just released

Would be great to get your thoughts on the new prototype. I believe it already incorporates some of your comments:
https://github.com/MycroftAI/hardware-mycroft-mark-II/tree/master/mark-II-Rpi-devkit

Closed 2020-07-16.

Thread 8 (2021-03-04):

Lost "Hey Ezra" after update

Olzeke51, 2021-03-04:
**Describe the bug**
Update between 3 mar and 4 mar:  I have lost my "Hey Ezra", {hey mycroft - still works}

**Log files**
If possible, add log files from `/var/log/mycroft/` to help explain your problem.
(.venv) mycroft@localhost:/var/log/mycroft$ cat voice.log | tail
2021-03-04 14:15:47.033 | INFO     |   284 | __main__:handle_record_end:49 | End Recording...
2021-03-04 14:15:49.390 | INFO     |   284 | __main__:handle_utterance:76 | Utterance: ['i lost my ks ra login']
2021-03-04 15:18:11.586 | INFO     |   284 | mycroft.session:get:72 | New Session Start: 04ab8fe3-d61d-4b77-90be-8cf945cd4e01
2021-03-04 15:18:11.588 | INFO     |   284 | __main__:handle_wakeword:71 | Wakeword Detected: hey mycroft beta
2021-03-04 15:18:11.591 | INFO     |   284 | mycroft.client.speech.mic:listen:741 | Recording...
Playing WAVE '/opt/mycroft/mycroft/res/snd/start_listening.wav' : Signed 16 bit Little Endian, Rate 48000 Hz, Stereo
2021-03-04 15:18:12.202 | INFO     |   284 | __main__:handle_record_begin:41 | Begin Recording...
2021-03-04 15:18:15.509 | INFO     |   284 | __main__:handle_record_end:49 | End Recording...
2021-03-04 15:18:16.828 | ERROR    |   284 | mycroft.client.speech.listener:transcribe:243 | list index out of range
2021-03-04 15:18:16.830 | ERROR    |   284 | mycroft.client.speech.listener:transcribe:244 | Speech Recognition could not understand audio
********15:18 was merely a time stamp for reference - it was 10:18 EST in So.Carolina

here is the audio.log info::
Playing WAVE '/tmp/mycroft/cache/tts/Mimic2/44fee02dd02d0f6e2c5d82c78d27f685.wav' : Signed 16 bit Little Endian, Rate 22000 Hz, Mono
2021-03-04 14:15:19.050 | INFO     |   278 | mycroft.audio.speech:mute_and_speak:127 | Speak: Would you like to create a troubleshooting package?
2021-03-04 14:15:19.447 | INFO     |   278 | mycroft.audio.speech:mute_and_speak:127 | Speak: This will upload logs to the zero ex zero dot S T service and email a link to you with more information.
Playing WAVE '/tmp/mycroft/cache/tts/Mimic2/b8868c708d8a05096335580ccd962f81.wav' : Signed 16 bit Little Endian, Rate 22000 Hz, Mono
Playing WAVE '/tmp/mycroft/cache/tts/Mimic2/0e350f5714199304a8c7515f714a923e.wav' : Signed 16 bit Little Endian, Rate 22000 Hz, Mono
2021-03-04 14:15:32.868 | INFO     |   278 | mycroft.audio.speech:mute_and_speak:127 | Speak: Please briefly describe the problem you are experiencing
Playing WAVE '/tmp/mycroft/cache/tts/Mimic2/ae3ad3b697b1126122b20ef3cedcefa3.wav' : Signed 16 bit Little Endian, Rate 22000 Hz, Mono
2021-03-04 14:15:49.522 | INFO     |   278 | mycroft.audio.speech:mute_and_speak:127 | Speak: One moment.
Playing WAVE '/tmp/mycroft/cache/tts/Mimic2/2318cecae9cc2beb8560a7e0dac74869.wav' : Signed 16 bit Little Endian, Rate 22000 Hz, Mono
2021-03-04 14:15:52.222 | INFO     |   278 | mycroft.audio.speech:mute_and_speak:127 | Speak: I've sent an email to your registered account with debugging information and instructions for contacting support.
Playing WAVE '/tmp/mycroft/cache/tts/Mimic2/55f15f6b4b1abcbee7041e1894edf6d1.wav' : Signed 16 bit Little Endian, Rate 22000 Hz, Mono
[Config 0834 mar4.txt](https://github.com/MycroftAI/hardware-mycroft-mark-II/files/6084751/Config.0834.mar4.txt)

**Environment (please complete the following information):**
 - Device type: Mark II Dev-kit
 - OS: Mycroft-stable
 - Mycroft-core version: [e.g. 20.08]
 - Other versions:????? [e.g. Adapt v0.3.7]

**Additional context**
I have copies of the terminal screen copies of the four different config files from 3 mar &  4 mar (after update) and noticed no difference - I used the "mycroft-config show system/remote/default/usr command"
'
the attached file is "mycroft-config get"

Olzeke51, 2021-03-05:
Per the Mark2 chat.mycroft.ai channel - this is a device synchronization issue on the 'todo list'
'
the solution is to reboot Mycroft and it will pull in from your mycroft.ai account the needed info
Gary

Olzeke51, 2021-03-05:
Per the Mark2 chat.mycroft.ai channel - this is a device synchronization issue on the 'todo list'
'
the solution is to reboot Mycroft and it will pull in from your mycroft.ai account the needed info
Gary

krisgesling, 2021-03-05:
Hey Gary, thanks for reporting - even though it's on our internal todo list, I'm going to leave this open as it hasn't been fixed and others might run into the same thing.

It also helps us see what issues users are actually running into so we fix the things that will have the most impact.

Really appreciated your detailed feedback so far!

krisgesling, 2021-03-17:
Will be fixed by:
https://github.com/MycroftAI/mycroft-core/issues/2859

chrisveilleux, 2021-03-17:
> Will be fixed by:
> [MycroftAI/mycroft-core#2859](https://github.com/MycroftAI/mycroft-core/issues/2859)

Correction.  Will be fixed by: **https://github.com/MycroftAI/mycroft-core/pull/2861**

This is an issue with the order configurations get applied.

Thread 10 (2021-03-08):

Alarm skill not responding to 'stop the alarm' command

Olzeke51, 2021-03-08:
Alarm skill not responding to '**stop the alarm'** command
Mark2-dev-kit - still on 'stable' 20.08.10 _[although my account/device is set for 'latest']
these are the last parts of several log files -
[alarm not stopping.txt](https://github.com/MycroftAI/hardware-mycroft-mark-II/files/6098519/alarm.not.stopping.txt)
_
Used the Basic Command web page to start an alarm, then tried to stop it.
I have tried several other words based upon the alarm-skill scripting I could find  - end/end alarm/cancel alarm/kill/kill alarm
"stop beeping" was the most successful - but then mycroft got stuck in a 'thinking' loop pattern on the LEDs
Note: while I was writing this - the alarm stopped beeping after 10+ minutes [default action], **but still** had the 'thinking' loop pattern.
        3 pushes of the 'attention' button made it stop

ChanceNCounter, 2021-03-16:
This just happened to me. I haven't dug in, but I *think* STT activating the mic is competing with the alarm skill deactivating the mic. I was able to stop the alarm by getting the utterance out quickly, before the mic deactivated.

krisgesling, 2021-03-17:
The Timer and Alarm Skills both have some funky things that were added to workaround issues with other platforms but it creates a real problem when different components are each trying to interact with the systems audio stack. Need to clean these up.

I'm going to split the thinking loop getting stuck into a separate ticket.

ken-mycroft, 2021-04-27:
This has been fixed in the latest version of the alarm skill. Stop the alarm, cancel alarm, etc all work now. Note you must say 'hey mycroft' first, however.

Closed 2021-04-27.

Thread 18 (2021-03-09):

Cannot complete poweroff / reboot

krisgesling, 2021-03-09:
**Describe the bug**
Cannot poweroff the device using either the "Turn off" item in the on screen menu, or the command line. The system currently fails on shutdown and eventually reboots.

**Workaround**
select reboot / poweroff, then wait 5 seconds before unplugging the device.
This also affects reboot, taking a long time to cycle - you can safely remove and re-insert the power cable after a 5 seconds to speed up the process.

netkruzer, 2021-03-09:
I noticed the same thing on my install. I run sudo reboot now, and it takes a couple minutes or so to reboot.

krisgesling, 2021-06-10:
This has been fixed in the stable release hitting devices currently.

The startup and shutdown sequence still needs to be prettified, but you can now shutdown cleanly and it will not reboot.

Closed 2021-06-10.

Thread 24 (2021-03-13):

Prod_003 reboot_failure_after_alarm_skill_failure

Olzeke51, 2021-03-13:
Prod_003 reboot_failure_after_alarm_skill_failure
Mark2_pi4 DEV-KIT, with ethernet cable connection
Saturday Mar 13
'
** this is second, [if not third] reboot failure on Prod_003
'
to reproduce this failure:
tell Mycroft to set alarm ( 2min in this case)
alarm goes off
attempted several words to 'stop beeping' ; between and during beepings
'
(?iirc the pull-down menu not avail) POwer-cycled for reboot
**using my Mint-linux timeclock - EST zone
10:14-15 got keyboard on black screen AND ONLY temperature LED
waited
10:18-19 entered 'whoami' on touch keyboard
   got a linux graphic Mycroft User logon with UTC time
    *no known password &&& no way to enter it if I did*
15:24 UTC did a power cycle ::Time from login screen
**
**
loaded Prod_003_RC02 onto an SDC card
rebooted
got 3 roundie dots, got a second 3 roundie dots on screen (?lindie)
then asked to "Pair" in smooth (?American-male) voice
Paired okay ,
'
OOPS - can't pronounce 'Feisty" device name - spells it out !!
AGAIN one hour behind local EST time on display, even after asking for 'time'
AGAIN timestamp is for a previous 'latest' of 03-09 13:57:04
[homer-mycroft2-Prod_003-alarm_fail-reboot_fail.tar.gz](https://github.com/MycroftAI/hardware-mycroft-mark-II/files/6135201/homer-mycroft2-Prod_003-alarm_fail-reboot_fail.tar.gz)
[Feisty-mycroft.sdc01.logs.tar.gz](https://github.com/MycroftAI/hardware-mycroft-mark-II/files/6135202/Feisty-mycroft.sdc01.logs.tar.gz)

krisgesling, 2021-03-17:
Linked to #30

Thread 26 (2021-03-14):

Spinning LED's when unit is put asleep

Stephen-Rex, 2021-03-14:
**Describe the bug**
A clear and concise description of what the bug is.
When mycroft is left unattended at night, the LED's turn blue and start spinning. The unit will stay in this shape.

**To Reproduce**
Steps to reproduce the behavior:
1. Put Mycroft in sleep mode
2. Leave unit unattended for a few hours
3. Come back and see it in that state

**Expected behavior**
I expected mycroft to not change state when left unattended

**Log files**
If possible, add log files from `/var/log/mycroft/` to help explain your problem.

**Environment (please complete the following information):**
 -Stock Mycroft Development kit.

**Additional context**
I'm running everything stock and haven't started playing with the unit yet.

Please think carefully about whether you have modified anything in Mycroft's code or configuration files.  If so, can you reproduce this on a clean installation of Mycroft? Many "bugs" turn out to be non-standard configuration errors.

Olzeke51, 2021-03-14:
I wonder if this occurs as a result of an {attempted} update-check??   I run on the 'latest' and my screen will become the "Standby Face" instead of staying 'Sleep" in the morning .....

krisgesling, 2021-03-17:
Linked to #32

krisgesling, 2021-03-17:
Thanks for the bug report @Stephen-Rex - my guess at this stage is that Mycroft got stuck in a "thinking" loop.

Stephen-Rex, 2021-03-17:
I can now reliably recreate this issue. Issue commands
>Hey  Mycroft go to sleep
>Hey Myrcroft

this will trigger the thinking loop with the dark blue spinning LED's.  Hitting the top button 3x did not break it free from the thinking loop for me.

Olzeke51, 2021-03-26:
on his latest latest 03-24 03:35:08 seems to fix it [though I used the switch as WakeWord is inop -currently]
HAD a real short 'listen time LED" if no audio input right away !!!!!!!

ken-mycroft, 2021-04-27:
This bug activity predates the default time out for the spinning LEDs. I can not reproduce this behavior on the latest build. I suspect this was fixed several versions ago.

Closed 2021-04-27.

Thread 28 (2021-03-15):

On screen keyboard cannot be hidden without reboot

krisgesling, 2021-03-15:
**Describe the bug**
On screen keyboard cannot be hidden. Requires restart of the device.

**To Reproduce**
Steps to reproduce the behavior:
1. Open a website on the GUI.
2. Tap into a text field
3. On screen keyboard pops up
4. Tap the hide keyboard button in lower right - nothing happens.
5. Restart device to remove keyboard from screen.

**Expected behavior**
Keyboard should only be visible whilst an input field is in focus.
Tapping the hide keyboard button should always minimize the keyboard.

notmart, 2021-03-15:
This is due to missing environment variables.
if on my session i set
export QT_IM_MODULE=qtvirtualkeyboard
and then restart plasma, then it works fine
in /etc/profile.d it seems to be missing enforce-qtvirtualkeyboard.sh present in the debos image.

after fixing that, the keyboard works fine, touchscreen interaction with the site is still pretty bad, to fix that is needed to remove the remains of the old volume control via vertical gesture.

krisgesling, 2021-03-16:
Thanks @notmart, that definitely lets the keyboard close, so this will be in the next release of latest in a few hours.

However I still don't seem to be able to type into a text field. Are you seeing the same?

krisgesling, 2021-04-01:
This is now live in the latest update and includes fixes for the bad scrolling behaviour on things like websites.

It also means the on screen wifi settings are much more usable if you want to connect to an additional wifi network while your existing one still exists. However there's still definitely more work needed here.

Closed 2021-04-01.

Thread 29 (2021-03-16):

blue spinning circle

Olzeke51, 2021-03-16:
MarkII  -devkit on a network cable - "latest" software status
had 'woke' up unit - IIRC
checked later and found the blue spinning circle of the boot process
copied logs and dmesg
used the pull-down menu to restart
came up okay with 'Standby Face"
[mycroft.tar.gz](https://github.com/MycroftAI/hardware-mycroft-mark-II/files/6148358/mycroft.tar.gz)

krisgesling, 2021-03-17:
Possibly linked to #21

ken-mycroft, 2021-03-17:
Just to be sure I understand. You have the ethernet cable plugged in? Also, I am assuming this dmesg is from a successful reboot not the dmesg file when the device got stuck in the spinning loop?

Olzeke51, 2021-03-17:
Re: @ken-mycroft  I don't remember  B.U.T  .. I have a new set of files for you , including a dmesg
'
copied up my log files this AM [Mar 17 in reference to "no chase lights"] approx 06:01 EDT
at 06:51 EDT I restarted my Mark II [with ethernet cable - wifi is not connecting]
at 07:20 EDT -ish  I noticed a keyboard on screen {had to leave for work } SO I left it alone
at 15:30 EDT I had the" boot blue spinning circle"
at 16:21 EDT MarkII still had blue spinning circle BUT it did respond with Voice ONly to time & temp skills
could not get a Standby Face with the 'Pull down menu' selection  - still blue spinning circle
'
log files and dmesg_17pm.txt included in attached file - should be results since this 06:51 reboot
[olzeke51_logs_dmesg_blue_circle_29ticket.tar.gz](https://github.com/MycroftAI/hardware-mycroft-mark-II/files/6159601/olzeke51_logs_dmesg_blue_circle_29ticket.tar.gz)

ken-mycroft, 2021-04-28:
This has been fixed in newer releases

Closed 2021-04-28.

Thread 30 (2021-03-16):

Session logged out after reboot

ChanceNCounter, 2021-03-16:
Admittedly, I was beginning from a bugged state:

1. Tell Mycroft to shut down. Confirm.
2. Mycroft user logs out. Screen displays Plasma login. Keyboard comes up.
3. Collapse keyboard. Tap power icon. Device does not shut down. Plasma session dies. Device can no longer be accessed via SSH and must be hard-killed.
4. Restart device. Linux login screen appears. In the background, Mycroft initiates wifi setup, then cancels and joins the correct network. I can ssh in, but there's no display manager running on the device, and the on-screen tty is not logged in, so that's it. I've got a terminal.

ChanceNCounter, 2021-03-16:
Update: After rebooting over ssh, I am now looking at a login screen, but it's *not* on my network, nor is it doing the wifi-join routine. Now it's an ornament =P

ChanceNCounter, 2021-03-16:
Further update: after a hard kill, I have the Plasma login screen, which I guess is an improvement. However, it still isn't joining the network.

I'd call it quits and re-flash the image, but I wanna know what precipitated this.

Olzeke51, 2021-03-16:
anything in the 'dmesg' file - to indicate areas of concern?  log files??
Is this on a Mark II Dev-kit  or on mycroft-core on a _____?

ChanceNCounter, 2021-03-16:
Update: After leaving the thing off for a while, and reseating the USB stick, it booted normally. I'll see if I can repro later with the same steps, but it'd probably be less of a hassle for @dschweppe to repro, owing to I've only got the one unit.

(Mk2 latest, as of when this issue was opened)

Olzeke51, 2021-03-16:
uh, I noticed my USB stick [provided with the dev-kit] was rather warm - after having been on for a while.
I run on a network cable [wifi connection issue from the git-go] and there is an awful lot of network traffic, I don't think there is a full second that it isn't blinking.
"dmesg -T >> /tmp/dmesg.txt"  will put dmesg in local time vs. the usual seconds from boot

krisgesling, 2021-03-22:
This seems to manifest in at least 3 different ways:
1. A Plasma login screen
2. A TTY login screen
3. An on screen keyboard with a seemingly otherwise blank screen

It sounds like you got number 2 is that right?

ChanceNCounter, 2021-03-22:
I've now seen 1 and 2, but not 3.

ChanceNCounter, 2021-03-23:
Now I've got the keyboard. FWIW, it flashed the Plasma login screen before popping to black with the keyboard. I suspect it *thinks* the login screen is still back there. If there were credentials, I'd check, but it doesn't seem like a very good reason to add any.

ChanceNCounter, 2021-03-23:
Actually, confirmed by hitting enter on the keyboard. Plasma login screen still there. It just disappears while the keyboard is up.

---

As I was typing this comment, something happened. The display manager died, some systemd shutdown stuff popped up on screen, something about "unable to finalize devices." This stuff consistently fails to appear in logs, so I'm noting it here while it's fresh.

Then the unit rebooted itself. I'm now looking at the Linux login screen.

ChanceNCounter, 2021-03-23:
I've confirmed that Mycroft is running under this login screen. It complained about web access, got on wifi, and responded to the wake word, but it's been spinning cyan ever since. I'm also seeing a lot of cert failures coming from Mimic2 requests. I don't know if any of this is related to the restart/session weirdness, but it's all happening at once.

ChanceNCounter, 2021-03-23:
After a reboot, it went straight to the Linux login screen. It seems that in these cases (or, at least, this time) when the WM doesn't start, Mycroft spins up, but audio doesn't work right. Logs are full of

`2021-03-23 01:06:08.994 | WARNING  |   275 | mycroft.client.speech.mic:read:127 | High input latency: 0.250000`

and there's no audio capture. The wake word isn't working.

It's also worth noting at this point that this is *most* startups on my unit. I don't think it boots up normally even 1/4 of the time, though I haven't been counting.

krisgesling, 2021-04-01:
This is fixed in the latest update. Will tag a new stable release soon too as there's a truckload of bugfixes available now.

Closed 2021-04-01.

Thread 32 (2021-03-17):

LEDs get stuck in "thinking" loop

krisgesling, 2021-03-17:
Split from #10

**To Reproduce**
Steps to reproduce the behavior:
> I have tried several other words based upon the alarm-skill scripting I could find - end/end alarm/cancel alarm/kill/kill alarm
"stop beeping" was the most successful - but then mycroft got stuck in a 'thinking' loop pattern on the LEDs
Note: while I was writing this - the alarm stopped beeping after 10+ minutes [default action], but still had the 'thinking' loop pattern.
3 pushes of the 'attention' button made it stop

**Expected behavior**
Any "thinking" behavior should be limited to a reasonable timeout.

ken-mycroft, 2021-04-27:
This bug has been fixed several releases ago.

Closed 2021-04-27.

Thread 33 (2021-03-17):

No LED ring after sleep/wakeup

Olzeke51, 2021-03-17:
**Describe the bug**
Put 'Feisty' to sleep [night of Mar16] ; "wake up" at 0551EDT Mar17
no 'listening' LEDs and no 'thinking' LEDs for 'wake up' or Other commands - DO get the 'beep-bop' audio prompt
Voice response is appropriate for the 'skill' requested [time / weather]
Temperature & Mic status LEDs are ON

[mycroft-17am-no-led-chase.tar.gz](https://github.com/MycroftAI/hardware-mycroft-mark-II/files/6155740/mycroft-17am-no-led-chase.tar.gz)
**Log files**
markII-devkit on 'latatest' on ethernet 03-16 04:43:36

krisgesling, 2021-03-22:
Putting the device to sleep and waking up doesn't seem to cause the LED failure so assuming it just coincidentally happened whilst the device was asleep.

Olzeke51, 2021-03-23:
seems to maybe resolve itself - I need to start referencing the Time Stamp of the "latest"

krisgesling, 2021-03-23:
Yeah the timestamp on the homescreen specifies when the mycroft container you're using was built so that is useful info if someone is changing from one day to the next.

ken-mycroft, 2021-04-27:
This has been fixed several releases ago.

Closed 2021-04-27.

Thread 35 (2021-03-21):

little blue circle during "Temperature' request

Olzeke51, 2021-03-21:
Mark 2 Dev-Kit , on network cable, 'latest' software, 03-19 04:18:19
'**** repeated itself Sunday morning - notes added in new comment
'
FYI :: had bad update - several reboots [2:30 to 3:00 AM  EDT] to get it to a 'Standby Face' - separate issue
couldn't find a 'Temperature Skill' to log issue - almost posted to 'mycroft-core'
'
(approx 7:30-ish EDT) asked for 'Temperature'  ; got the little blue circling on the screen [.5 to .75 secs??]
{like during boot process ):: then got proper response
2nd time asked "Temperature" - normal response
3rd time asked "Temperature" - only got display   ??? is this an AI/ML trait/response??
later (25+ minutes?) asked a 4th time - can't remember BUT logs show a TTS error
/* same type of TTS error during a repeated 'Time' request - attempts to replay a .wav file */

'
log is a combined Voice/Audio/Enclosure pertinent time frame only
[temperature-requests.log](https://github.com/MycroftAI/hardware-mycroft-mark-II/files/6176610/temperature-requests.log)

Olzeke51, 2021-03-21:
More information:  it repeated this 'boot blue circle on screen'
Background: did a 'Restart' from the pull-down menu
had several issues -login keyboard, main indication of trouble
had to 'Power-Cycle' it two more times - still minor issue
SO did a "Turn Off" from the pull down -- Booted OKAY
put to 'Sleep' overnite
'Wake Up' -
'Temperature'  and had that momentary 'boot blue spinning circle' - but normal response

krisgesling, 2021-03-22:
Hey there, thanks for more bug reports. I've split some of these out into individual tickets that you can see ^^ so they're easier for us to track.

It also looks like you hit issue #30 where the OS gets logged out and you have to restart the system.

Do those 4 tickets cover everything in here or did I miss something?

Olzeke51, 2021-03-23:
yes that covers the issues I noted - thanks for breaking them out - I wasn't sure how specific to make issues since it is beta-"latest" :: will try to drill down a litlle more in the future
'
NO, #30 is a voice shutdown - mine is from the Pull-Down Menu; so we might want to spin this "restart" to a new issue
'
Comments on the primary issue of 'Restart'
The Failed reboot/Restart - seem to be a function of selecting 'Restart' from the pull-down menu,
[and it appears to require at least two more Power Cycles to get stabilized - is Restart saving variables??]
IIRC - all(most?) of the "Turn Off" selections seem to come up correctly

krisgesling, 2021-03-23:
Tapping the button in the pull-down menu should call exactly the same function in Mycroft as telling Mycroft to reboot by voice. Whether the system hits the different login screens seems to be chance at the moment, but we're still digging into it.

krisgesling, 2021-04-06:
Closing as this seems to be covered by the new broken up tickets. Please reopen if I'm mistaken.

Closed 2021-04-06.

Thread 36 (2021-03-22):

Sleep face does not go away after waking up

krisgesling, 2021-03-22:
**Describe the bug**
Sleep face does not disappear after Mycroft is woken up until another interaction takes over the UI.

**To Reproduce**
Steps to reproduce the behavior:
1. "Hey Mycroft, go to sleep"
2. Screen changes to sleeping face
3. "Hey Mycroft, wake up"
4. Screen remains on sleeping face.
5. "Hey Mycroft, what time is it?
6. After timeout Homescreen is returned.

**Expected behavior**
Sleeping face should go away when device wakes up.

Also a question of whether we are keeping the sleeping face? Putting the device to sleep is to stop it recording audio, I may still want to see my configured Homescreen.

@dschweppe thoughts on this?

**Context**
Split from #35

forslund, 2021-03-22:
The sleep face is a remnant from the very first demo and I don't think it's in any of the design docs

krisgesling, 2021-03-22:
Yeah was wondering if that was the case. We need to think of how to best represent that state, as well as how to differentiate between the unit being asleep via a voice command vs the hardware mic switch being off. Both mean the device won't listen but this could be confusing for users.

forslund, 2021-03-22:
SInce the Mark-2 uses the display port it would be cool if the display dimmed to a very low strength...And some led indication like a slow low level pulsing....

krisgesling, 2021-05-11:
Was looking at a different issue and did a small part of this at least:
https://github.com/MycroftAI/skill-mark-2/pull/60

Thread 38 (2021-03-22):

Loading spinner shown while waiting for Weather Skill UI

krisgesling, 2021-03-22:
**Describe the bug**
On the first call of the Weather Skill, the loading spinner is shown for a few seconds before the Weather UI loads.

**To Reproduce**
Steps to reproduce the behavior:
1. Reboot device
2. "Hey Mycroft, what's the weather"

**Expected behavior**
Load the UI in the background until ready to be shown.

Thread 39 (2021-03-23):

Spurious Reboot OR "Temperature" request

Olzeke51, 2021-03-23:
**Describe the bug**   this may be a duplicate .....grz
IF there wasn't a forced reboot/update at ::
"2021-03-23 19:52:15.651 | INFO     |   280 | mycroft.client.enclosure.base:on_close:497 | Closing 547483477088"
THEN it's possible a "Temperature" request triggered it ..!!?????
{{ I did this earlier:: 2021-03-23 18:23:24.554 | INFO     |   275 | __main__:handle_utterance:76 | Utterance: ["what's the temperature"]}} got a good reply
'
I don't remember asking for/doing anything with Mycroft till about 22:00 +- UTC
The only thing I can think; would be to ask for the Temperate at the reboot time........
.                                               but  didn't stick around to see a reboot ....

**To Reproduce**
Steps to reproduce the behavior:
1. something is wrong with Temperature
2. Just asked for it [22:21 UTC] got verbal respons, BLUE spinner, and the degrees was in real small font, but clouds okay

**Log files**
'/home/olzeke51/file.dump/mycroft/mycroft_23pm.tar.gz

**Environment (:**
 - Device type: Mark 2 DEV-KIT, on network cable
 - OS: default
 - Mycroft-core version: [e.g. 20.08]
 - Other versions: "latest" 03-19-04:18:19

krisgesling, 2021-03-24:
Hey there,

If you've got the latest channel selected in your device settings then you can get updates at any moment that will often require a restart of the device. The timestamp on your homescreen indicates when the mycroft container got built but this one was an update to the board support package - a hardware compatibility layer - so that timestamp won't have changed.

There's a two main things we want to do that are relevant here:
1. Create a better system to report to developers and end users what has changed in the latest build. This needs to report changes to a whole array of repositories that make up your Mycroft installation.
2. Add a more intelligent update process. If a device is currently in use, the update should not be applied, or at the very least the user should be prompted to know that an update will be applied and hence their device will restart. More likely though, we delay the update for some period of time and then again check if the device is in use before applying it. Ideally everyone on auto updates gets it applied overnight while they are not needing their device and wakes up to new functionality each morning.

I really don't think the temperature intent would have rebooted the device but if you see anything that really suggests otherwise let us know.

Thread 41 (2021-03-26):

latest 03-24 03:35:08  lost Wake Word response

Olzeke51, 2021-03-26:
**Describe the bug**
latest update as posted ; the WakeWord  "Hey Mycroft" OR Ezra will not wake it up
mechanical switch does work,
FYI -but had no response LEDs until 2021-03-26 00:40:58.064  reboot/restart auto triggered !! [not sure if I rebooted]

*
**Log files**
[mycroft-26am.tar.gz](https://github.com/MycroftAI/hardware-mycroft-mark-II/files/6210909/mycroft-26am.tar.gz)

**Environment :**
 - Device type: [Mark2-rpi4 - network cable/ uSDC
 - OS: [e.g. Ubuntu,
 - Mycroft-core version: [e.g. 20.08.01 as reported

Olzeke51, 2021-03-27:
working in the Denver time zone, testing I did - though there was one hiccup - constant 'listening' loop/fade

Olzeke51, 2021-03-27:
it's working now - after several re-Pairs/device names [involving power-cycles]

krisgesling, 2021-03-29:
When you say the "mechanical switch does work"
Do you mean that it did not change the LED colour either?

Also can you describe a little more what you mean by the hiccup - "constant 'listening' loop/fade" - was this to do with the LEDs or the actual listener was looping in some way?

Olzeke51, 2021-04-03:
sorry about the late reply - i got locked into chat and forgot the email
mech switch - it causes mycroft to respond as if the WakeWord was accepted.
'
constant listening loop/fade   -- the 2nd or 3rd loop of the 'listen chase ring' changes intensity in a fade down , fade up instensity

ken-mycroft, 2021-04-27:
I am assuming this is related to using Ezra as a wake word as I can't reproduce this behavior using 'hey mycroft'. If this is still an issue in the latest release please create a new ticket with the steps to reproduce.

Closed 2021-04-27.

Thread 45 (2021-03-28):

lots of 'false Mycroft triggers' during the "News" skill

Olzeke51, 2021-03-28:
**Describe the bug**
while listening to 'News' - Fox , PBS Newshour Da
had multiple 'listen triggers'  each would last approx 10 seconds of silence - (some 15+)
then the NEWs feed would sound as if it picked up where it was cut off
'
had a short 'listen', fading 'listen', even a 2 fade listen
usually had 2 blue chase rings though occasionaly only 1

**To Reproduce**
Steps to reproduce the behavior:
1. get Mycroft attention - using switch - lost voice again
2. Say "News"
3. start listening  - no background noise
4. have interruptions - make no response
5. feed picks up where it was interrupted [for at least 10 seconds]

**Expected behavior**
hear the 'News' uninterrupted

**Log files**
[mycroft28-news.tar.gz](https://github.com/MycroftAI/hardware-mycroft-mark-II/files/6217549/mycroft28-news.tar.gz)

**Environment **
 - Device type: Mark2-rpi4 , network cable, uSDC
 - OS: default Ubuntu as shipped from Mycroft
 - Mycroft-core version: [e.g. 20.08.1
 - Other versions: latest 03-24 03:35:08 per Standby Face

**Additional context**
my watch is approx 29 seconds ahead of the Mycroft time displayed [logged time in logs??]
Fox had 7 or so at 09:00 EDT time frame
power-cycled
Fox had 7 interrupts at the 10:24 EDT time frame
muted the mic for another test - NO interruptions
power-down
selected PBS News hour @ home.mycroft.ai account , short wait
power-up   in the 10:30+ EDT time frame
listened to 'News' from the git-go -- PBS
within about 4 seconds of PBS announcing its stream - interruption
PBS had fewer incidences of interruptions than Fox :::

per the same time period of approx 4-6 minutes

ChanceNCounter, 2021-03-28:
Activating STT will always last until it stops recording, which is usually when it thinks you're done talking. That part's not too surprising.

Also resuming playback, that part's right.

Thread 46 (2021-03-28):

Mimic2 TTS fails on cached lines (.wavs play fine through paplay)

ChanceNCounter, 2021-03-28:
For the past little while, I've been getting TTS failures on cached phrases. Here's an example from audio.log:

<details>
<summary>audio.log snippet</summary>

```python3
2021-03-28 21:35:08.852 | INFO     |   270 | mycroft.audio.speech:mute_and_speak:127 | Speak: Seventeen
Playing WAVE '/tmp/mycroft/cache/tts/Mimic2/00e86eb858795dc0bce0a673f3218e61.wav' : Signed 16 bit Little Endian, Rate 22000 Hz, Mono
2021-03-28 21:35:15.702 | INFO     |   270 | mycroft.audio.speech:mute_and_speak:127 | Speak: Seventeen
2021-03-28 21:35:15.707 | INFO     |   270 | mycroft.tts.tts:_get_sentence_from_cache:393 | Found 00e86eb858795dc0bce0a673f3218e61.wav in TTS cache
2021-03-28 21:35:15.710 | ERROR    |   270 | mycroft.audio.speech:mute_and_speak:134 | TTS execution failed.
Traceback (most recent call last):
  File "/opt/mycroft/mycroft/audio/speech.py", line 129, in mute_and_speak
    tts.execute(utterance, ident, listen)
  File "/opt/mycroft/mycroft/tts/tts.py", line 338, in execute
    self._execute(sentence, ident, listen)
  File "/opt/mycroft/mycroft/tts/tts.py", line 385, in _execute
    viseme = self.viseme(phonemes) if phonemes else None
  File "/opt/mycroft/mycroft/tts/mimic2_tts.py", line 208, in viseme
    vis_dur = float(pair[1])
IndexError: string index out of range
```

</details>

I don't know when this behavior began, exactly, but I first *wondered* if Mycroft had failed to reply last night, and I first *definitively noticed* about half an hour ago.

Maybe this belongs at Mimic, idk, but I've never noticed this on Linux.

forslund, 2021-03-29:
I think this should be fixed through https://github.com/MycroftAI/mycroft-core/pull/2865/files, but there is a related issue for mimic1 See PR https://github.com/MycroftAI/mycroft-core/pull/2871

krisgesling, 2021-04-27:
@chrisveilleux this is definitely fixed and deployed right?

I can't reproduce it currently.

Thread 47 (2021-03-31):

lost "listening ring" - latest 3-29 11:13:38

Olzeke51, 2021-03-31:
**Describe the bug**
when WakeWord is given - no 'listen chase ring' , get be-bop though

**To Reproduce**
Steps to reproduce the behavior:
IIRC - put unit to sleep Tuesday EDT -21:30 ish
"wake Up" on Wed EDT 05:52-ish   -- NO 'listen chase ring"  did get the be-bop prompt
"temperature"   no 'ring' got be-bop and correct data (rushed it so didn't see what day (rollover) was like
"Shutdown". no 'ring' got be-bop 'yes'
still missing the 'listen chase ring' after reboot
SO
did a 'Shutdown' with a 10 sec wait, then Power-cycle
it all work

**Expected behavior**
a light blue chase ring.

**Log files**
lem.
[mycroft-no-listen.tar.gz](https://github.com/MycroftAI/hardware-mycroft-mark-II/files/6235842/mycroft-no-listen.tar.gz)
.

**Environment (please complete the following information):**
 - Device type: [DEV-KIT M2-pi4   - networtk cable, uSDC
 - OS: [default
 - Mycroft-core version: [e.g. 20.08.1
 - Other versions: latest 3-29 11:13:38

**Additional context**
Don't know if it is day rollover effecting the ring or ?????

Olzeke51, 2021-04-01:
lost 'ring chase' again after this update on 0401
2021-04-01 08:06:40.123 | INFO     |   332 | mycroft.client.enclosure.base:on_close:497 | Closing 548339825584
2021-04-01 08:09:14.218 | INFO     |   281 | __main__:create_enclosure:51 | Creating Mark II Enclosure
**
I have added dmesg with two types of timestamps
connected a terminal to the rPi4 serial port and captured console output - file included of last reboot cycle
******
[mycroft_0401_08:06_reboot.tar.gz](https://github.com/MycroftAI/hardware-mycroft-mark-II/files/6242790/mycroft_0401_08.06_reboot.tar.gz)

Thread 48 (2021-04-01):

'Enclosure skill" won't stop ona " mycroft-start restart all " command

Olzeke51, 2021-04-01:
**Describe the bug**
When I issue a " mycroft-start restart all " command ,
status screen (ssh-terminal) shows 'enclosure not stopping' - - it has to be killed

**To Reproduce**
Steps to reproduce the behavior:
1. ssh into Mycroft unit
2. Type "" mycroft-start restart all " command
3. see results in ssh-terminal screen
4. See error '....'

**Expected behavior**
a stopped enclosure - not a kill

**Log files**
olzeke51@Tester:~$ ssh -p 8222 mycroft@192.168.2.4
(.venv) mycroft@localhost:~$ mycroft-start restart all
Starting all mycroft-core services
Initializing...
Restarting: bus
Stopping messagebus.service (258)...stopped.
CAUTION: The Mycroft bus is an open websocket with no built-in security
         measures.  You are responsible for protecting the local port
         8181 with a firewall as appropriate.
Restarting: skills
Stopping skills (265)...stopped.
Restarting: audio
Stopping audio (274)...stopped.
Restarting: voice
Stopping speech (278)...stopped.
Restarting: enclosure
Stopping enclosure (283)...failed to stop.
  Killing enclosure (283)...killed.

**Environment **
 - Device type: Mark2-rpi4 DEV-KIT on network cable & uSDC
 - OS: Ubuntu 20.04.2 LTS
 - Mycroft-core version: [e.g. 20.08.1
 - Other versions: latest per screen 03-29 11:13:38

**Additional context**  - just an observation
seems odd that you would 'start' service then stop them ; after they already a started
also I would have thought the message_bus would be the last to shutdown

krisgesling, 2021-04-06:
Thanks for reporting this, it shouldn't cause issues but it could and it shouldn't be happening so definitely something we want to fix up but it's going to be lower priority at the moment.

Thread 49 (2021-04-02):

SSH Connection times out

NeonDaniel, 2021-04-02:
**Describe the bug**
SSH connection times out when trying to connect to my Mark 2. I had successfully connected, restarted via SSH terminal, and upon restarting my SSH connection fails.

**To Reproduce**
Setup SSH connection for the device.
Connect via SSH and restart via `sudo shutdown -r now`
Try to SSH to the device after restarting

**Expected behavior**
SSH connection should establish

**Log files**
I tried creating a support ticket but never received an email. Below is the output from my connection attempt.
```
$ ssh mycroft@192.168.1.157 -p8222 -vvv
OpenSSH_8.2p1 Ubuntu-4ubuntu0.1, OpenSSL 1.1.1f  31 Mar 2020
debug1: Reading configuration data /etc/ssh/ssh_config
debug1: /etc/ssh/ssh_config line 19: include /etc/ssh/ssh_config.d/*.conf matched no files
debug1: /etc/ssh/ssh_config line 21: Applying options for *
debug2: resolve_canonicalize: hostname 192.168.1.157 is address
debug2: ssh_connect_direct
debug1: Connecting to 192.168.1.157 [192.168.1.157] port 8222.
debug1: connect to address 192.168.1.157 port 8222: Connection timed out
ssh: connect to host 192.168.1.157 port 8222: Connection timed out
```

**Environment (please complete the following information):**
 - Device type: Mark 2
 - OS: Mark 2 Image
 - Mycroft-core version:2021-03-02-01:40:08

Olzeke51, 2021-04-03:
did you get a new IP address - that happened to me once on my Dev-Kit
testing your Linux shutdown -- I normally use the pull down menu,  select either 'Turn off' or Restart - wait 5-10 seconds after the terminal screen shows up & power cycle it -[though if I wait the whole time it seems to come up better ]
'
I'm good ::
(.venv) mycroft@localhost:~$ sudo shutdown -r now
Hangup
(.venv) root@localhost:/# Hangup
Connection to 192.168.2.4 closed.
olzeke51@Tester:~$ ssh -p 8222 mycroft@192.168.2.4
(.venv) mycroft@localhost:~$

krisgesling, 2021-04-06:
Hey Daniel, did you confirm the IP address was still correct?
Is the behavior still occurring?
Is/was the device otherwise responsive? ie the system itself hadn't completely crashed.

@Olzeke51 the strikethrough formatting would come from you having multiple ~ in your message. Eg
```
~This is struck out~
```
~This is struck out~

It's helpful to wrap any code, output or similar with three backticks, which is generally with the ~ key next to the 1. That's what creates the grey block you see above.

NeonDaniel, 2021-04-06:
I did confirm IP address via WebUI and "what is my IP address"; behavior did not occur yesterday though I only restarted my (2) assembled dev kits once each. The device was fully working to handle intents, so the network connection was definitely up, just no SSH response..

Maybe if this happens again, I can try toggling the SSH switch in the web settings.

ChanceNCounter, 2021-04-06:
FWIW, and obviously that's not very much, I've had an open line to my unit for days at a time and only experienced disconnects when it rebooted.

I mention this only because it *slightly* increases the odds it's about your network, rather than the mk2.

ChanceNCounter, 2021-04-06:
That was badly phrased, of course: I only experienced reboots when appropriate =P never seen this bug, nor any abrupt/inappropriate timeouts, disconnects, or interruptions while connected.

NeonDaniel, 2021-04-06:
> FWIW, and obviously that's not very much, I've had an open line to my unit for days at a time and only experienced disconnects when it rebooted.
>
> I mention this only because it _slightly_ increases the odds it's about your network, rather than the mk2.

I also have persistent connections once established. It's just a strange situation where a few times I'm unable to establish a connection after a reboot but it seems resolved after rebooting... Could very well be related to my Network topology though...

For reference, I'm running Ubiquiti AP's with a PFSense router.. Everything I'm doing is on the same SSID and subnet; DHCP is enabled, but so far my 2 Mark2's have kept the same IP addresses

krisgesling, 2021-04-06:
Yeah right, thanks for the extra info.

I've bumped it to low priority for the moment given it's not still occurring but certainly something that shouldn't be happening.

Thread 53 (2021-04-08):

stable 04-06 :: SSL error in most logs, during first part of update

Olzeke51, 2021-04-08:
**Describe the bug**
this was also noted in earlier 'latest' updates
2021-01-02 16:06:26.003 | WARNING  |   271 | mycroft.api:check_remote_pairing:549 | Could not get device info: SSLError(MaxRetryError("HTTPSConnectionPool(host='api.mycroft.ai', port=443): Max retries exceeded with url: /v1/device/e05bbe67-f0e6-44ab-aba7-d6324451632f (Caused by SSLError(SSLCertVerificationError(1, '[SSL: CERTIFICATE_VERIFY_FAILED] certificate verify failed: certificate is not yet valid (_ssl.c:1123)')))"))

**To Reproduce**
Steps to reproduce the behavior:
part of the update process - and most/all reboots of any kind

**Expected behavior**
I even set my TZ to Kansas and still got similar error about 2 'latest' updates ago

**Log files**
If possible, add log files from `/var/log/mycroft/` to help explain your problem.

You may also include screenshots, however screenshots of log files are often difficult to read and parse.

If you are running Mycroft, the [Support Skill](https://github.com/MycroftAI/skill-support) helps to automate gathering this information. Simply say "Create a support ticket" and the Skill will put together a support package and email it to you.

*Environment:**
 - Device type: Mark-II -rPi4-DEVKIT on network cable, uSDC
 - OS: default (Mycroft) Ubuntu
 - Mycroft-core version: 20.08.??
 - Other versions: stable 04-06
[mycroft_stable_04-06.tar.gz](https://github.com/MycroftAI/hardware-mycroft-mark-II/files/6275163/mycroft_stable_04-06.tar.gz)

krisgesling, 2021-04-08:
Ken or @chrisveilleux might chime in and correct me but I believe this is because the Raspberry Pi doesn't contain a real-time clock (RTC).

What this means is that anytime the device powers down it reverts to it's factory standard datetime until it can boot, connect to an NTP server and get updated. Before the time gets updated, it will believe it's in 1970 and so the SSL cert process rejects the requests. Once it gets the correct time the connection handshakes start to succeed.

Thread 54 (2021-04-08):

stable 04-06 :: Skills.log errors noted

Olzeke51, 2021-04-08:
**Describe the bug**
Several errors noted between lines 0-40
ALSAAudioError error line 76 during update

**To Reproduce**
Steps to reproduce the behavior:
line 44 on a PullDownMenu : Restart, wait full cycle

**Expected behavior**
to be included in Container or removed from startup list (unless this is a future direction)

**Log files**
update file
[skills.log](https://github.com/MycroftAI/hardware-mycroft-mark-II/files/6275184/skills.log)
"Restart" file
[skills.log](https://github.com/MycroftAI/hardware-mycroft-mark-II/files/6275187/skills.log)

*Environment:**
 - Device type: Mark-II -rPi4-DEVKIT on network cable, uSDC
 - OS: default (Mycroft) Ubuntu
 - Mycroft-core version: 20.08.??
 - Other versions: stable 04-06

krisgesling, 2021-04-08:
Yeah this is caused by Skills trying to use the ALSA mixer to do their own modification of the system audio levels. This should all be handled by the Hardware Abstraction Layer (aka Enclosure).

It's been on the list to deal with for a while but hasn't been a priority so far.

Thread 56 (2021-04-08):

stable 04-06 :: missing digit '6' on standby display

Olzeke51, 2021-04-08:
**Describe the bug**
Just happened to notice that the '6' digit was missing from the clock display on the 'Standby Face'
[hadn't noticed/payed attention to it earlier]
see my additional comment

**To Reproduce**
not sure - just noticed it
Linux Mint was reporting 21:16 [EDT]
Mycroft report  21:1     and then it rolled over to 21:17 [as did Linux Mint]

*Environment:**
 - Device type: Mark-II -rPi4-DEVKIT on network cable, uSDC
 - OS: default (per Mycroft) Ubuntu 20.04.2 LTS
 - Mycroft-core version: 20.08.1 -per Home.Mycroft.AI device information
 - Other versions: stable 04-06

**Additional context**
from earlier testing - this seems to occur when UTC rolls over to a new /next day , while local is on 'today'
more often - but not 100 %

krisgesling, 2021-04-08:
This seems to be the same issue as #40 so will close for the moment and keep tracking that there. But if it is different, please reopen.

Closed 2021-04-08.

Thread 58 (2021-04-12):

Volume is muted; after sleep/wakeup commands

Olzeke51, 2021-04-12:
**Describe the bug**
after 'wake up' voice command - the volume is reduced to a 1 (led)

**To Reproduce**
Steps to reproduce the behavior:
1. Restart unit
2. set Volume to 4 via buttons
3. put unit to "Go to Sleep"
4. tell Mycroft "Wake Up"
5. It responds BUT can barely hear it
6. do a "Volume Up button" and it will be at a level 2 on the LED

**Expected behavior**
Maintain previous volume setting

**Log files**

[mycroft-0412am.tar.gz](https://github.com/MycroftAI/hardware-mycroft-mark-II/files/6295654/mycroft-0412am.tar.gz)

**Environment (please complete the following information):**
 - Device type: [Mark II DEV-kit , ethernet cable, uSDC
 - OS: Ubuntu - default
 - Mycroft-core version: [e.g. 20.08.1 ??? .
 - Other versions: 'latest' 04-08

ken-mycroft, 2021-04-27:
I just did this

hey mycroft - set the volume to 80%
hey mycroft - got to sleep
hey mycroft - wake up
hey mycroft - what's the volume set to
answer = 8

So I am not able to reproduce this behavior with the latest build. Perhaps this is an artifact of when sleep was not working correctly during earlier builds. Closing for now. If someone sees this again recreate the bug but I am not seeing it on my end.

j1nx, 2021-04-28:
@ken-mycroft He used the buttons on top. Did you try those? (To many places to set the volume 😊 )

Closed 2021-04-27.

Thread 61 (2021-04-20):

unknown system reboots

Olzeke51, 2021-04-20:
**Describe the bug**
had my 3rd update/ system generated reboot ???- without a change to the indicated timestamp on the 'Standby Face"

**Expected behavior**
a 'latest' update would change the date/time stamp on the Standby Face

**Log files**
[mycroft-0420-unknown-reboot.tar.gz](https://github.com/MycroftAI/hardware-mycroft-mark-II/files/6342604/mycroft-0420-unknown-reboot.tar.gz)

**Environment :**
 - Device type: Mark II dev-kit, network cable, uSDC
 - OS: Ubuntu - default
 - Mycroft-core version: 20.08.1
 - Other versions:"latest"-04-08

**Additional context**

krisgesling, 2021-04-21:
Hey, these were updates to the "Board Support Package" (BSP) - hardware compatibility layer for Pantacor - it was to address a memory leak that we identified.

The more important aspect of this ticket is something we've been talking about a lot - how do we best communicate everything that might change during an update. That includes updates to any container, not just the Mycroft one. It also includes what might have changed with mycroft-core, mycroft-gui, one of our many supporting technologies, or in the build recipe itself.

So a "Mark II" update may include many things at many different layers, and likely more than one of these. We need a simple way for end users to see what has changed, what's been fixed, what's been added. As well as a way to reference the overall system version, not just the mycroft container which is what the on screen timestamp currently represents.

ChanceNCounter, 2021-04-21:
Maybe the version skill should also offer changelogs. Not to be read out, that would be madness! To be displayed.

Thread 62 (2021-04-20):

Volume going UP skips the 8 value

Olzeke51, 2021-04-20:
**Describe the bug**
as VolumeUP switch is operated, the '8' LED does not illuminate.
 it illuminates  when 9 is reached !!!!

**To Reproduce**
Steps to reproduce the behavior:
1. Push the VolumeUP button, successively [or wait for ring to extinquish between pushes]

**Expected behavior**
the 8th volume LED to illuminate in sequence {this is the 10 o'clock position - btw} as volume is increased

**Log files**
partial 'Enclosure.log' of this bug
[VolumeUp_missing_8.txt](https://github.com/MycroftAI/hardware-mycroft-mark-II/files/6347203/VolumeUp_missing_8.txt)

**Environment :**
 - Device type: Mark II -pi4 -DEV_kit, network cable, uSDC
 - OS:  Ubuntu default
 - Mycroft-core version: 20.08.1
 - Other versions: 'latest' 04-08  && 3 other reboots/updates

ChanceNCounter, 2021-04-21:
Confirmed. Also confirmed that, as per title, the light appropriately remains illuminated when the volume is being *reduced*.

krisgesling, 2021-04-21:
Nice spotting!

ken-mycroft, 2021-04-27:
Rounding error. Fixed by https://github.com/MycroftAI/mycroft-core/commit/74285be60bcbdc0a37f369e6500bc5b55444358b

Closed 2021-04-27.

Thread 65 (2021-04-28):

Mycroft lost control of playing stream under specific circumstances

ChanceNCounter, 2021-04-28:
A few minutes ago, while testing which skills would capture certain requests, I did the following:

* Start a stream, confirm that the intent is captured and playback is initiated
* Issue "stop playback" immediately, before the stream had actually commenced
* Attempt to play a different station, which did not succeed

At this point, the first station started playing, but Mycroft doesn't seem to be in control of the player. It isn't displaying the media player screen, and "stop playback" doesn't work. I'm having trouble even finding the process to kill it.

ChanceNCounter, 2021-04-28:
Stopping and starting Mycroft did the trick, so at least we know it was still session-bound XD

krisgesling, 2021-05-11:
If I'm understanding the scenario correctly, I believe this comes back to the need for a more integrated audio and playback service. Spec doc in progress here:
https://docs.google.com/document/d/1ebS60QLna4_AOQxQYpoaZrpkBzPXjL-7VFPJ7-xVvIQ/edit?usp=sharing

Currently there's different ways that audio can be output, and mycroft-core is not necessarily aware of when that happens which I think is an issue.

Which Skill was this in particular?

ChanceNCounter, 2021-05-11:
Off the top of my head, I'm not sure, except that it must have been one of johnbart's radio skills, because I was fussing with how to trigger a couple local stations and their inconsistent keywords.

I'll poke through logs tomorrow, see if I can find it by keyword, but I'm not hopeful.

ChanceNCounter, 2021-05-11:
Alright. It looks like the IHeartRadio skill tied for, was selected for, and processed "play KEXP" at 19:37:27, and was also chosen from a tie for "710 ESPN" at 19:37:43.

The skill then attempted to do this, several times:

`self.gui["previous1Title"] = trackHistory_obj["data"][0]["title"]`

and gets `IndexError: list index out of range`

Hopefully soon I'll get the opportunity to paste more of the traceback - uncooperative multiplexer on this machine - but it's all just the skill working its way up to that call.

On the one hand, unlisted skill 🤷‍♂️ but, on the other hand, it clearly comes back to trying to interact with Mycroft's "now playing" features while they're still processing a previous request.

I think the discovery here may be the need for some kind of lock and queue on that stuff.

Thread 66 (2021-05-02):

Volume remains @ 10% after 'Wake Up'

Olzeke51, 2021-05-02:
**Describe the bug**
after the "Wake Up' command, volume is at a '1 or 10%' - can hardly hear it

**Expected behavior**
Volume to return to previous value.

**Log files**
condensed log of my testing and @gez-mycroft test per his closing of ticket #58

[muted_audio_after_sleep-wakeup.log](https://github.com/MycroftAI/hardware-mycroft-mark-II/files/6410624/muted_audio_after_sleep-wakeup.log)
***first 50 lines(or so) are setup/modifications of the combined log files, & a copy of @gez test
*****@gez test starts at about line 167

**Environment (please complete the following information):**
 - Device type: [Mark II - Dev kit - on network cable
 -Ubuntu default
- Mycroft-core version: ##### not sure
- ###!!#!#!#!!#!#  this is olzeke51's latest build info
I seem to be missing some 'latest' updates to this "stable"
MarkII_arm-rpi64_Prod_005-stable_2021-04-08.img.g
'
/.logs  - based primarily on "two-voices logs"
turned on the 'Stable' 04-30 02:39 UTC  - fresh copy to USB-stick
turned on "latest' at home.mycroft.ai / Device - (possibly 04-30 09:24 UTC- finished 09:27)
another update/restart at 04-30 09:34 UTC
logs./
'
these seem to be missing -  [based on 04-08 stable img.gz]
.....unless the 'latest' incorporate the previous patches???
'
04-10 - appears to be a BSP
'? another something or two
04-23 05:52:06 latest
04-26 12:54:06 latest
{fwi..04-28 server disk full}
[but now back online]
04-28 07:58:10 latest  **this is on the 'Standby Face currently
###!!#!#!#!!#!#

**Additional context** **************prolly a seperate issue, but wanted to FWIW
@gez and I might have different software versions, - him being a 'dev' vs. me/'user'
{I noticed my initial weather request used mimic2 , then mimic1 -- BUT on 05-01 {with V04-28} it is all mimic2 !!!!
AND I didn't do anything}

Olzeke51, 2021-05-04:
system updated itself to 04-28 latest @05-03 04:16 UTC [mentioned in my chat/skill this morning]
STILL have issue with muted volume
'
FWIW - only had two intermediate updates between the Prod_005 and the 04-28 'latest'
'
enclosure log (portion) for this evening's test of "sleep/wake up" volume
2021-05-03 22:24:47.912 | INFO     |   271 | mycroft.client.enclosure.mark2.interface:on_volume_get:326 | Mark2:interface.py get and emit volume 0.1
2021-05-03 22:24:47.961 | WARNING  |   271 | mycroft.client.enclosure.mark2.interface:on_volume_duck:302 | Mark2 volume duck deprecated! use volume set instead.
2021-05-03 22:24:50.225 | WARNING  |   271 | mycroft.client.enclosure.mark2.interface:on_volume_unduck:307 | Mark2 volume unduck deprecated! use volume set instead.
2021-05-03 22:24:50.446 | ERROR    |   271 | mycroft.client.enclosure.mark2.interface:run:140 | chase thread 1
2021-05-03 22:24:50.956 | ERROR    |   271 | mycroft.client.enclosure.mark2.interface:async_volume_handler:253 | ASYNC SET VOL PASSED IN 2
2021-05-03 22:24:50.957 | ERROR    |   271 | mycroft.client.enclosure.mark2.interface:async_volume_handler:257 | ASYNC SET VOL TO 0.2
2021-05-03 22:24:51.245 | ERROR    |   271 | mycroft.client.enclosure.mark2.interface:async_volume_handler:253 | ASYNC SET VOL PASSED IN 3
2021-05-03 22:24:51.390 | ERROR    |   271 | mycroft.client.enclosure.mark2.interface:async_volume_handler:257 | ASYNC SET VOL TO 0.3
2021-05-03 22:24:51.546 | ERROR    |   271 | mycroft.client.enclosure.mark2.interface:run:140 | chase thread 2
2021-05-03 22:24:51.988 | ERROR    |   271 | mycroft.client.enclosure.mark2.interface:async_volume_handler:253 | ASYNC SET VOL PASSED IN 4
2021-05-03 22:24:51.989 | ERROR    |   271 | mycroft.client.enclosure.mark2.interface:async_volume_handler:257 | ASYNC SET VOL TO 0.4
2021-05-03 22:24:52.168 | ERROR    |   271 | mycroft.client.enclosure.mark2.interface:async_volume_handler:253 | ASYNC SET VOL PASSED IN 5
2021-05-03 22:24:52.169 | ERROR    |   271 | mycroft.client.enclosure.mark2.interface:async_volume_handler:257 | ASYNC SET VOL TO 0.5

Olzeke51, 2021-05-12:
the last two 'latestest' updates; 05-09 & 05-11 - it is working !!!
It used to be 10% consistently - so sumptin' happened
never changed any configs manually - just whatever "latest" @ home would do ....

krisgesling, 2021-05-13:
I think it might be still there, just very rare, so potentially there's some race condition or other interruption that only causes the bug to happen in very specific circumstances.

Glad it's working for you now though, we'll keep an eye out for it.

Olzeke51, 2021-05-18:
it has occured again on the 18th of May : put to sleep this morning,  woke it up [15:30ish]>> to a low volume
just did it again 16:30-ish and still low volume  {all times are EDT / east coast US/NY time zone
[mycroft_wake_up-muted-0518.tar.gz](https://github.com/MycroftAI/hardware-mycroft-mark-II/files/6504341/mycroft_wake_up-muted-0518.tar.gz)

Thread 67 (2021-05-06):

Mycroft seems slower to respond on the Mark II

krisgesling, 2021-05-06:
**Describe the bug**
Have had it raised by community members that responses to queries sometimes seem very slow on the Mark II where they are not on other instances of Mycroft. It seems that this may be caused by the listener silence detection not working correctly.

By default Mycroft will listen for up to 10 seconds before sending this to an STT service for transcription. However as many utterances are much less than this, if there is a long enough period of silence, Mycroft will consider the utterance finished and send the audio earlier than that 10 seconds.

I'm seeing that sometimes the listener remains open for the whole 10 seconds, even if the user is not speaking. This makes it seem like the processing is taking a very long time but it's actually listening for too long.

I presume this is related to the silence detection and may differ based on the audio input being received.

If that's the case, consideration should be given to making whatever fixes it configurable so it can be defined in `mycroft.conf` or the Hardware Abstraction Layer and hence differ from device to device.

**To Reproduce**
Steps to reproduce the behavior:
1. Open the mycroft-cli-client
2. Speak to Mycroft
3. Watch when the mic is activated and stopped.

ChanceNCounter, 2021-05-06:
+1 Gez's suspicion that it's related to silence detection, as I've noticed the record phase lasting all 10 seconds a number of times. I hadn't reported this because I assumed it was just me; I have mine on a floor of the house with lots of fans, and it's not *every* time.

j1nx, 2021-05-11:
Isn't the sound of the Mark-2 fan causing this? Perhaps have a look at the CPU temp / LED to see if it happens when the fan is at maximum speed.

j1nx, 2021-05-11:
Luckily easy to initially test. Just start by recording some WAV files with the fan connected and disconnected.

To be honest, at max speed the fan is relativily noisy. Especially if you consider there are only a few centimeter between the fan and the right mic on the board.

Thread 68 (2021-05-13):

latest 05-11 ; 'Latest News" skill not getting home.mycroft settings

Olzeke51, 2021-05-13:
**Describe the bug**
home.mycroft.ai  account / skill setting for "Latest News" station Fox News or Georgia Public is NOT getting to my Mycroft M2

**To Reproduce**
Steps to reproduce the behavior:
1. Change the Skill radio station per pull down list on web home=account
2. tell Mycroft to "update configuration"  reply is 'no changes' or similar [hasn't changed]
3.
4. pwer cycle doesn't call in the settings either

**Expected behavior**
a) when I tell Mycroft to 'update configuration', the station specified on my web account skill setting to be selected/played
or
b) when system is rebooted - to pull in the information from my web account skill setting

**Log files**
[wrong_news.txt](https://github.com/MycroftAI/hardware-mycroft-mark-II/files/6469769/wrong_news.txt)
enclosure skill log only showed a 'chase LED' at the 23:46 ;otherwise CPU temperature

**Environment (please complete the following information):**
 - Device type: MarkII-dev_kit, network cable , uSDC card
 - OS: [e.g. Ubuntu default
 - Mycroft-core version: [e.g. 20.08.1  - per my home.mycroft account
 - Other versions:       latest 05-11

**Additional context**
I had to manually edit ::
'(.venv) mycroft@localhost:/opt/mycroft/skills/mycroft-npr-news.mycroftai$   settingsmeta.json '
to get FOX news
.
I changed my web/home account to 'Georgia Public Radio'  THEN PowerCycled to see if it would pull it in - nope

krisgesling, 2021-05-13:
Can confirm there is a bug for Georgia Public Radio but selecting FOX on the backend works fine for me.

Can you try that one again using an unmodified Skill?
```
git stash
```
^^ that will remove all your local changes to the Skill

You can see the settings retrieved from the server in this file:
```
cat ~/.config/mycroft/skills/mycroft-npr-news.mycroftai/settings.json
```

So first we want to confirm whether it does change to FOX after you change that on [home.mycroft.ai/skills](https://home.mycroft.ai/skills), then we can know if the issue exists in the Skill settings process, or in how the Skill is using those setttings.

krisgesling, 2021-05-17:
I did a bugfix for the Georgia Public Radio setting however the station itself has stopped updating their public RSS feed. So if we can't find an alternative source we'll need to remove it entirely.

If you get a chance to try another station in your settings and let us know if that syncs to the device that would be great!

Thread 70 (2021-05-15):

Multiple issues (??with 05-13 latest) primarily LED ring lights

Olzeke51, 2021-05-15:
**Describe the bug**
system has been running since "2021-05-06 01:15:03.787" per the 'bus.log' [a long time for me]
system was basically useable ['news' & wakeword - excepted]
put unit to 'sleep' Fri night :: but 'woke' it Saturday and had issues with LED ring indications
troubleshooting the LEDs - ran into an issue with the 'Volume' skill

**To Reproduce**
Steps to reproduce the behavior:
long running on latest(s) ???
*
Saturday the 15th : not sure what part Mycroft-core plays in my issues but here is a short list - will do some issues in "hardware-mycroft-mark-II" officially

put unit to sleep 00:57 may 15 UTC -  [all inputs are via a mechanical switch - Hey Ezra is very sporadic]

'woke it up' @ approx 10:30 UTC - had no 'listen ring' -but had the bee-bop

@11:19 ish UTC - played with volume switch [to see the LEDs] but no led-indication - volume did change !!

while it was timing out on a "what time is it" told it to "set volume to 50%"  - RESponded with 'setting BRIGHTness to 50%"

checked the "https://github.com/mycroftai/skill-volume/tree/d6527214faf8797b06c8db7ca271f9884c4fa01f' and used it's example to set it to 7 --STILL got a 'brightness' response

long running issue -- the 'News' skill doesn't release it's gui after doing the news  AND the top-control/pull down menu won't select the 'Standby Face' !!!! [I usually ask for 'time' and it is back to normal]

**Expected behavior**
LEDs to respond in the proper manner - missing the 'thinking' LEDs also

**Log files**
[mycroft-05-15_am_multiple.tar.gz](https://github.com/MycroftAI/hardware-mycroft-mark-II/files/6487116/mycroft-05-15_am_multiple.tar.gz)

**Environment (please complete the following information):**
 - Device type: Mark2-Dev_kit , on network cable, uSDC
 - OS: default Ubuntu
 - Mycroft-core version:  20.08.1 -per Device setting @ home.mycroft account
 - Other versions:  latest 05-13 02:22:00 on top of MarkII_arm-rpi64_Prod_005-stable_2021-04-08.img.gz

**Additional context**
have not changed any git-hub settings or manual configs (except web settings),
not on 'dev' afaik  - unless it is part of a 'latest'

Olzeke51, 2021-05-15:
21:45 to 22:20ish UTC  - several requests - ALL had LED 'appropriate illumination' - !!!!
didn't do a thing
looking at 'enclosure.log - I see the 'Chase led' command was registered  all the times as expected - earlier this morning!!!

krisgesling, 2021-05-17:
Thanks Gary. It's also great that you have split this out into multiple tickets so I've modified this issue a little to keep it focused on what's not covered in the others.

krisgesling, 2021-07-06:
@Olzeke51 reported another instance of non-standard LED behaviour in Chat.

> BAD NEWs - the 'latest'  - whoops - had a reboot overnight on the latest of 07-03 -- BUT I don't get the circle of LEDs for listening & thinking !!! - - even after my own 'turn off from menu' !!!!
> I do get the 'temp & mic' LEDs  - off to work
> Power Cycle cleared it up - to all indications !!

Logs posted here:
https://chat.mycroft.ai/community/pl/njjo5t3zb38xxdnze3f3xt77qy

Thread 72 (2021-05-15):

'Volume' skill command being interpreted as a 'Brightness' intent

Olzeke51, 2021-05-15:
Describe the bug
system has been running since "2021-05-06 01:15:03.787" per the 'bus.log' [a long time for me]
system was basically useable ['news' & wakeword - excepted]
put unit to 'sleep' Fri night :: but 'woke' it Saturday and had issues with LED ring indications
troubleshooting the LEDs - ran into an issue with the 'Volume' skill

To Reproduce
Steps to reproduce the behavior:
long running on latest(s) ???
*
@11:19 ish UTC - played with volume switch [to see the LEDs] but no led-indication - volume did change !!

while it was timing out on a "what time is it" told it to "set volume to 50%" - RESponded with 'setting BRIGHTness to 50%"

checked the "https://github.com/mycroftai/skill-volume/tree/d6527214faf8797b06c8db7ca271f9884c4fa01f' and used it's example to set it to 7 --STILL got a 'brightness' response

Expected behavior
Volume skill to respond with the new setting it was commanded

Log files
[mycroft-05-15_am_multiple.tar.gz](https://github.com/MycroftAI/hardware-mycroft-mark-II/files/6487447/mycroft-05-15_am_multiple.tar.gz)

Environment (please complete the following information):

Device type: Mark2-Dev_kit , on network cable, uSDC
OS: default Ubuntu
Mycroft-core version: 20.08.1 -per Device setting @ home.mycroft account
Other versions: latest 05-13 02:22:00 on top of MarkII_arm-rpi64_Prod_005-stable_2021-04-08.img.gz
Additional context
have not changed any git-hub settings or manual configs (except web settings),
not on 'dev' afaik - unless it is part of a 'latest'

Chat channel response:  [might provide a clue]
sgee_  9:02 AM
the brightness/volume problem is likely to be found in the intent construction (here/here(Adapt->scattered))
a too loose intent tend to mix up things

krisgesling, 2021-05-17:
Based on additional info in Chat, a bugfix for the volume intent not catching has been submitted:
https://github.com/MycroftAI/skill-volume/pull/74

Olzeke51, 2021-05-18:
based on input for gez-mycroft - files were missing from the skill folder, reinstalled and volume now responds properly
His question (and mine) is how did those files come up missing - my suggestion was that part of the 'fix' for the missing '8' led/volume bug issue may have done an incomplete replacement.
'
i consider this issue closed - but the 'skill-volume#74 did catch an other issue with the STT engines
it would be hard to diagnose why my files were missing..........Gary

Closed 2021-05-18.

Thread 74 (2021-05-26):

latest 05-26 04:58:55 didn't update to 21.02

Olzeke51, 2021-05-26:
**Describe the bug**
M2-devkit updated itself last night and now reports the software needs to be updated

**To Reproduce**
1. Ask '| __main__:handle_utterance:76 | Utterance: ['what is software version']
2. it reports that I am still at 20.08.1
3.it also says to do a 'git pull' in the mycroft-core folder - can't find it

**Expected behavior**
per the announcement = I thought I would be updated

**Log files**
[mycroft_21-02_update.tar.gz](https://github.com/MycroftAI/hardware-mycroft-mark-II/files/6546400/mycroft_21-02_update.tar.gz)

**Environment (please complete the following information):**
 - Device type: Mark II Dev-kit on network cable
 - OS: [e.g. Ubuntu default
 - Mycroft-core version: apparently 20.08.1
 - Other versions: LATEST 05-26 04:58:55

**Additional context**
this link has an old image - [was going to start fresh as had several issues with the older latest(s)]
https://mycroft-ai.gitbook.io/docs/using-mycroft-ai/get-mycroft/mark-ii    - as of 11:30 ish  UTC

Olzeke51, 2021-06-07:
unit has been updated, @gez-mycroft did a new stable, installed , and now the web/home account shows 21.2 as being installed
closiing this

Closed 2021-06-07.

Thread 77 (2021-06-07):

'News' skill shows no 'gui display of station selected'

Olzeke51, 2021-06-07:
**Describe the bug**
asked for 'latest News' - both NPR & Fox gui was not shown
FWI-NOTE: NPR was selected even though 'Georgia Public Radio' was the web/home account skill setting

**To Reproduce**
Steps to reproduce the behavior:
1. ask for 'the latest news'

**Expected behavior**
Used to get a gui of the responding station ; that was selected on the skill setting @ web/home account

**Log files**
[mycroftM2-no_news_gui-0602latest.tar.gz](https://github.com/MycroftAI/hardware-mycroft-mark-II/files/6611511/mycroftM2-no_news_gui-0602latest.tar.gz)

**Environment (please complete the following information):**
 - Device type: MarkII-Devkit on network cable, uSDC
 - OS: default Ubuntu
 - Mycroft-core version: 21.2   - yay!
 - Other versions: latest 0602_08:13:31

**Additional context**
had just done a power-cycle , [due to a failed 'shutdown' voice command]
did the shutdown to see if there was a bug that would be cleared on power up !!!  NOPE

krisgesling, 2021-06-08:
Yeah this one is known - if you ask using a "play" command eg "play the news" you'll get the GUI (which also needs work).
If you ask using a standard intent eg "what's the news" you don't get the GUI.

Ken's starting to look at all the Common Play stuff now and will include this.

ken-mycroft, 2021-06-17:
Starting to investigate whether this is an issue with a hybrid intent match vs a common play intent match. Will update ticket with progress.

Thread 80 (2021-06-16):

FWIW - one time event upon a pwr cycle after a verbal 'shutdown'

Olzeke51, 2021-06-16:
**Describe the bug**
Haven't been able to reproduce"
on startup
couldn't find network connection/ reverted to partial wifi connection procedure/prompts [was aborted by Mycroft]
unusual representation of voice - by using circles

**To Reproduce**
1. Gave Mycroft verbal "shutdown" command, verified it
2. Screen had some terminal text, then went black
3. Power cycled - as it didn't reboot itself as in the past -- A STEP forward
4. on startup - British said couldn't get Internet connection,/ via wifi
5. had the second graphic screen of a phone app,
6. THEN (about 30 secs later) got the British voice  ....AND round circles as if a mouth, big, then smaller inside, big, etc
7. approx 20 secs later - was at the 'Standby Face/screen'

**Expected behavior**
1) to have network connection - as I normally do
2) not to have the British voice (I know - fallback for no network)
3) have NEVER seen the round circle/voice simulation

**Log files**
action started at 06-16 18:44:nn in log files
[strange_startup.tar.gz](https://github.com/MycroftAI/hardware-mycroft-mark-II/files/6665684/strange_startup.tar.gz)

**Environment :**
 - Device type: Mark II -Dev_kit ; ON Network cable [no wifi- afaik]
 - OS: Ubuntu-default
 - Mycroft-core version: 21.2
 - Other versions: latest 06-16 02:09:36

krisgesling, 2021-07-06:
Some interesting behaviour.

1 and 2 expected behaviours will be fixed in the Wifi Setup Skill. Going to give it longer to detect a network connection if credentials already exist, before offering to setup a new one. As opposed to when the system can see that no wifi credentials exist and it's not connected to ethernet, then we can assume the user wants to setup wifi asap.

Number 3 I'll have to dig into a bit more as to why that showed up. It's an animation we haven't been using lately but never fully removed, so it shouldn't raise security concerns or anything. We do have on our backlog a ticket to look at these anyway.

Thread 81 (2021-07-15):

Device setup via local start.mycroft.ai for internet connection should support captive-portal wifi

jrwarwick, 2021-07-15:
**Is your feature request related to a problem? Please describe.**
Some environments, such as workplace or hotel rooms or cafes, offer wifi internet connections that makes use of a "captive-portal" [RFC7710](https://datatracker.ietf.org/doc/html/rfc7710) wherein after your device has associated, you are still kind of “sandboxed” by routing all traffic to a "portal" webpage until you click on some kind of “Accept” button (perhaps attached to a liability waiver and good-behavior policy acknowledgement). I find that I am unable to get my mycroft mkII connected to the internet in such an environment.

Also, in many cases captive-portal style APs do not require a password at all. I have noticed that currently, the start.mycroft.ai page (which, funny enough, is clearly a localized captive portal of its own) disallows empty passwords by disabling the "Connect" button if I do not enter anything in the password input box. So actually I have not been able to test whether mycroft has general captive portal support, but I suspect that it does not.

**Describe the solution you'd like**
1. The start.mycroft.ai page should allow empty passwords
2. After associating (and perhaps any time internet _appears_ to be down), mycroft should attempt to detect captive portals and if detected, present the portal page on-screen so that the user can click accept and thus get mycroft connected to the internet.

**Describe alternatives you've considered**
No alternative is possible yet due to problem 1.

**Additional context**
Mobile phone experience/processflow is a reasonable example of how a user would expect to work through a captive-portal.

jrwarwick, 2021-09-10:
I have just discovered another, related deficiency. Start.Mycroft.ai instructs me to "Please choose your WiFi from the list below." It does not offer an option to enter a hidden/non-broadcast SSID. Should I edit above to include that as well? Or file a new enhancement request issue?

jrwarwick, 2021-09-24:
After some more rumination, it seems to me that after initial acceptance of captive portal agreement via GUI, Mycroft should ask permission to automatically renew the TOS acceptance on your behalf, and attempt to do so each time general network connectivity appears to fail. This is an _Artificial Intelligence_, after all.
So that would require a stateful record of user permission, per SSID, and some kind of fancy dynamic DOM navigator (e.g., injected javascript or some kind of hack on a "testing framework" like selenium, WebDriver, protractor, etc.) that will fairly reliably identify and "click" checkboxes and/or a button or button-like-html-element that says something like "I agree" or "Accept" or "Continue" or "Confirm", etc. And of course fall-back to asking the human user for help if it doesn't work out.

krisgesling, 2021-09-27:
This would be cool.

Would need to look at the legal around this but you're essentially caching a response, with permission. So would also want to verify that the agreement itself hadn't changed. Which could actually be a feature in itself:
> Hey, you said to auto-accept but the Terms of Service have changed - we've emailed you a diff showing exactly what has changed.

jrwarwick, 2022-02-18:
In case this does not bubble up on its own: I did notice some Mark 1 work appears to have been done on this whole issue:  https://github.com/MycroftAI/mycroft-wifi-setup/issues/26 though its not clear to me what the end result was.

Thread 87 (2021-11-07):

First boot fails. Where can I look for symptoms to debug?

enorberg, 2021-11-07:
**Describe the bug**
Just put my Mark-II Dev Kit together. Trying to boot for the first time, but it fails.

**To Reproduce**
Steps to reproduce the behavior:
1. Apply power.
   RPi Red power led is on.
   RPi Green led is on for several seconds - as though reading USB Drive.
   Then goes out and after a few seconds, flickers once.
   SJ-201 shows blue leds circling for ~ 1 min.
   SJ-201 flashes red led circle.
   SJ-201 flashes yellow/white led circle. Then leds off.
   There is no other activity.
2. Wait 5 min, then power off.

**Expected behavior**
Boot and go into WiFi setup .. then device registration.

**Log files**
N/A

I'm looking for diagnostic suggestions.
- I've tried the USB drive in both of the USB-3 ports with the same results.
- Should I be able to hook up a monitor and get useful feedback?
- Other?

I've had this Dev Kit since sometime this summer and just now had time to work on it.
I created the Image file with dd on my linux (ubuntu) laptop from
      MarkII_arm-rpi64_Prod_012-stable_2021-08-19.img.gz
  after unzipping.

Thanks for your help.

ChanceNCounter, 2021-11-07:
Does the screen do anything? Maybe a screen test when power is applied? I'm wondering about the ribbon connector. Just a thought.

enorberg, 2021-11-07:
There is nothing shown on the screen. I visually inspected the ribbon
connector and it appears properly seated on both ends.
Part of my problem is I don't know what to expect to see at boot. The only
thing I know about is the RPi status leds from their docs.

Thanks.

On Sun, Nov 7, 2021 at 9:30 AM ChanceNCounter ***@***.***>
wrote:

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

krisgesling, 2021-11-08:
Hey @enorberg - sorry to hear you're having trouble.

If you're not getting any audio output after boot then I think it points to more than a display issue.

Another thing to check is that the 40 pin connector between the pi and the SJ201 is nicely fitted. It must be getting power to the pi if that has LED's lit up but if some pins aren't connecting properly it won't successfully boot.

enorberg, 2021-11-08:
Hi @krisgesling, thanks for the suggestions.

There is no audio at any point - only the SJ201 led displays (circling blue, momentary all red then momentary all yellow).
I did check the 40 pin connector and it is completely snugged up between the RPi and the SJ201.

The only other thing I can think of is to re-image the USB drive.

The 1st time, I simply expanded the downloaded .gz file and used dd to copy the .img to the USB.

I am going to try the other method mentioned in the instructables.com page that involves downloading the Raspberry Pi Imager app.  Then I'll use that to write the USB drive in case I was wrong that both methods are equivalent.

If that doesn't fix the issue, would there be useful output from the RPi mini-hdmi port at boot time?
I could disassemble the Mark-II enough to hook up a monitor if there's something to see and no other diagnostic option.

MetaGamer, 2021-11-08:
If the blue circle animation on the SJ201 LEDs stops, it means the HAL is at least working. Which makes me think it's booting fine and it's a display issue. I'd double check the ribbon cable to the display- it's easy to put it in backwards. As for sound- even without a resonating chamber you should be able hear the speakers.

Do the buttons do anything? The two front buttons should make the ring-LEDs temporarily light up with the current volume, and the left switch should cause on LED to turn red to indicate that the mic is disconnected.

enorberg, 2021-11-08:
Hey @MetaGamer, thanks for the suggestion. This helped a lot! ... but now another issue.

I checked the ribbon cable and questioned the SJ201 end.  It "looked" correct per the pix on the instructables.com page - see screen shot below.  BUT that shows the exposed conductors facing outboard so they don't make contact with the board.  I reversed this and the Dev Kit now boots with both audio and video output.

However, when prompted to join the temporary Mycroft network, I couldn't find it.  I saw several other neighbor's wifi networks, but no "Mycroft".   - I tried this with an iPhone8, a ubuntu desktop and a MacMini but none of them could see the Mycroft network.

There was a prompt to go to start.mycroft.ai, but that site appears to be down.  I'm going to try again later tonight.

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

enorberg, 2021-11-08:
...oops - not the SJ201 attachment - the LCD attachment - sorry.

krisgesling, 2021-11-09:
Ah, that is a good thing for us to fix up!!

Did the wifi network show up after a reboot? If it's still happening it would be good if we could dig into it to figure out what's going wrong. Do you have an ethernet connection available at all?

enorberg, 2021-11-09:
The network did not show up after reboot.
I do have an ethernet connection that I can connect to.  Let me know what
I need to do.

On Tue, Nov 9, 2021 at 12:35 AM Kris Gesling ***@***.***>
wrote:

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

krisgesling, 2021-11-10:
Damn, but good that you have ethernet available.

First is a short list of the network manager connections:
1. Plug in via ethernet and get paired
2. Add an SSH key to that device in your account
3. SSH into the awconnect container:
```
ssh -p 8222 awconnect@$IPADDRESS
```
4. Send us the output of the following command:
```
nmcli c
```

-------------------------------------
Second, if you’re happy to temporarily share your device logs with us it would also be great if you could

1. login to the main mycroft container:
```
ssh -p 8222 mycroft@$IPADDRESS
```
2. Get your device-id and send that to us:
```
sudo cat /pantavisor/device-id
```
3. Shutdown the device and plug the usb into a computer
4. In the pvboot partition, edit `cmdline.txt`
  change the final
```
ph_log.push=0
```
to
```
ph_log.push=1
```
This will push your device logs to our backend, so we then need to replicate the issue:
1. shutdown the device
2. remove the ethernet cable
3. plug the device back in and see if the mycroft wifi AP has been created
4. wait at least 3-5 minutes after it’s booted to ensure it’s definitely not showing up
5. plug in the ethernet cable to connect to the net and have the logs uploaded.
6. run `nmcli c` again to see if anything has changed there.

Thanks

krisgesling, 2021-11-10:
The device-id does uniquely identify your device but it's not something anyone can use against you. Even so, if you'd prefer to send things to me privately my email is kris.gesling@mycroft.ai

enorberg, 2021-11-10:
Here's the result of nmcli c

***@***.***:~# nmcli c
NAME                UUID                                  TYPE      DEVICE
Wired connection 1  5e9542b9-59e6-3226-a672-7530649159fc  ethernet  eth0

lxcbr0              3cf08c2d-bae6-4cb2-92d5-8a4e8f3283f1  bridge
lxcbr0

I'll be getting the logs to you next.

On Wed, Nov 10, 2021 at 12:00 AM Kris Gesling ***@***.***>
wrote:

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

enorberg, 2021-11-10:
Here's the device-id

(.venv) ***@***.***:~$
(.venv) ***@***.***:~$ sudo cat /pantavisor/device-id
618c03e4790fa6000ad81c62
(.venv) ***@***.***:~$

On Wed, Nov 10, 2021 at 1:01 PM Eric Norberg ***@***.***>
wrote:

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

enorberg, 2021-11-10:
I shut down the DevKit,
edited the cmdline.txt file from my ubuntu desktop
removed the ethernet cable from the DevKit & repowered it.
After boot up, got the "connect to Mycroft network" display - but no such
network  visible from iPhone nor from desktop.
Waited about 5min, still no Mycroft network
Replaced ethernet cable ... after a few seconds, got Connect display and
later normal Mycroft screen
ssh back to awconnect and ran nmcli again - here is the output:
***@***.***:~#
***@***.***:~# nmcli c
NAME                UUID                                  TYPE      DEVICE
Wired connection 1  5e9542b9-59e6-3226-a672-7530649159fc  ethernet  eth0

lxcbr0              546093ca-3842-47ce-a1b0-1854d1b708ae  bridge
lxcbr0
***@***.***:~#

======
Mycroft seems to respond to normal commands - eg "Hey Mycroft, what time is
it"  -- etc.

On Wed, Nov 10, 2021 at 1:03 PM Eric Norberg ***@***.***>
wrote:

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
>>> The device-id does uniquely identify your device but it's not something
>>> anyone can use against you. Even so, if you'd prefer to send things to me
>>> privately my email is ***@***.***
>>>
>>> —
>>> You are receiving this because you were mentioned.
>>> Reply to this email directly, view it on GitHub
>>> <https://github.com/MycroftAI/hardware-mycroft-mark-II/issues/87#issuecomment-964812651>,
>>> or unsubscribe
>>> <https://github.com/notifications/unsubscribe-auth/AABBZXV6KIN5FQGTB5HR6I3ULIC5ZANCNFSM5HQLNTGQ>
>>> .
>>> Triage notifications on the go with GitHub Mobile for iOS
>>> <https://apps.apple.com/app/apple-store/id1477376905?ct=notification-email&mt=8&pt=524675>
>>> or Android
>>> <https://play.google.com/store/apps/details?id=com.github.android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>.
>>>
>>>
>>

enorberg, 2021-11-10:
Just to check ---
I have disconnected the DevKit from power and from the ethernet cable.
If it's useful for it to remain powered on and connected, I can arrange
that. - Let me know.

On Wed, Nov 10, 2021 at 1:37 PM Eric Norberg ***@***.***>
wrote:

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
>>> Here's the result of nmcli c
>>>
>>> ***@***.***:~# nmcli c
>>> NAME                UUID                                  TYPE
>>>  DEVICE
>>> Wired connection 1  5e9542b9-59e6-3226-a672-7530649159fc  ethernet  eth0
>>>
>>> lxcbr0              3cf08c2d-bae6-4cb2-92d5-8a4e8f3283f1  bridge
>>> lxcbr0
>>>
>>> I'll be getting the logs to you next.
>>>
>>> On Wed, Nov 10, 2021 at 12:00 AM Kris Gesling ***@***.***>
>>> wrote:
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

krisgesling, 2021-11-22:
Hey @enorberg sorry for the radio silence - just wanted to say thanks heaps for the logs - they came through perfectly.

The team have finally been able to replicate the issue and are working on a fix. I'll hopefully have more details on _what_ went wrong soon too.

enorberg, 2021-11-22:
Glad it's replacatable (and not just me).  Let me know if there's anything
else I can do.

On Sun, Nov 21, 2021 at 11:14 PM Kris Gesling ***@***.***>
wrote:

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

GameGuy1900, 2021-12-26:
Is there already a solution to this problem?

enorberg, 2021-12-26:
Not that I'm aware of.

On Sun, Dec 26, 2021 at 12:16 PM GameGuy1900 ***@***.***>
wrote:

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

GameGuy1900, 2021-12-26:
Okay, that's too bad

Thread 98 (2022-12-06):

Inconsistent results when getting the news. Plays an AP News segment .mp3 from 2020

SkyLundy, 2022-12-06:
**Describe the bug:**
Inconsistent results when attempting to get the news. When I received my Mark II the news did not work and would cause Mycroft to hang until giving a "stop" command. Setting the news source to AP News in the web UI did not solve the problem. Did not attempt to use the News skill again until today.

Attempted to get the news today and it [plays an .mp3 file from an API for Spreaker](https://api.spreaker.com/download/episode/25675659/7559816.mp3). The news contains references to events and people from early 2020. This behavior is static and does not change with the hour.

**To Reproduce:**
Say "Mycroft, play the news" to Mycroft Mk II

**Expected Behavior:**
The current news for this hour is played

**Log Files:**
[Gist of log entries](https://gist.github.com/SkyLundy/498a68f7f42be57a6c367633f713f975)
Log contains entries from initial news command to completion of the news .mp3 playing. Log contents are from `journalctl`, there is no directory/file located at `/var/log/mycroft/`

**Environment:**
 - Device type: Mark II
 - OS: Dinkum
 - Mycroft-core version: 21.2.1
 - Other versions: Unknown or N/A

**Additional Context:**
No changes other than setting the source to AP News in the Web UI weeks ago.
No changes have been made to any Mycroft on-device configuration files
Device has had uninterrupted internet connectivity
Device has been running as received in early November
Contents of `/home/mycroft/skills/news.mark2/settings.json` is
`{"station": "AP", "custom_url": ""}`

krisgesling, 2022-12-07:
Yikes, Covid is still a thing but that definitely sounds like a 2020 clip. Seems like the feed we're using for AP might be broken or outdated.

SkyLundy, 2023-01-08:
@krisgesling Close ticket, I realized that I submitted this in the wrong place and have relocated it to [the Dinkum repository](https://github.com/MycroftAI/mycroft-dinkum/issues/57).

Closed 2023-01-09.

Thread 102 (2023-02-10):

Mark II enclosure/housing files

janknieling, 2023-02-10:
Hi,

can you pleae add the CAD files (or stl) of the enclosure/housing and a full BOM with all components (speaker, microphones, display etc.)  for the Mark II production unit?
It seems that they are missing in the repo.

Thank you

krisgesling, 2023-02-16:
Hey Jan, just FYI - I'm pestering multiple people to make sure we have all this up to date.

krisgesling, 2023-03-06:
An update on this. See:
https://github.com/MycroftAI/hardware-mycroft-mark-II/tree/master/mark-II-production

There's a STEP file under `mechanical`, and assembly instructions with images.

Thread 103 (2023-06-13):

Mark II Production missing KiCad PCB Layout file

rf152, 2023-06-13:
The KiCad project is missing the PCB layout file. The project includes the schematic, but is it possible to get the board layout added as well?

netkruzer, 2023-06-13:
Sorry, I don't know how I missed that file. [Here you go, uploaded](https://github.com/MycroftAI/hardware-mycroft-mark-II/blob/master/mark-II-production/SJ-201-R10.kicad_pcb)

Closed 2023-06-13.

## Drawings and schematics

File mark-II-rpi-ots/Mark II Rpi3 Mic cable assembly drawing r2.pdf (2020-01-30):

# MARK II PROTOTYPE AMPLIFER CABLE I2C

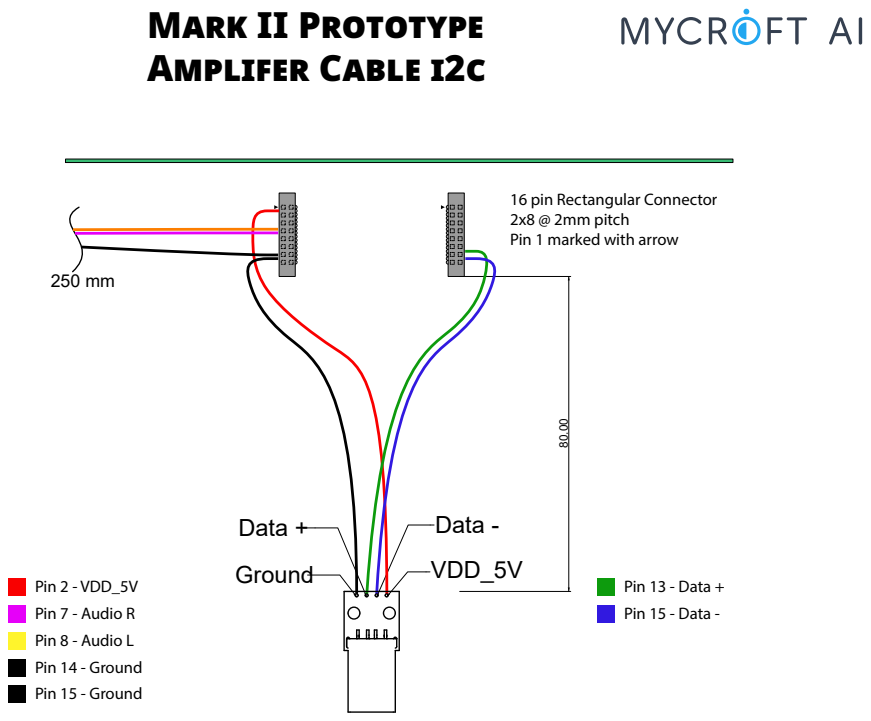
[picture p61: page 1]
Data + Ground; Data - VDD_5V; Pin 2 - VDD_5V Pin 7 - Audio R Pin 8 - Audio L Pin 14 - Ground Pin 15 - Ground; Pin 13 - Data + Pin 15 - Data -

16 pin Rectangular Connector
2x8 @ 2mm pitch
Pin 1 marked with arrow

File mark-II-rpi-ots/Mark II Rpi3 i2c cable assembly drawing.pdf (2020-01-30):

## MARK II PROTOTYPE AMPLIFER CABLE I2C

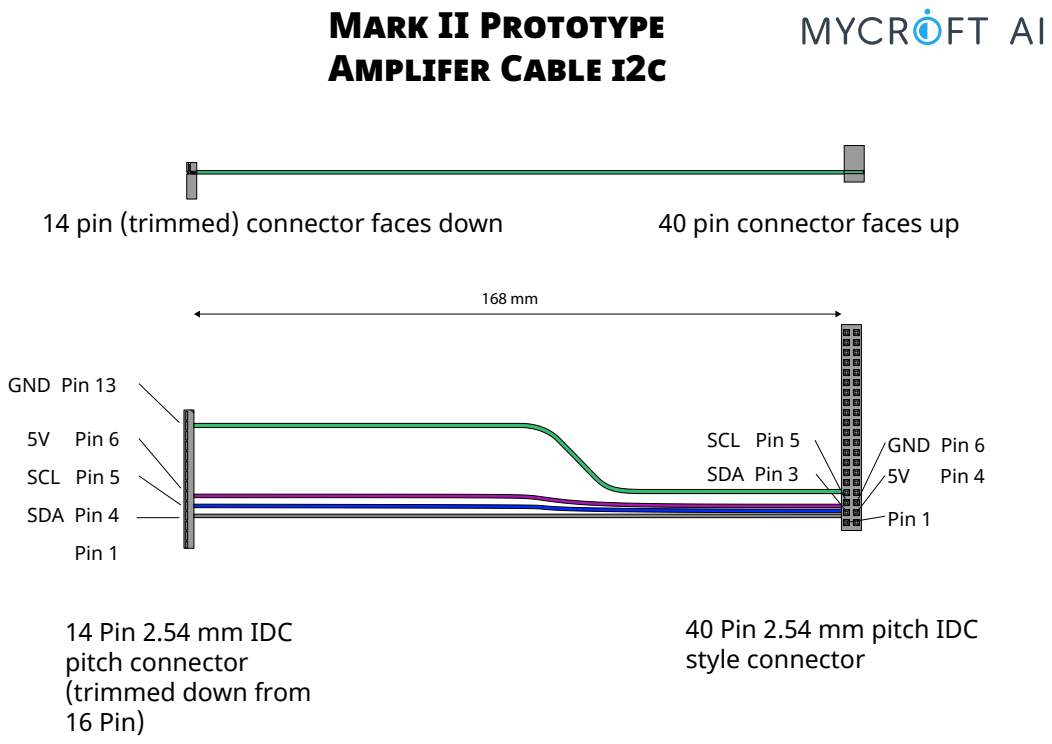
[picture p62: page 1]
SCL Pin 5 SDA Pin 4; 5V Pin 6; GND Pin 13; Pin 1; SCL Pin 5; SDA Pin 3; 5V Pin 4; GND Pin 6; 14 pin (trimmed) connector faces down; 40 pin connector faces up

40 Pin 2.54 mm pitch IDC
style connector

14 Pin 2.54 mm IDC
pitch connector
(trimmed down from
16 Pin)

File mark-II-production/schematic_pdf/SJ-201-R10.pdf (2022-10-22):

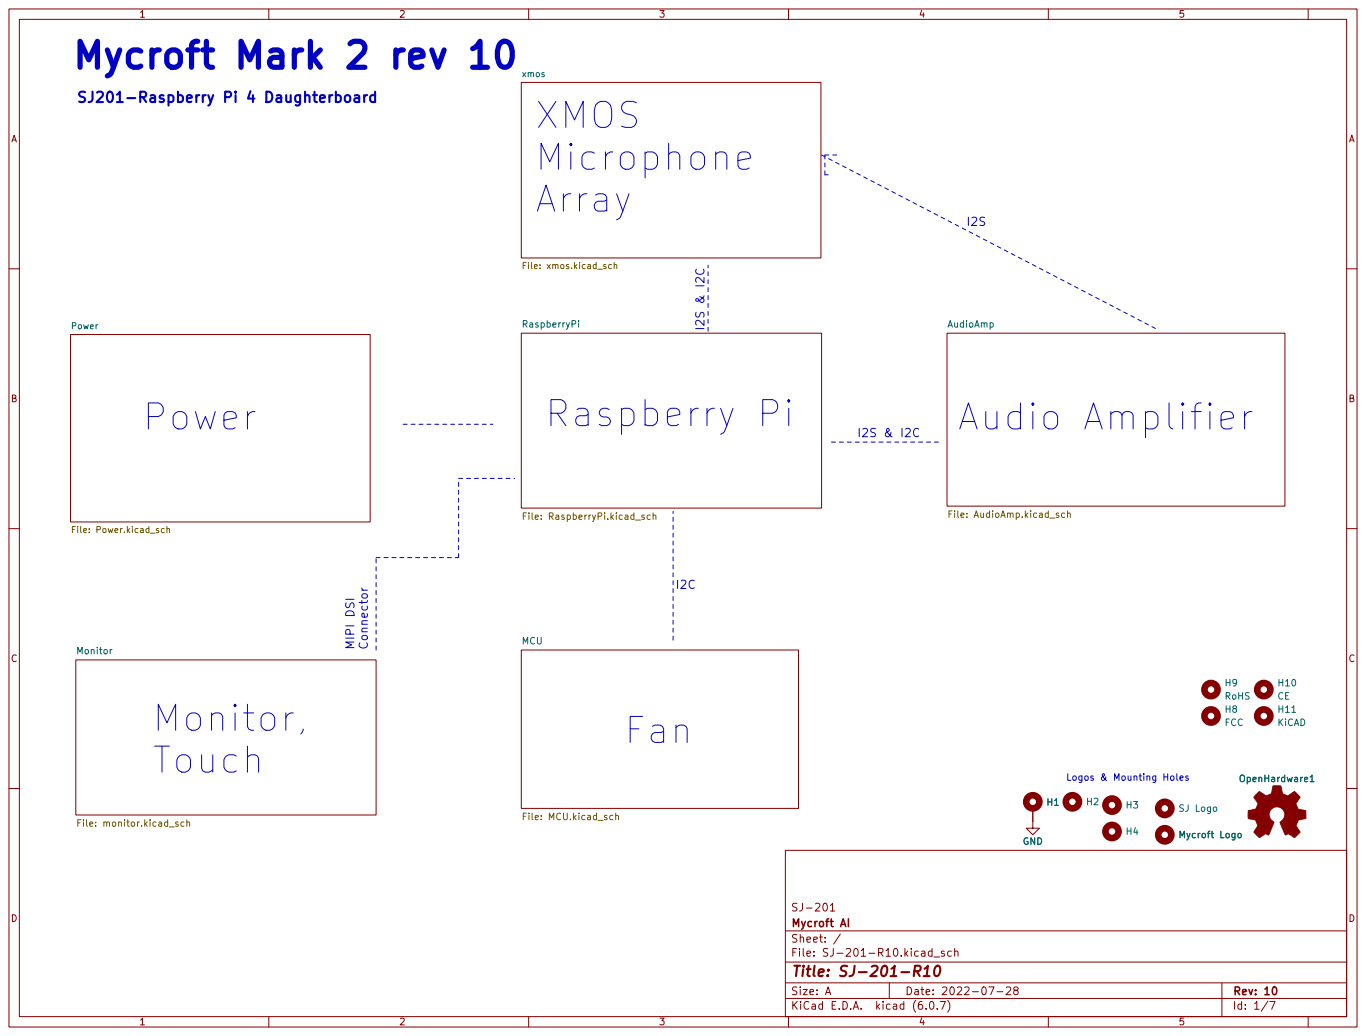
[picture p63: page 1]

File: RaspberryPi.kicad_sch Monitor File: monitor.kicad_sch

File: SJ-201-R10.kicad_sch Sheet: / Mycroft AI SJ-201 MCU
Fan

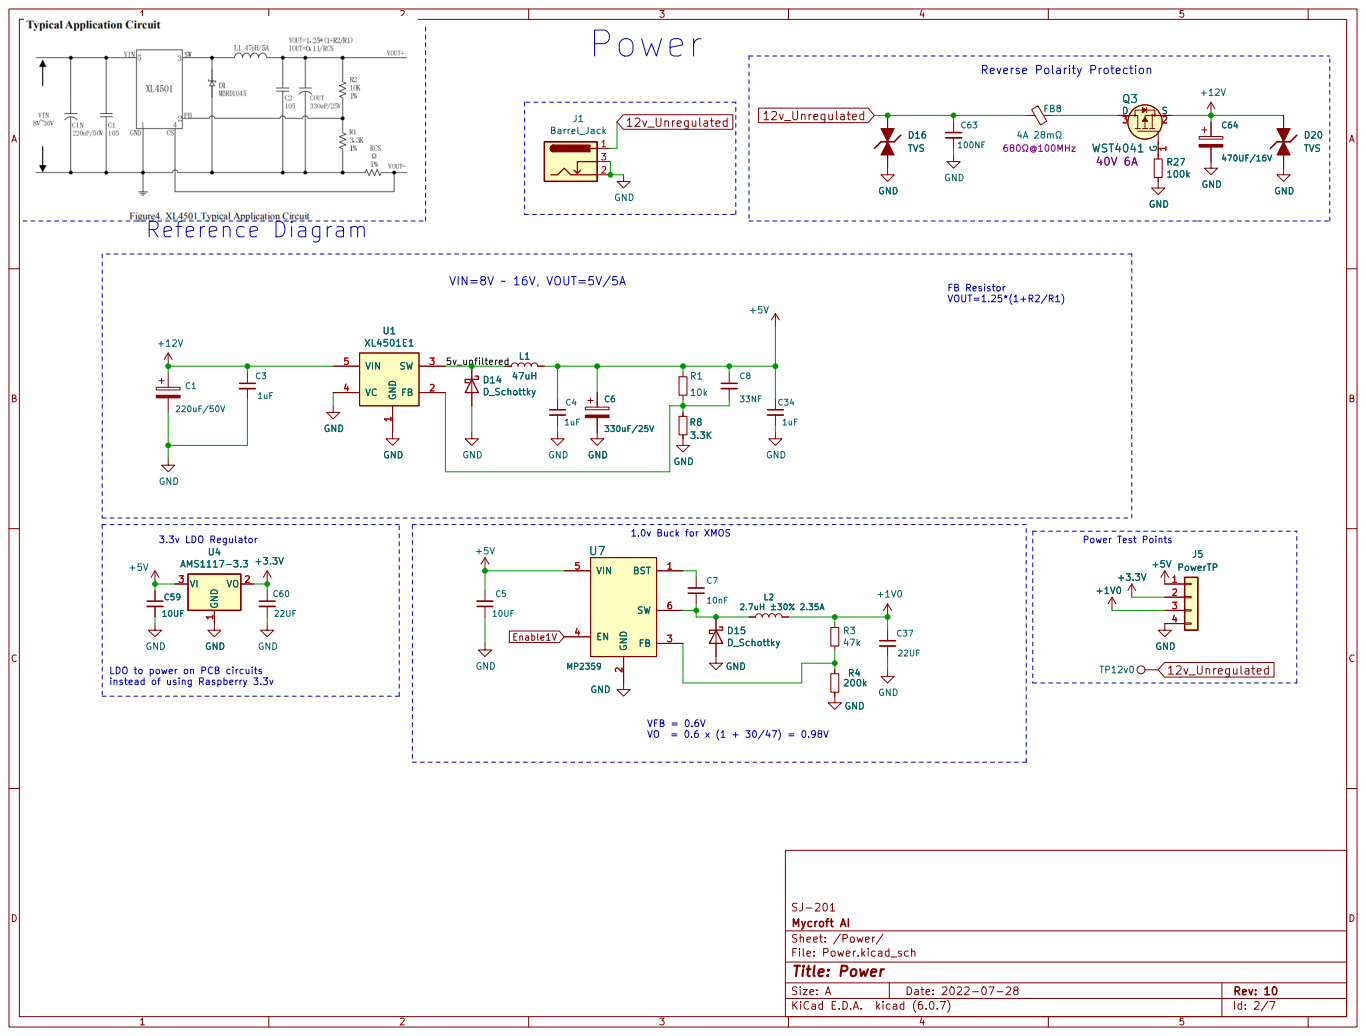
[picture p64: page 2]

1 FB 2 SW 3 VC 4 VIN 5 U1 XL4501E1 R3

1 FB 2 SW 3 VC 4 VIN 5 GND GND

1 VO 2 VI 3 GND GND U7 MP2359 BST 1 GND

LDO to power on PCB circuits

File: Power.kicad_sch Sheet: /Power/ Mycroft AI SJ-201

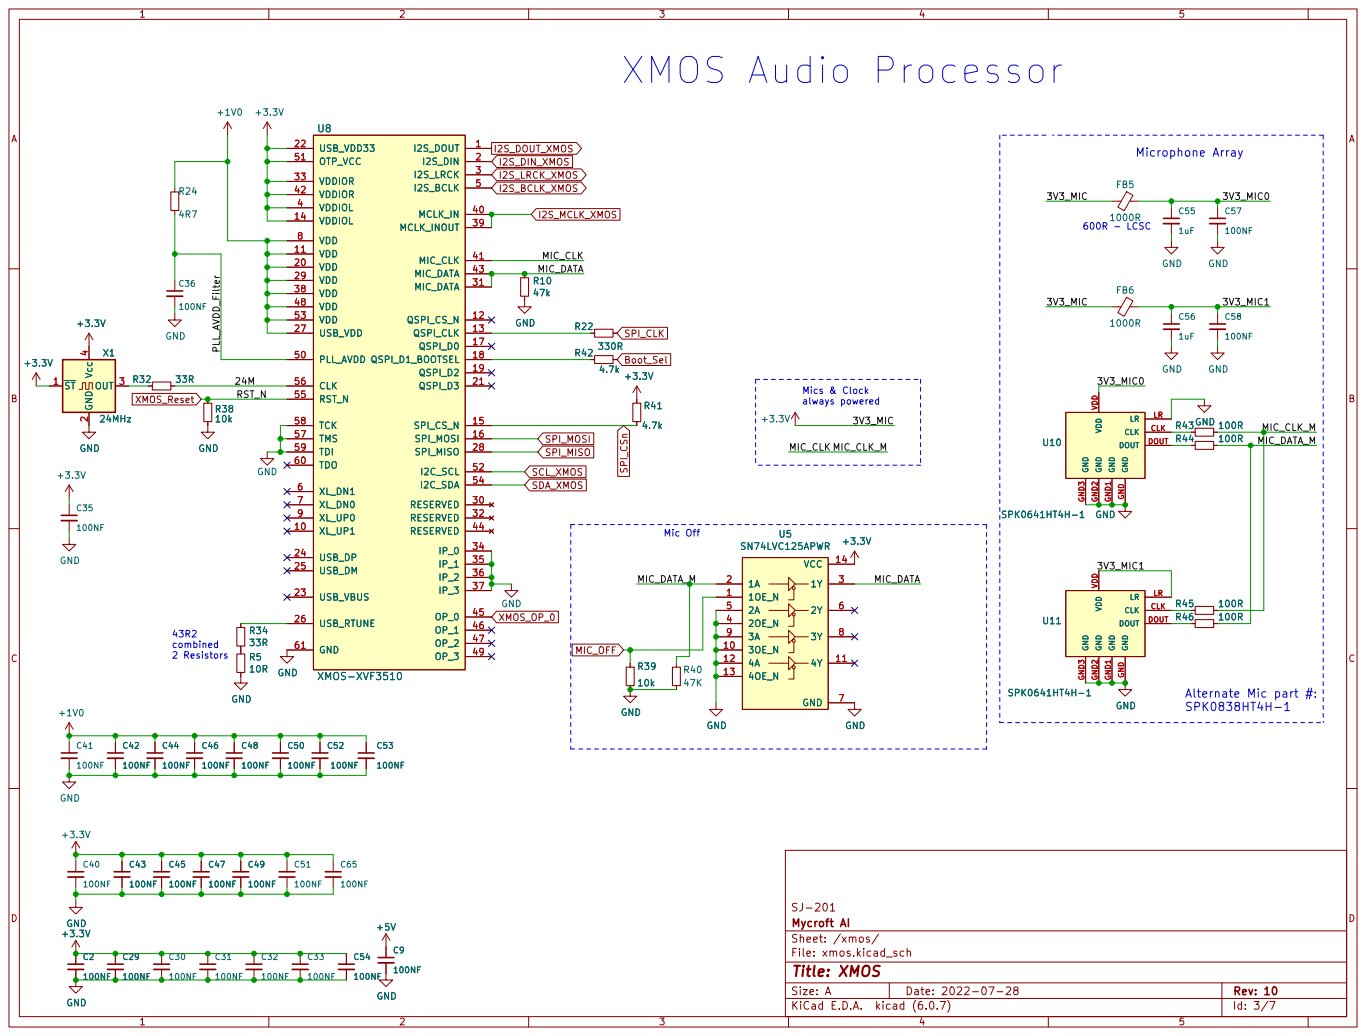
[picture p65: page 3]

600R - LCSC DO NOT PLACE

File: xmos.kicad_sch Sheet: /xmos/ Mycroft AI SJ-201

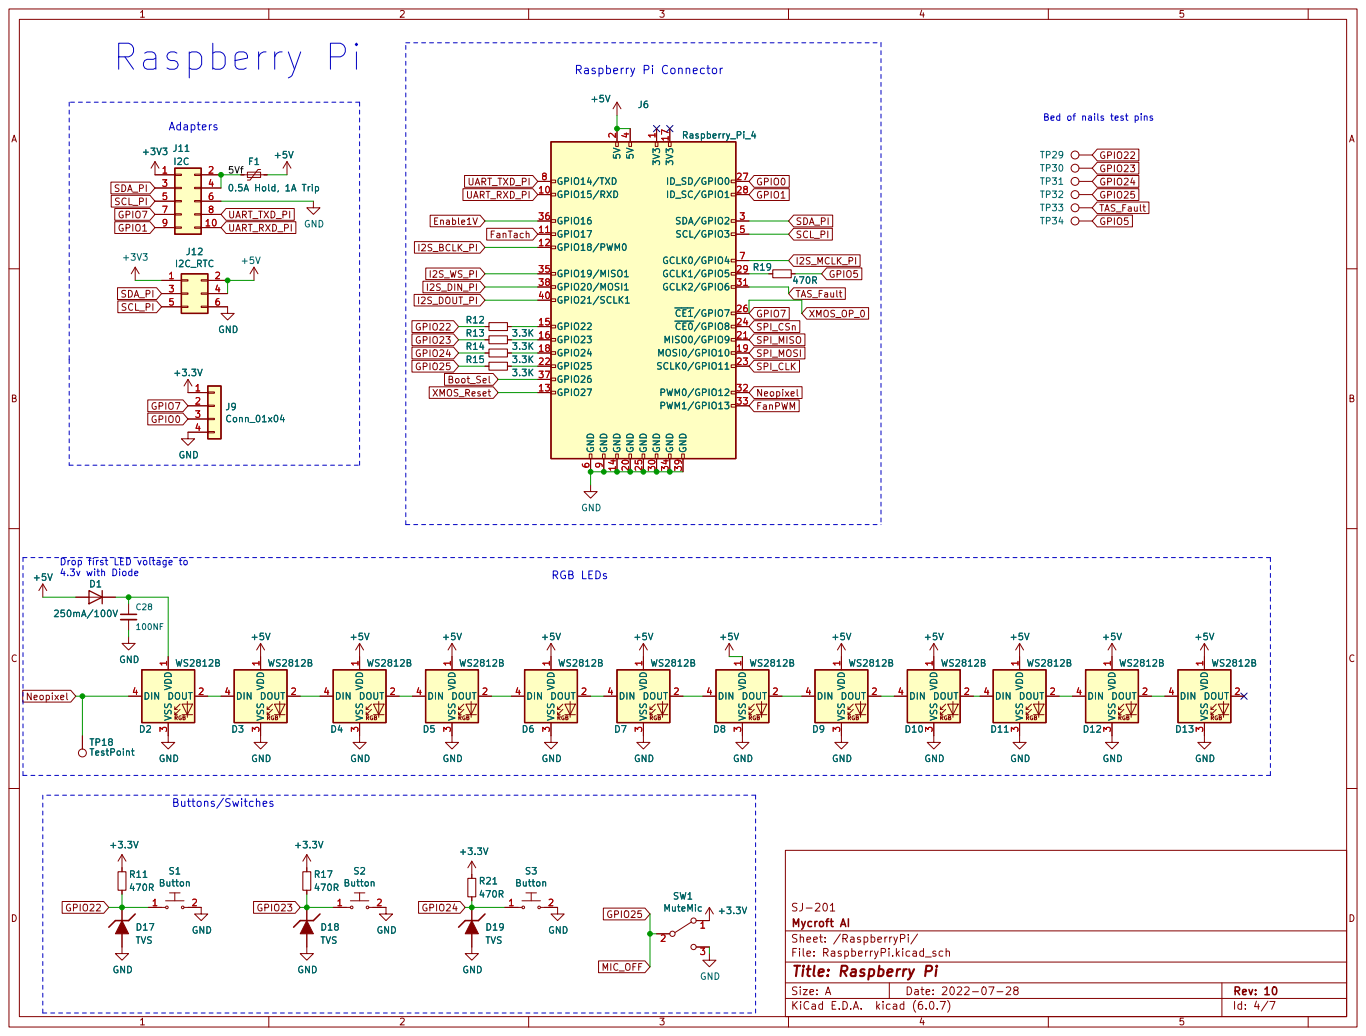
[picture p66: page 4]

Bed of nails test pins

Drop first LED voltage to 4.3v with Diode NeoPixels must be connected to GPIO10, GPIO12, GPIO18 or GPIO21 to work! GPIO18 is the standard pin. GPIO #18 - I2S Clock GPIO #19 - I2S LR Clock (also sometimes called WS Clock)

Mycroft AI SJ-201 GND

Sheet: /RaspberryPi/
File: RaspberryPi.kicad_sch
Id: 4/7 Title: Raspberry Pi

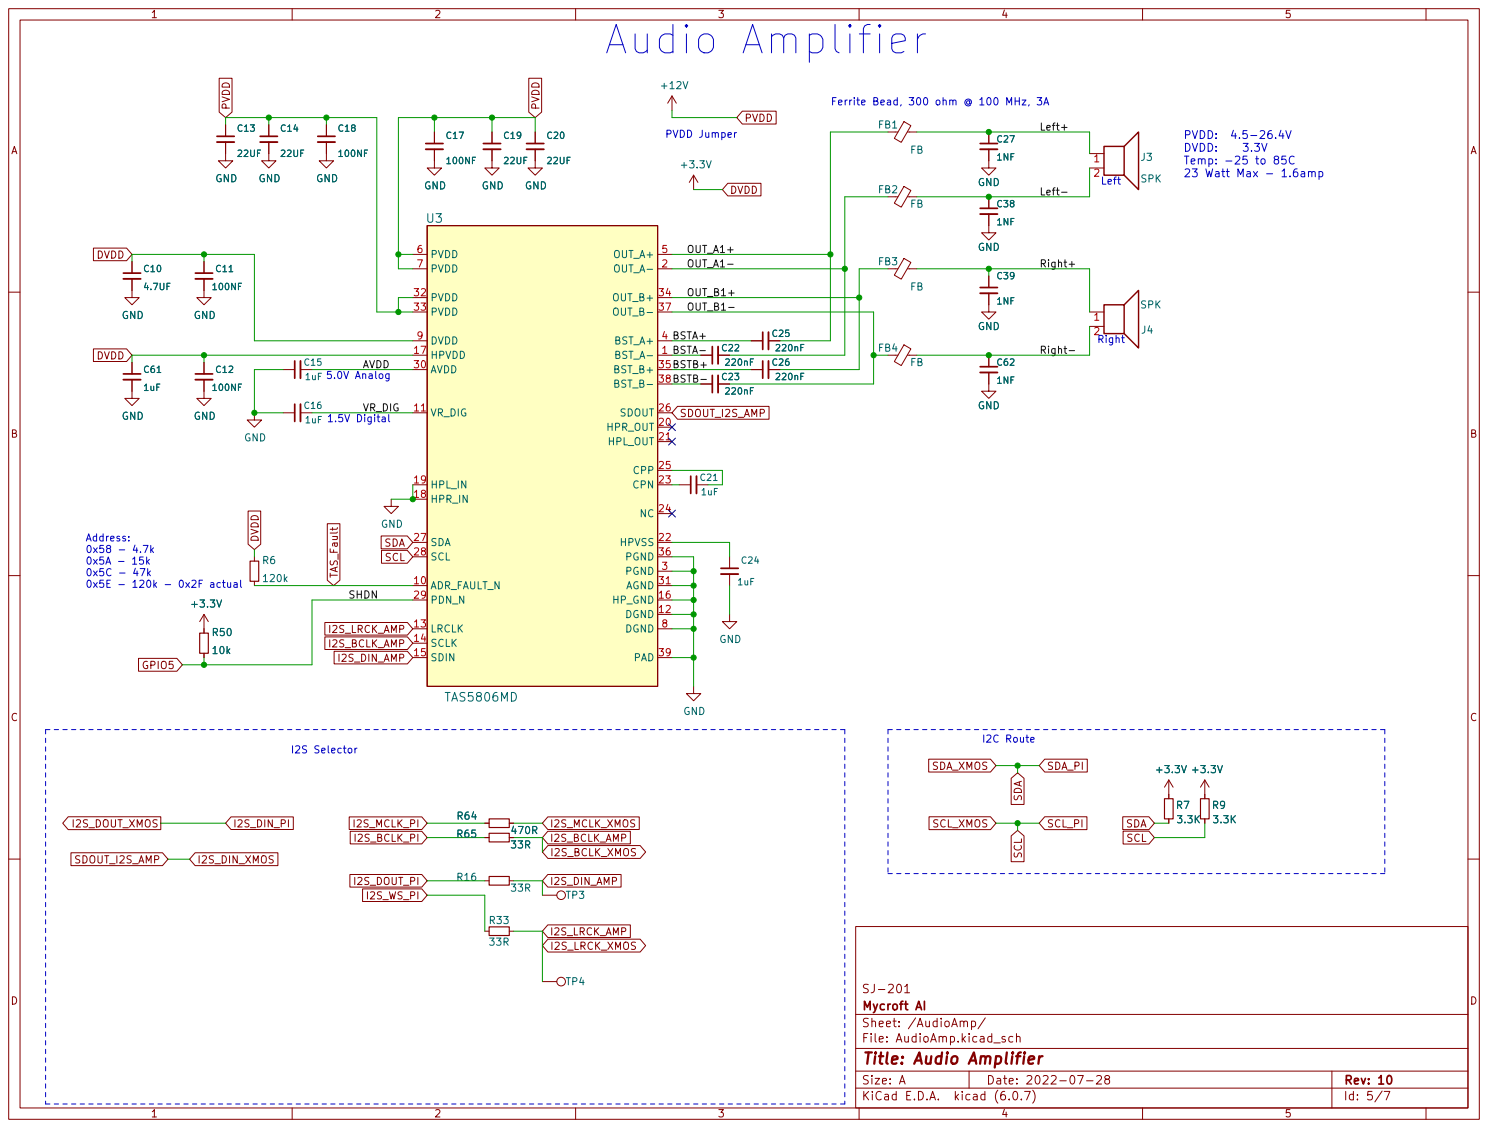
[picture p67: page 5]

Ferrite Bead, 300 ohm @ 100 MHz, 3A

Mycroft AI SJ-201
Sheet: /AudioAmp/
File: AudioAmp.kicad_sch
Id: 5/7 Title: Audio Amplifier

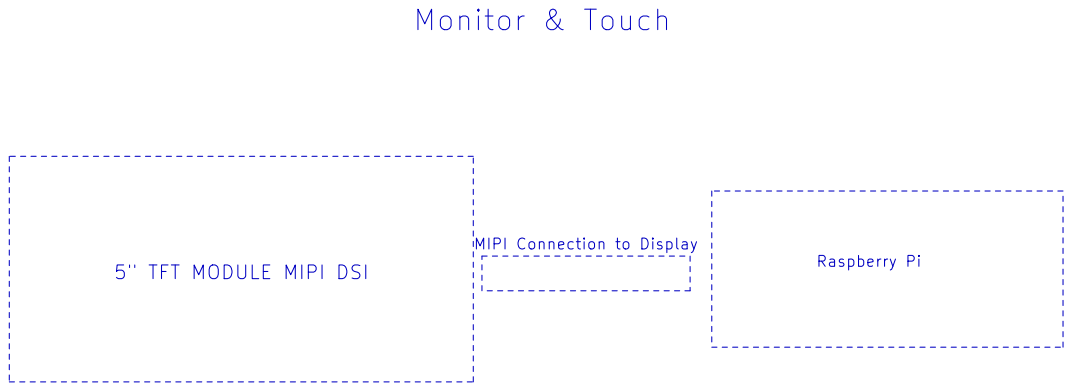
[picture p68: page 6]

MIPI Connection to Display

File: monitor.kicad_sch Sheet: /Monitor/ Mycroft AI SJ-201

Id: 6/7 Title: Monitor & Touchscreen

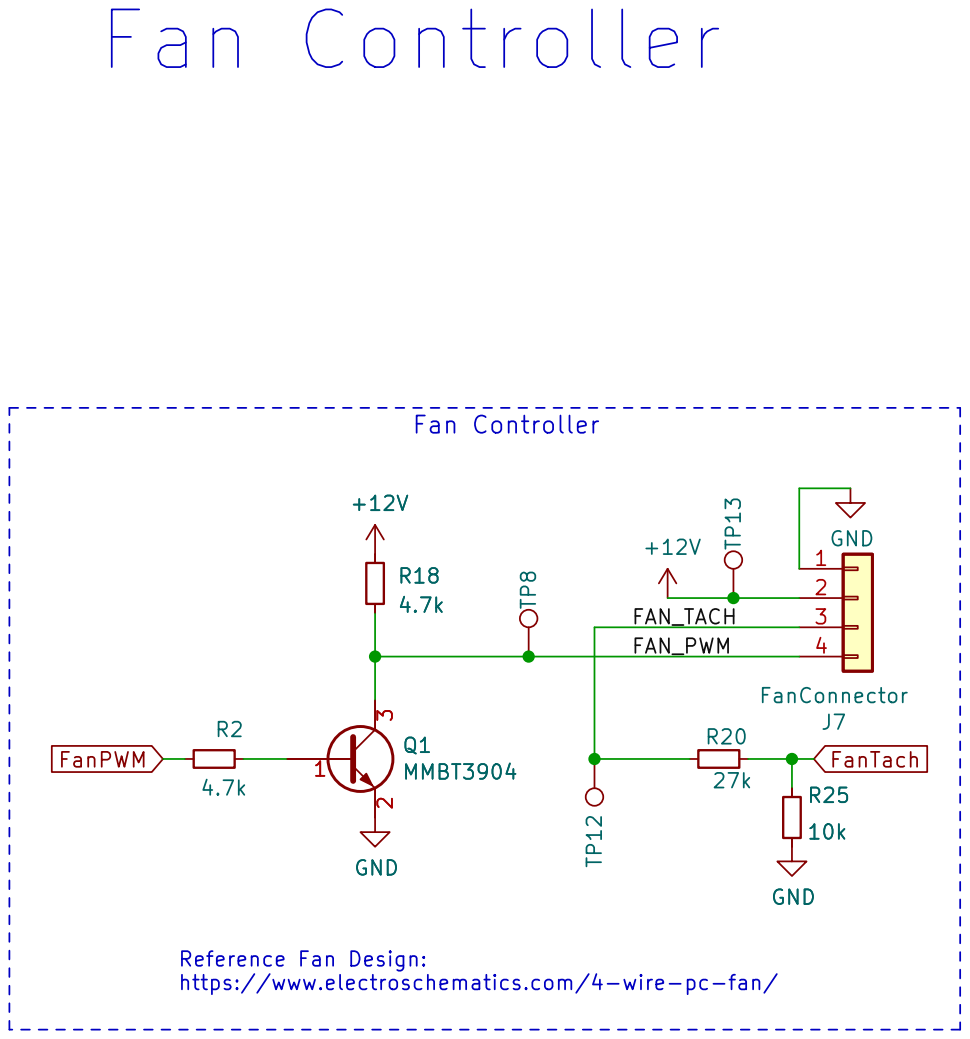
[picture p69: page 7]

Fan Controller
File: MCU.kicad_sch Sheet: /MCU/ Mycroft AI SJ-201 GND GND

http://cdn.sparkfun.com/datasheets/BreakoutBoards/Logic_Level_Bidirectional.pdf Fan Controller Reference Fan Design:

https://www.electroschematics.com/4-wire-pc-fan/

Id: 7/7 Title: MCU & Fan

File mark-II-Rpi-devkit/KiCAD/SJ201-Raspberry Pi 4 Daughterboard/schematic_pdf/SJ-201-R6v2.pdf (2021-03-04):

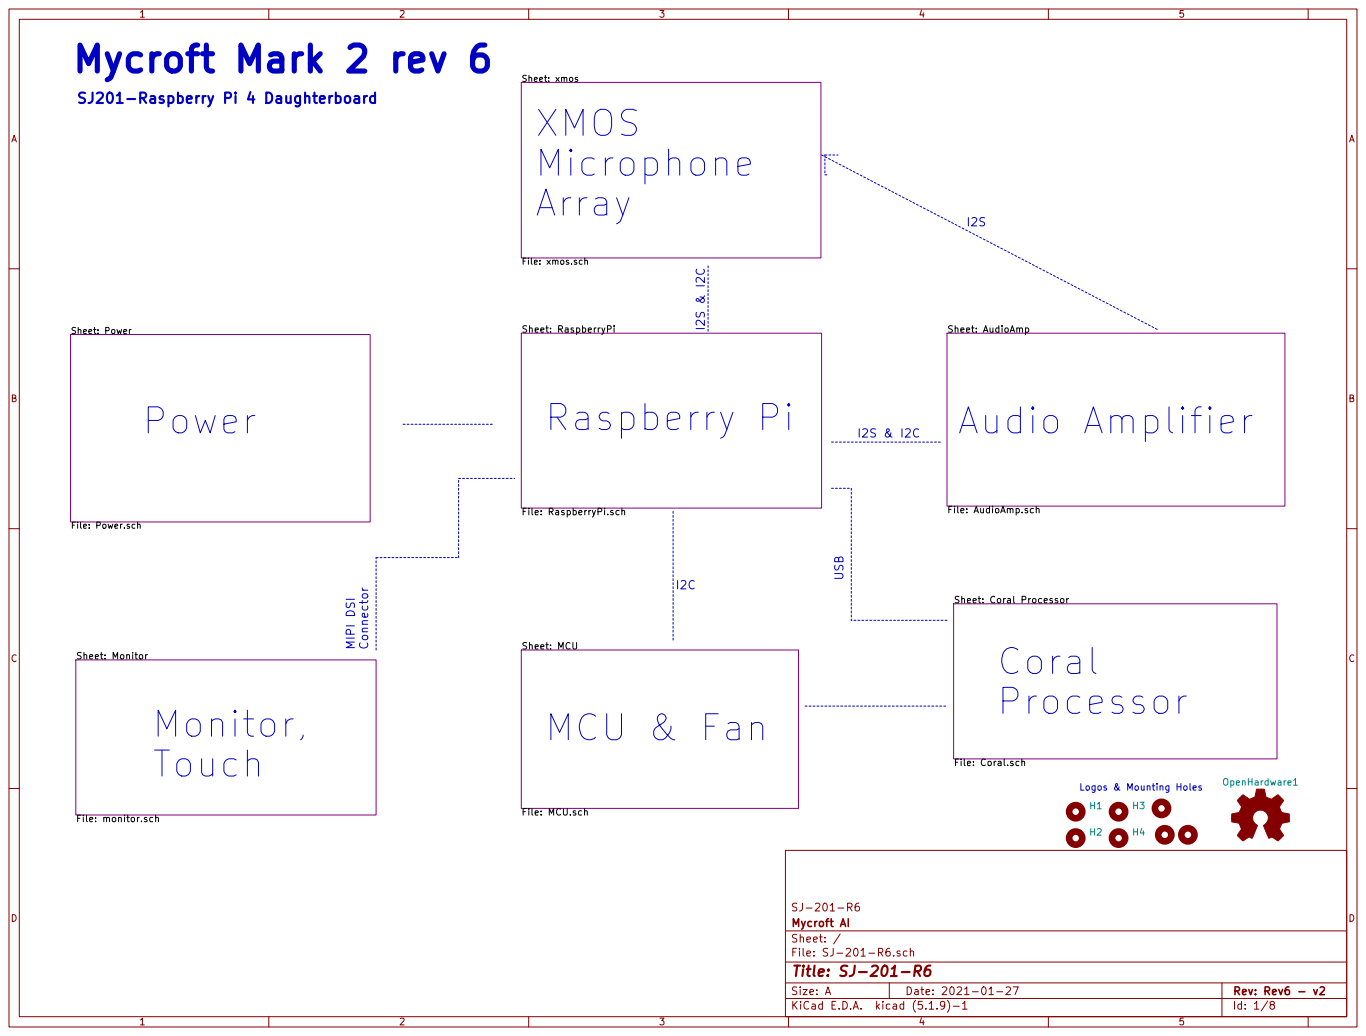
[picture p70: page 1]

File: AudioAmp.sch Sheet: Monitor File: monitor.sch

File: SJ-201-R6.sch Sheet: / Mycroft AI SJ-201-R6 Sheet: MCU
MCU & Fan

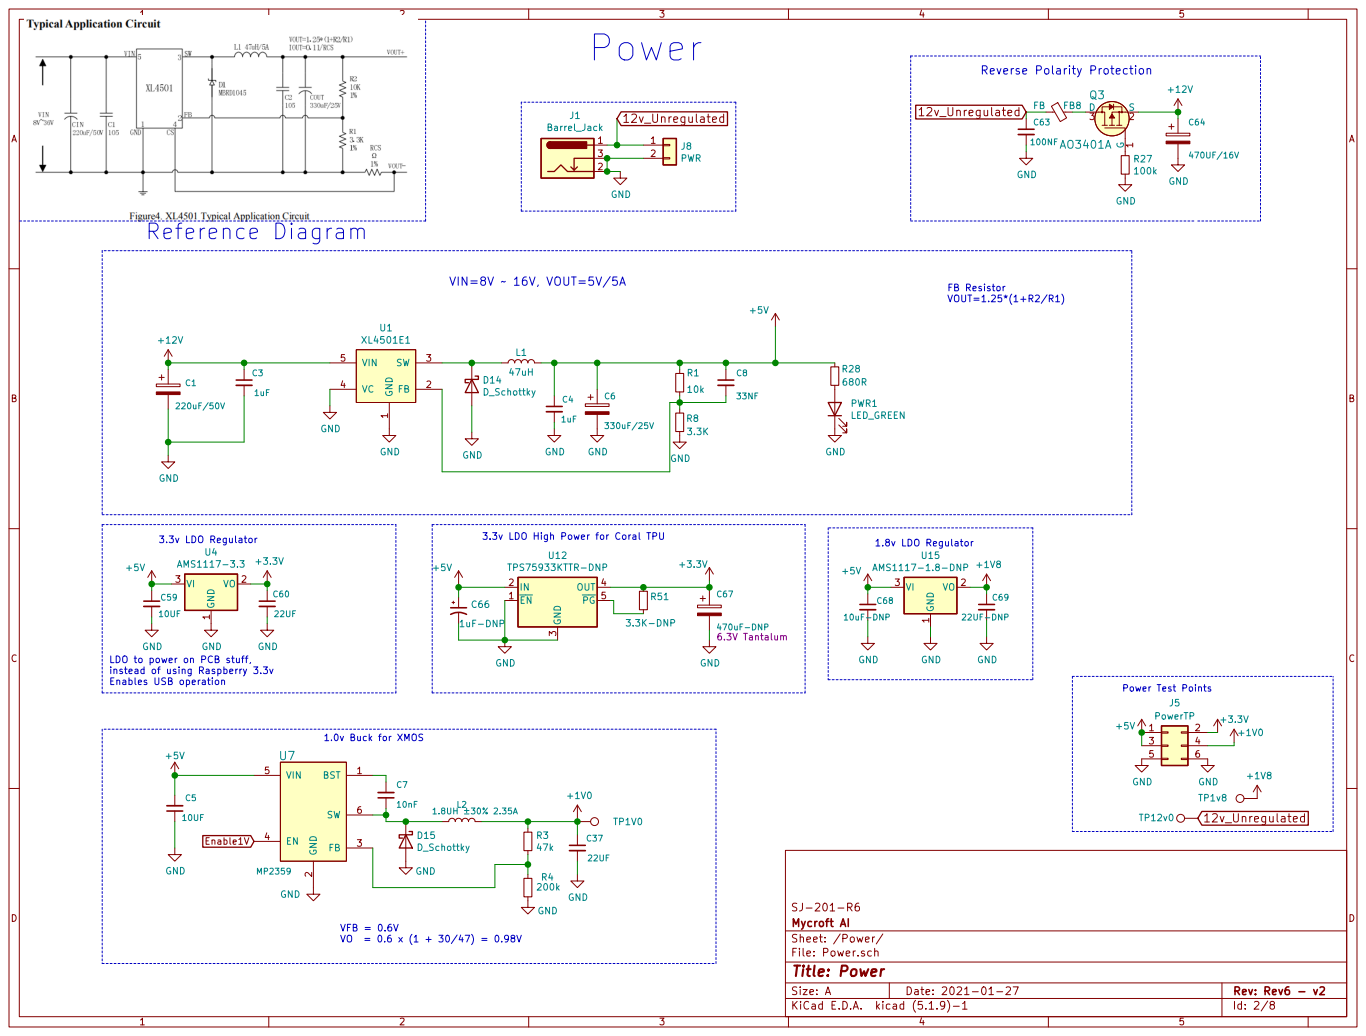
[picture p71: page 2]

1 FB 2 SW 3 VC 4 VIN 5 U1 XL4501E1 GND

Power Test Points 3.3v LDO Regulator

3.3v LDO High Power for Coral TPU

LDO to power on PCB stuff,
instead of using Raspberry 3.3v

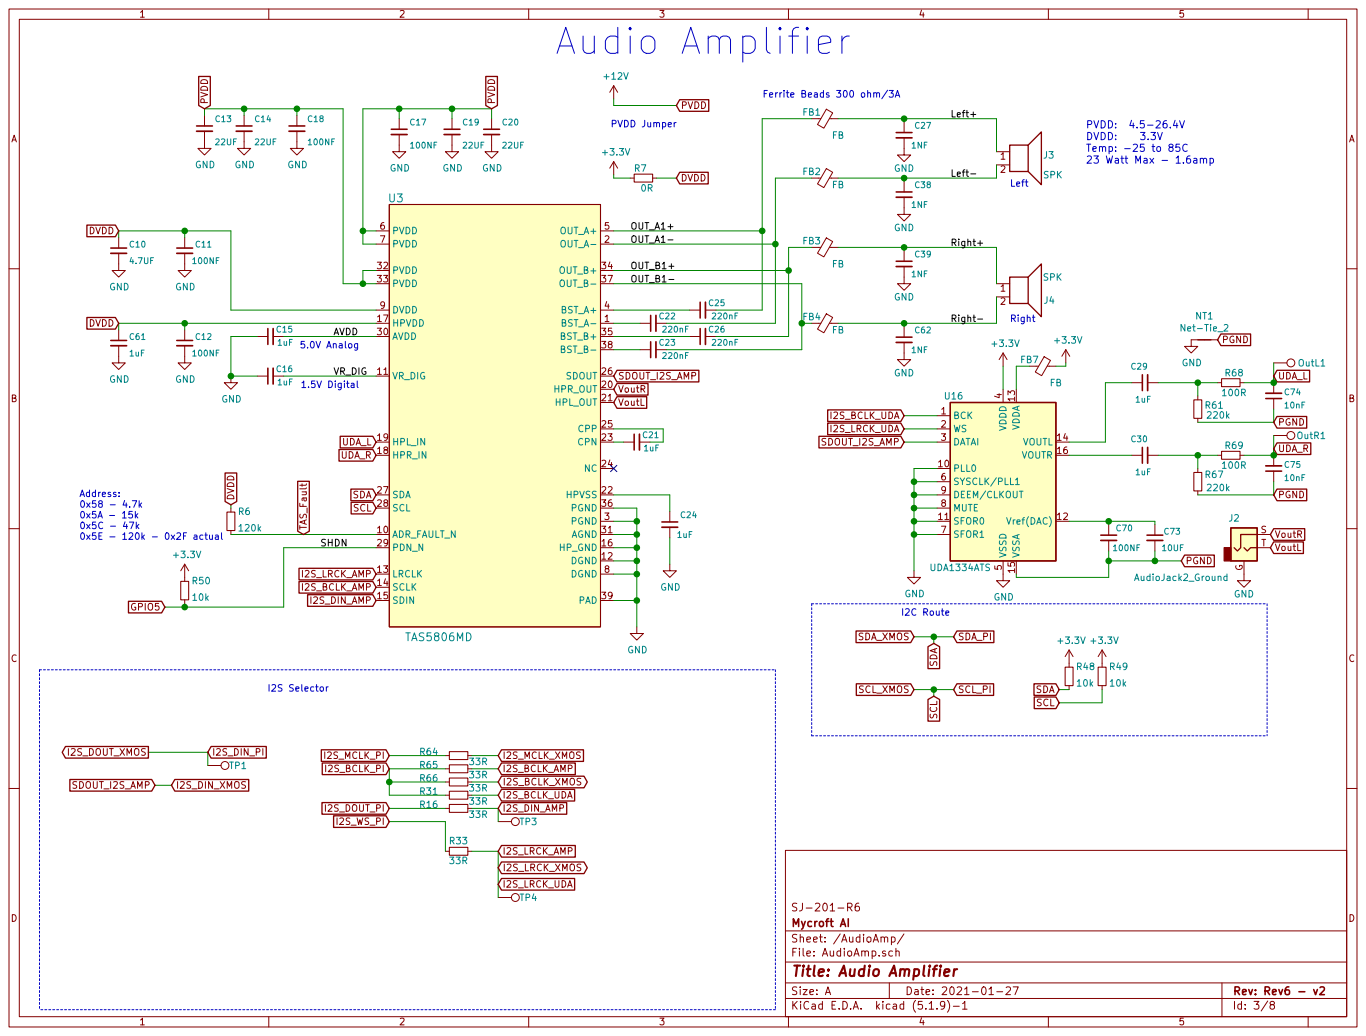
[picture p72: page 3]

5 SYSCLK/PLL1 6 SFOR1 7 MUTE 8 DEEM/CLKOUT 9U16 UDA1334ATS GND

Sheet: /AudioAmp/
File: AudioAmp.sch
Id: 3/8 Title: Audio Amplifier


File: monitor.sch Sheet: /Monitor/ Mycroft AI SJ-201-R6 Monitor & Touch

MIPI Connection to Display

5" TFT MODULE MIPI DSI

Id: 4/8 Title: Monitor & Touchscreen


Sheet: /RaspberryPi/
File: RaspberryPi.sch
Id: 5/8 Title: Raspberry Pi


DNP DNP DO NOT PLACE

4 MOSI 5 SCK 6 HOLD 7 VCC

2A 5 | 3V3_MIC MIC_CLK_M
2OE_N 4


File: Coral.sch Sheet: /Coral Processor/ Mycroft AI SJ-201-R6

Id: 7/8 Title: Coral TPU


File: MCU.sch Sheet: /MCU/ Mycroft AI SJ-201-R6

Reference Fan Design:
https://www.electroschematics.com/4-wire-pc-fan/

Id: 8/8 Title: MCU & Fan

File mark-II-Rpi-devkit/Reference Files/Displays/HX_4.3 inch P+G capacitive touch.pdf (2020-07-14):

Front | Side | Back

Total thickness; components area; Black; assignment

Spec:
2. Voltage: 2.8V-3.3V
3. Transparency: ≧80%
4. Surface hardness: 2H
5. Working temperature: -10°C +60°C ≦90% RH
6. Storage temperature: -20°C +70°C ≦90% RH
7. Unmarked tolerance: ±0.2mm
8. RoHS compliant.

Hong Xian Display Technology Limited

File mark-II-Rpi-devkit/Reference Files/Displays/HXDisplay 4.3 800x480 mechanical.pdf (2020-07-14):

4. Outline Drawing; 易拉纸; 单层区; 元件区 元件区; VERSION:V1; Page 4

Shenzhen Hong Xian wei ye Technology Co.,Ltd

司 Hong Xian Display Technology Limited

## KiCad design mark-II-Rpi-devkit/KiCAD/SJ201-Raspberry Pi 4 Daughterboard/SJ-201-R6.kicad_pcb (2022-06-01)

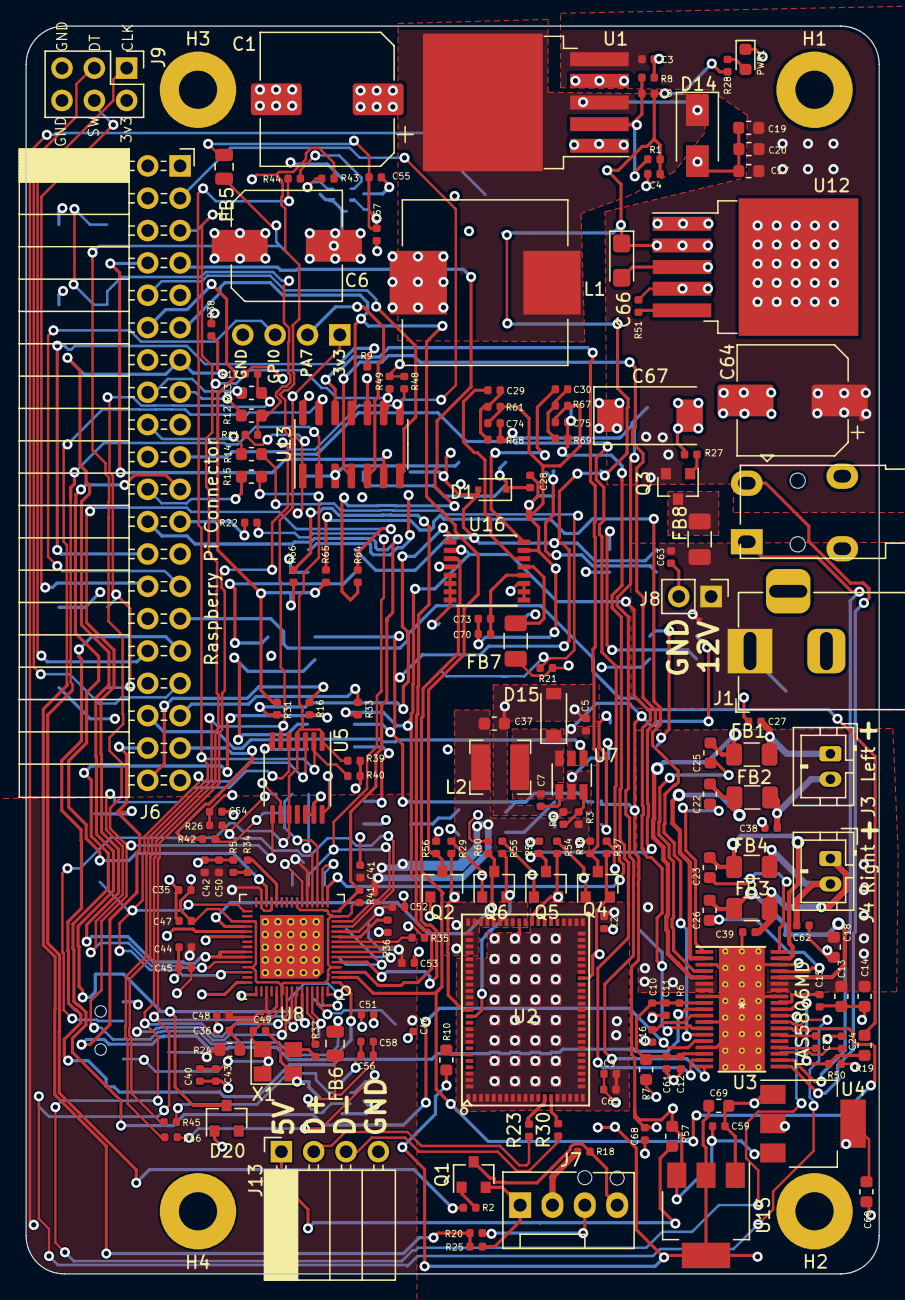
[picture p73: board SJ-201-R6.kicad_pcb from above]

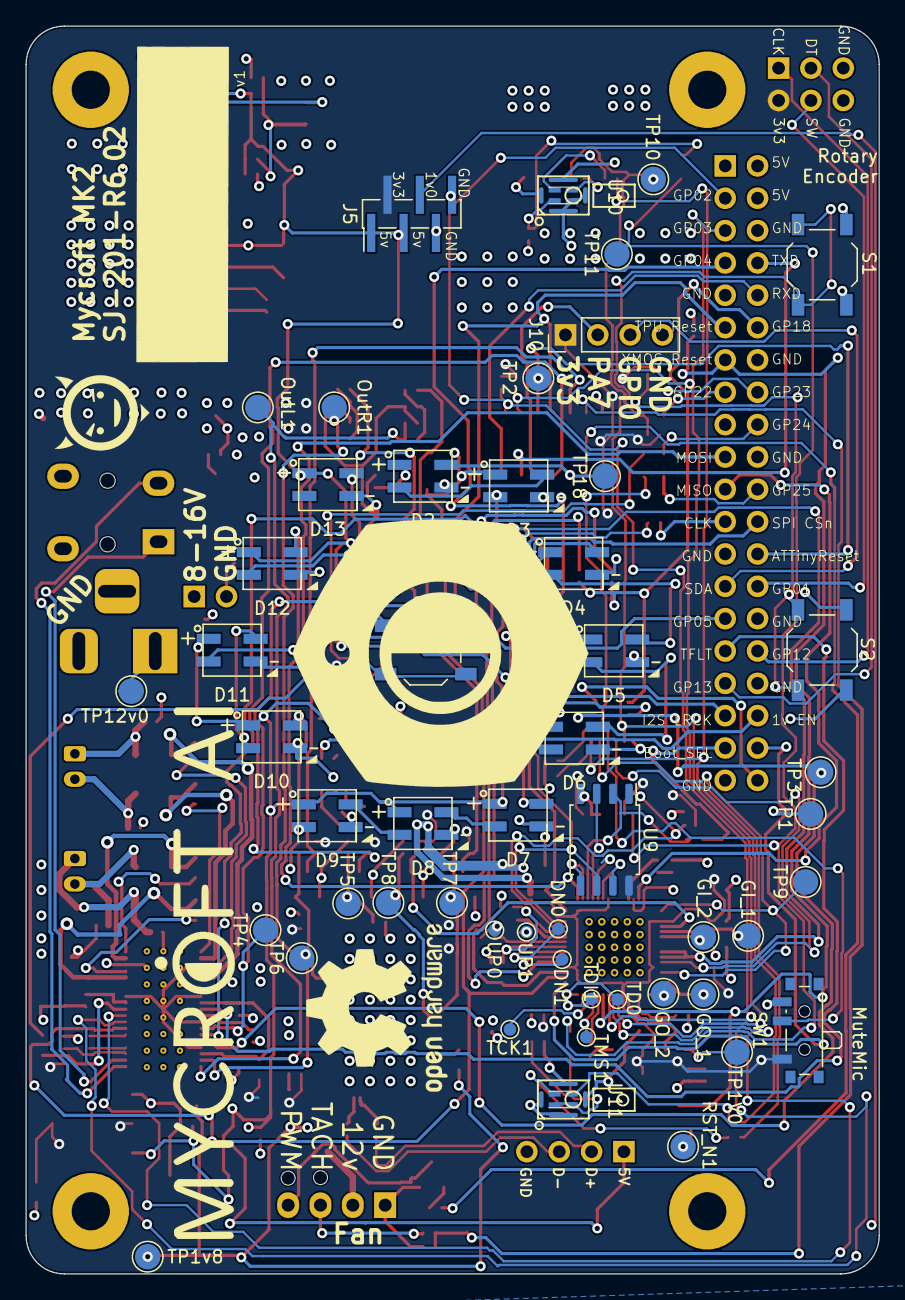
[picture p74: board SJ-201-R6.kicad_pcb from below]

Board: 4 copper layers, 67.0 x 98.0 mm, 235 parts (55 on the bottom side), 155 nets.

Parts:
C1: 220uF/50V; CP_Elec_10x10
C2, C9: 100NF-DNP; C_0402_1005Metric
C3, C4, C15, C16, C21, C24, C29, C30, C55, C56, C61: 1uF; C_0402_1005Metric
C5, C59, C73: 10UF; C_0402_1005Metric
C6: 330uF/25V; CP_Elec_8x10.5
C7, C74, C75: 10nF; C_0402_1005Metric
C8: 33NF; C_0402_1005Metric
C10: 4.7UF; C_0402_1005Metric
C11, C12, C28, C35, C36, C40, C41, C42, C43, C44, C45, C46, C47, C48, C49, C50, C51, C52, C53, C54, C57, C58, C63, C70: 100NF; C_0402_1005Metric
C13, C14, C19, C20, C37, C60: 22UF; C_0603_1608Metric
C17, C18: 100NF; C_0603_1608Metric
C22, C23, C25, C26: 220nF; C_0603_1608Metric
C27, C38, C39, C62: 1NF; C_0402_1005Metric
C64: 470UF/16V; CP_Elec_8x10.5
C65: 10UF-DNP; C_0402_1005Metric
C66: 1uF-DNP; CP_EIA-3216-10_Kemet-I
C67: 470uF-DNP; CP_EIA-7343-15_Kemet-W
C68: 10uF-DNP; C_0402_1005Metric
C69: 22UF-DNP; C_0603_1608Metric
D1: 250mA/100V; D_SOD-323F
D2, D3, D4, D5, D6, D7, D8, D9, D10, D11, D12, D13: WS2812B; LED_WS2812_Mini_3.5x3.5mm_P1.1mm
D14: D_Schottky; D_SMA
D15: D_Schottky; D_SOD-123
D20: BAT54A; SOT-23
DN0, DN1: TestPoint; TestPoint_Pad_D1.0mm
FB1, FB2, FB3, FB4, FB7, FB8: FB; R_1206_3216Metric
FB5, FB6: 1000R; R_0805_2012Metric
GI_1, GI_2: TestPoint; TestPoint_Pad_D2.0mm
GO_1, GO_2: TestPoint; TestPoint_Pad_D2.0mm
H1, H2, H3, H4: MountingHole; MountingHole_3mm_Pad
H5: MountingHole; mycroft_logo_graphic
H6: MountingHole; simon-jester-logo
H7: MountingHole; mycroft_logo_words
J1: Barrel_Jack; BarrelJack_Horizontal
J2: AudioJack2_Ground; Jack_3.5mm_PJ-3210
J3, J4: SPK; JST_PH_B2B-PH-K_1x02_P2.00mm_Vertical
J5: PowerTP; PinHeader_1x06_P1.27mm_Vertical_SMD_Pin1Left
J6: Raspberry_Pi_4; PinSocket_2x20_P2.54mm_Horizontal
J7: FanConnector; FanPinHeader_1x04_P2.54mm_Vertical
J8: PWR; PinHeader_1x02_P2.54mm_Vertical
J9: RotaryEncoder; PinHeader_2x03_P2.54mm_Vertical
J10: Conn_01x04; PinHeader_1x04_P2.54mm_Vertical
J13: USB-PinHeader; PinSocket_1x04_P2.54mm_Horizontal
L1: 47uH; L_Wuerth_HCI-1365
L2: 1.8UH ±30% 2.35A; L_Bourns-SRN4018
NT1: Net-Tie_2; NetTie-2_SMD_Pad0.5mm
OpenHardware1: Logo_Open_Hardware_Small; OSHW-Logo2_14.6x12mm_SilkScreen
OutL1: TestPoint; TestPoint_Pad_D2.0mm
OutR1: TestPoint; TestPoint_Pad_D2.0mm
PWR1: LED_GREEN; LED_0603_1608Metric
Q1: MMBT3904; SOT-23
Q2, Q4, Q5, Q6: BSS138-DNP; SOT-23
Q3: AO3401A; SOT-23
R1, R11, R17, R21, R25, R38, R39, R48, R49, R50: 10k; R_0402_1005Metric
R2, R9, R18, R41, R42: 4.7k; R_0402_1005Metric
R3: 47k; R_0402_1005Metric
R4: 200k; R_0402_1005Metric
R5: 10R; R_0402_1005Metric
R6: 120k; R_0402_1005Metric
R7: 0R; R_0603_1608Metric
R8: 3.3K; R_0402_1005Metric
R10: 0R-DNP; R_0603_1608Metric
R12, R13, R14, R15, R19: 470R; R_0603_1608Metric
R16, R31, R32, R33, R34, R35, R36, R64, R65, R66: 33R; R_0402_1005Metric
R20: 27k; R_0402_1005Metric
R22: 330R; R_0402_1005Metric
R23, R30: 33R-DNP; R_0402_1005Metric
R24: 4R7; R_0603_1608Metric
R26, R40: 47K; R_0402_1005Metric
R27: 100k; R_0402_1005Metric
R28: 680R; R_0402_1005Metric
R29, R37, R54, R55, R56, R58, R59, R60: 10k-DNP; R_0402_1005Metric
R43, R44, R45, R46, R68, R69: 100R; R_0402_1005Metric
R51: 3.3K-DNP; R_0402_1005Metric
R57: 0R - DNP; R_0603_1608Metric
R61, R67: 220k; R_0402_1005Metric
RST_N1: TestPoint; TestPoint_Pad_D2.0mm
S1, S2, S3: Button; SW_SPST_TL3342
SW1: MuteMic; SW_SPDT_PCM12
TCK1: TestPoint; TestPoint_Pad_D1.0mm
TD0: TestPoint; TestPoint_Pad_D1.0mm
TDI1: TestPoint; TestPoint_Pad_D1.0mm
TMS1: TestPoint; TestPoint_Pad_D1.0mm
TP1, TP1V0, TP1v8, TP3, TP4, TP5, TP6, TP7, TP8, TP9, TP10, TP11, TP12v0, TP18: TestPoint; TestPoint_Pad_D2.0mm
TP2: ATTinyProg; TestPoint_Pad_D2.0mm
U1: XL4501E1; TO-263-5_TabPin3
U2: CoralTPU-DNP; CoralTPU
U3: TAS5806MD; TAS5806MDDCPR
U4: AMS1117-3.3; SOT-223-3_TabPin2
U5: SN74LVC125APWR; TSSOP-14_4.4x5mm_P0.65mm
U7: MP2359; TSOT-23-6
U8: XMOS-XVF3510; QFN-60-1EP_7x7mm_P0.4mm_EP5.6x5.6mm
U9: DNP - AT25SFxx 16mb or greater; SOIC-8_5.23x5.23mm_P1.27mm
U10, U11: SPK0641HT4H-1; HCLGA-MP34DT05
U12: TPS75933KTTR-DNP; TO-263-5_TabPin3
U13: ATtiny1614-SS; SOIC-14_3.9x8.7mm_P1.27mm
U15: AMS1117-1.8-DNP; SOT-223-3_TabPin2
U16: UDA1334ATS; SSOP-16_4.4x5.2mm_P0.65mm
UP0, UP1: TestPoint; TestPoint_Pad_D1.0mm
X1: SG-210STF 24M; Oscillator_SMD_SeikoEpson_SG8002CE-4Pin_3.2x2.5mm

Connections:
12v_Unregulated: C63.1, FB8.1, J1.1, J8.1, TP12v0.1
+1V0: C37.1, C41.1, C42.1, C44.1, C46.1, C48.1, C50.1, C52.1, C53.1, J5.4, L2.2, R3.1, R24.2, TP1V0.1, U8.8, U8.11, U8.20, U8.27, U8.29, U8.38, U8.48, U8.53
+1V8: C69.1, Q2.1, Q4.1, Q5.1, Q6.1, R10.1, R29.1, R37.1, R54.1, R55.1, TP1v8.1, U15.2
+3V3: C2.1, C9.1, C35.1, C40.1, C43.1, C45.1, C47.1, C49.1, C51.1, C54.1, C60.1, C65.1, C67.1, FB7.1, J5.2, J9.2, J10.1, R7.2, R11.1, R17.1, R21.1, R26.2, R41.2, R48.1, R49.1, R50.1, R51.2, R56.1, R58.1, R59.1, R60.1, SW1.1, U2.54, U2.56, U2.57, U2.58, U2.59, U2.60, U2.61, U2.62, U2.63, U2.64, U2.65, U2.66, U2.67, U4.2, U5.9, U5.14, U8.4, U8.14, U8.22, U8.33, U8.42, U8.51, U9.8, U12.4, U13.1, U16.4, X1.1, X1.4
+5V: C4.1, C5.2, C6.1, C8.1, C59.1, C66.1, C68.1, D1.2, D3.1, D4.1, D5.1, D6.1, D7.1, D8.1, D9.1, D10.1, D11.1, D12.1, D13.1, J5.1, J5.3, J6.2, J6.4, L1.2, R1.1, R28.2, R57.1, U4.3, U7.5, U12.2, U15.3
/AudioAmp/AVDD: C15.2, U3.30
/AudioAmp/Left+: C27.1, FB1.1, J3.1
/AudioAmp/Left-: C38.1, FB2.1, J3.2
/AudioAmp/OUT_A1+: C25.2, FB1.2, U3.5
/AudioAmp/OUT_A1-: C22.2, FB2.2, U3.2
/AudioAmp/OUT_B1+: C26.2, FB3.2, U3.34
/AudioAmp/OUT_B1-: C23.2, FB4.2, U3.37
/AudioAmp/Right+: C39.1, FB3.1, J4.1
/AudioAmp/Right-: C62.1, FB4.1, J4.2
/AudioAmp/VR_DIG: C16.2, U3.11
/Coral Processor/D+: R23.2, U2.13
/Coral Processor/D-: R30.2, U2.14
/MCU/FAN_PWM: J7.4, Q1.3, R18.2
/xmos/3V3_MIC: FB5.2, FB6.2, TP11.1, U5.8
/xmos/3V3_MIC0: C55.1, C57.1, FB5.1, U10.VDD
/xmos/3V3_MIC1: C56.1, C58.1, FB6.1, U11.LR, U11.VDD
/xmos/24M: R32.1, U8.56
/xmos/MIC_CLK: U5.5, U8.41
/xmos/MIC_CLK_M: R43.1, R45.1, TP10.1, U5.6
/xmos/MIC_DATA: TP9.1, U5.3, U8.31, U8.43
/xmos/MIC_DATA_M: R40.2, R44.1, R46.1, U5.2
/xmos/QSPI_CLK: R22.1, U8.13, U9.6
/xmos/QSPI_CS_N: R26.1, U8.12, U9.1
/xmos/QSPI_D0: U8.17, U9.5
/xmos/QSPI_D1: R42.1, U8.18, U9.2
/xmos/QSPI_D2: U8.19, U9.3
/xmos/QSPI_D3: U8.21, U9.7
/xmos/TCK: TCK1.1, U8.58
/xmos/TDI: TDI1.1, U8.59
/xmos/TDO: TD0.1, U8.60
/xmos/TMS: TMS1.1, U8.57
/xmos/XL_DN0: DN0.1, U8.7
/xmos/XL_DN1: DN1.1, U8.6
/xmos/XL_UP0: R35.2, UP0.1
/xmos/XL_UP1: R36.2, UP1.1
ATtinyRESET: J6.26, R9.1
Boot_Sel: J6.37, R42.2
DVDD: C10.1, C11.1, C12.1, C61.1, R6.1, R7.1, U3.9, U3.17
Enable1V: J6.36, U7.4
FanPWM: R2.2, U13.2
FanTach: R20.1, R25.1, U13.13
GND: C1.2, C2.2, C3.2, C4.2, C5.1, C6.2, C9.2, C10.2, C11.2, C12.2, C13.2, C14.2, C15.1, C16.1, C17.2, C18.2, C19.2, C20.2, C24.2, C27.2, C28.2, C35.2, C36.2, C37.2, C38.2, C39.2, C40.2, C41.2, C42.2, C43.2, C44.2, C45.2, C46.2, C47.2, C48.2, C49.2, C50.2, C51.2, C52.2, C53.2, C54.2, C55.2, C56.2, C57.2, C58.2, C59.2, C60.2, C61.2, C62.2, C63.2, C64.2, C65.2, C66.2, C67.2, C68.2, C69.2, D2.3, D3.3, D4.3, D5.3, D6.3, D7.3, D8.3, D9.3, D10.3, D11.3, D12.3, D13.3, D14.2, D15.2, J1.2, J1.3, J2.G, J5.5, J5.6, J6.6, J6.9, J6.14, J6.20, J6.25, J6.30, J6.34, J6.39, J7.1, J8.2, J9.5, J9.6, J10.4, J13.4, NT1.1, PWR1.1, Q1.2, R4.1, R5.2, R8.1, R25.2, R27.2, R38.2, R39.2, R40.1, S1.2, S2.2, S3.2, SW1.3, U1.1, U1.4, U2.1, U2.2, U2.3, U2.4, U2.5, U2.6, U2.7, U2.8, U2.9, U2.10, U2.11, U2.12, U2.15, U2.16, U2.17, U2.18, U2.19, U2.20, U2.21, U2.22, U2.23, U2.24, U2.25, U2.26, U2.27, U2.28, U2.29, U2.30, U2.31, U2.32, U2.33, U2.34, U2.35, U2.36, U2.38, U2.39, U2.40, U2.41, U2.42, U2.43, U2.44, U2.45, U2.46, U2.47, U2.48, U2.51, U2.55, U2.68, U2.69, U2.70, U2.71, U2.72, U2.73, U2.74, U2.75, U2.79, U2.80, U2.81, U2.86, U2.87, U2.88, U2.89, U2.90, U2.91, U2.92, U2.93, U2.94, U2.95, U2.96, U2.97, U2.98, U2.99, U2.100, U2.101, U2.102, U2.103, U2.104, U2.105, U2.106, U2.107, U2.108, U2.109, U2.110, U2.111, U2.112, U2.113, U2.114, U2.115, U2.116, U2.117, U2.118, U2.119, U2.120, U3.3, U3.8, U3.12, U3.16, U3.31, U3.36, U3.39, U4.1, U5.7, U5.12, U5.13, U7.2, U8.61, U9.4, U10.GND, U10.GND1, U10.GND2, U10.GND3, U10.LR, U11.GND, U11.GND1, U11.GND2, U11.GND3, U12.1, U12.3, U13.14, U15.1, U16.5, U16.6, U16.7, U16.8, U16.9, U16.10, U16.11, X1.2
GPIO0: J6.27, J10.3
GPIO1: J6.28, J9.4
GPIO5: R19.1, R50.2, U3.29
GPIO12: J6.32, J9.1
GPIO13: J6.33, J9.3
GPIO22: R11.2, R12.2, S1.1
GPIO23: R13.2, R17.2, S2.1
GPIO24: R14.2, R21.2, S3.1
GPIO25: R15.2, R39.1, SW1.2, U5.1, U5.4, U5.10
GPIO_PA7: J10.2, U13.5
I2S_BCLK_AMP: R65.2, U3.14
I2S_BCLK_PI: J6.12, R31.1, R65.1, R66.1
I2S_BCLK_UDA: R31.2, U16.1
I2S_BCLK_XMOS: R66.2, U8.5
I2S_DIN_AMP: R16.2, TP3.1, U3.15
I2S_DIN_PI: J6.38, TP1.1, U8.1
I2S_DIN_XMOS: U3.26, U8.2, U16.3
I2S_DOUT_PI: J6.40, R16.1
I2S_LRCK_AMP: R33.2, TP4.1, U3.13, U8.3, U16.2
I2S_MCLK_PI: J6.7, R64.1
I2S_MCLK_XMOS: R64.2, U8.39, U8.40
I2S_WS_PI: J6.35, R33.1
Neopixel: D2.4, TP18.1, U13.3
unnamed: C7.1, D15.1, L2.1, U7.6
unnamed: C7.2, U7.1
unnamed: C8.2, R1.2, R8.2, U1.2
unnamed: C21.1, U3.23
unnamed: C21.2, U3.25
unnamed: C22.1, U3.1
unnamed: C23.1, U3.38
unnamed: C24.1, U3.22
unnamed: C25.1, U3.4
unnamed: C26.1, U3.35
unnamed: C28.1, D1.1, D2.1
unnamed: C29.1, U16.14
unnamed: C29.2, R61.2, R68.2
unnamed: C30.1, U16.16
unnamed: C30.2, R67.2, R69.2
unnamed: C36.1, R24.1, U8.50
unnamed: C70.1, C73.1, U16.12
unnamed: D2.2, D3.4
unnamed: D3.2, D4.4
unnamed: D4.2, D5.4
unnamed: D5.2, D6.4
unnamed: D6.2, D7.4
unnamed: D7.2, D8.4
unnamed: D8.2, D9.4
unnamed: D10.2, D11.4
unnamed: D9.2, D10.4
unnamed: D11.2, D12.4
unnamed: D12.2, D13.4
unnamed: D14.1, L1.1, U1.3
unnamed: D20.1, RST_N1.1
unnamed: FB7.2, U16.13
unnamed: FB8.2, Q3.3
unnamed: GI_1.1, U8.35
unnamed: GI_2.1, U8.36
unnamed: GO_1.1, U8.45
unnamed: GO_2.1, U8.46
unnamed: J6.15, R12.1
unnamed: J6.16, R13.1
unnamed: J6.18, R14.1
unnamed: J6.22, R15.1
unnamed: J6.29, R19.2
unnamed: J7.3, R20.2
unnamed: J13.1, R57.2
unnamed: PWR1.2, R28.1
unnamed: Q1.1, R2.1
unnamed: Q3.1, R27.1
unnamed: R3.2, R4.2, U7.3
unnamed: R9.2, TP2.1, U13.10
unnamed: R10.2, U2.83
unnamed: R32.2, X1.3
unnamed: R34.1, U8.26
unnamed: R5.1, R34.2
unnamed: R35.1, U8.9
unnamed: R36.1, U8.10
unnamed: R43.2, U10.CLK
unnamed: R44.2, U10.DOUT
unnamed: R45.2, U11.CLK
unnamed: R46.2, U11.DOUT
unnamed: R51.1, U12.5
PGND: C70.2, C73.2, C74.1, C75.1, NT1.2, R61.1, R67.1, U16.15
PVDD: C1.1, C3.1, C13.1, C14.1, C17.1, C18.1, C19.1, C20.1, C64.1, J7.2, Q3.2, R18.1, U1.5, U3.6, U3.7, U3.32, U3.33
SCL: J6.5, R49.2, U3.28, U8.52, U13.9
SDA: J6.3, R48.2, U3.27, U8.54, U13.8
SPI_CLK: J6.23, R22.2
SPI_CSn: J6.24, R41.1, U8.15
SPI_MISO: J6.21, U8.28
SPI_MOSI: J6.19, U8.16
TAS_Fault: J6.31, R6.2, U3.10
TPU_INTR_18: Q6.2, R55.2, TP8.1, U2.77
TPU_INTR_33: Q6.3, R60.2, U8.34
TPU_PGOOD_18: Q4.2, R37.2, TP6.1, U2.37
TPU_PGOOD_33: Q4.3, R58.2, U13.12
TPU_PMIC_EN_18: Q5.2, R54.2, TP5.1, U2.53
TPU_PMIC_EN_33: Q5.3, R59.2, U13.4
TPU_RST_L_18: Q2.2, R29.2, TP7.1, U2.76
TPU_RST_L_33: J6.11, Q2.3, R56.2, U13.11
UART_RXD_PI: J6.10, U13.7
UART_TXD_PI: J6.8, U13.6
UDA_L: C74.2, OutL1.1, R68.1, U3.19
UDA_R: C75.2, OutR1.1, R69.1, U3.18
USB_CORAL_D+: J13.2, R23.1
USB_CORAL_D-: J13.3, R30.1
VoutL: J2.T, U3.21
VoutR: J2.S, U3.20
XMOS_Reset: D20.3, J6.13, R38.1, U8.55

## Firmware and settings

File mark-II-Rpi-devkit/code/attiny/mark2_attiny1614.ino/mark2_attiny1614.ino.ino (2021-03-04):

#include <Wire.h>

#include <tinyNeoPixel_Static.h>
#include <EEPROM.h>

#define CODE_REVISON  1

#define NEOXPIXELPIN 1
#define MAXSTATES    10
#define BRIGHTNESS   100

// Parameter 1 = number of pixels in strip
// Parameter 2 = Arduino pin number (most are valid)
// Parameter 3 = pixel type flags, add together as needed:
//   NEO_GRB     Pixels are wired for GRB bitstream (most NeoPixel products)
//   NEO_RGB     Pixels are wired for RGB bitstream (v1 FLORA pixels, not v2)
// Parameter 4 = array to store pixel data in

#define NUMPIXELS   12
#define NUMPATTERNS 1 

// Since this is for the static version of the library, we need to supply the pixel array
// This saves space by eliminating use of malloc() and free(), and makes the RAM used for
// the frame buffer show up when the sketch is compiled.

byte pixels[NUMPIXELS * 3];
//byte bufferI2C[NUMPIXELS * 3 + 100];
byte bufferI2C[256];
byte pattern[NUMPATTERNS][NUMPIXELS];

// When we setup the NeoPixel library, we tell it how many pixels, and which pin to use to send signals.
// Note that for older NeoPixel strips you might need to change the third parameter--see the strandtest
// example for more information on possible values. Finally, for the 4th argument we pass the array we
// defined above.

tinyNeoPixel strip = tinyNeoPixel(NUMPIXELS, NEOXPIXELPIN, NEO_GRB, pixels);

// IMPORTANT: To reduce NeoPixel burnout risk, add 1000 uF capacitor across
// pixel power leads, add 300 - 500 Ohm resistor on first pixel's data input
// and minimize distance between Arduino and first pixel.  Avoid connecting
// on a live circuit...if you must, connect GND first.
//volatile byte state = 1;


#define TPU_RST_L   8   //PA1
#define TPU_PGOOD   9   //PA2
#define FAN_TACH    10  //PA3
#define FAN_PWM     0   //PA4

#define TPU_PMIC_EN 2   //PA6
#define GPIO_PA7    3   //PA7

/**
 * EEPROM addresses
 */
#define NUM_BOOTS_ADDR  0

#define SERIAL_NUM_ADDR  10


volatile byte state   = 0;
long lastButtonPress = 0;
volatile bool nextState       = false;
volatile bool readBuffer      = false;

byte serialNumBufAddr = 0xE1;

volatile int revs = 0;
unsigned long rpm = 0;
unsigned long lastmillis = 0;

// refreshrate of data logging/printing in ms (only full seconds!)
int refreshRate = 2000;

void setup() {
  pinMode(TPU_PMIC_EN, OUTPUT);
  pinMode(TPU_RST_L,   OUTPUT);
  digitalWrite(TPU_PMIC_EN, LOW);
  digitalWrite(TPU_RST_L, LOW);
  
  Wire.begin(4);                // join i2c bus with address #4
  Wire.onReceive(receiveEvent); // register event
  Wire.onRequest(requestEvent);
  pinMode(NEOXPIXELPIN,OUTPUT);
  pinMode(FAN_PWM  ,   OUTPUT);
  pinMode(FAN_TACH ,   INPUT); 
  pinMode(TPU_PGOOD,   INPUT);
  attachInterrupt(digitalPinToInterrupt(FAN_TACH), rpm_engine, FALLING);


  //pinMode(TPU_INTR,    INPUT);

  //delay(5);
  //pinMode(TPU_RST_L,   INPUT);
  
  
  //delay(20);
  //digitalWrite(TPU_PMIC_EN, HIGH);
  //delay(20);
  //digitalWrite(TPU_RST_L, HIGH);
  
  //if(digitalRead(TPU_PGOOD)){
    //digitalWrite(TPU_RST_L, HIGH);  
  //}
  strip.setBrightness(BRIGHTNESS);
  strip.show(); // Initialize all pixels to 'off'
  
  setFan(200); // Start Fan as on until Raspberry Pi overrides
  Serial.begin(57600); 
  
  Serial.println("Mycroft Starting");
  
  readNumBoots();
}

void loop() {
  switch(state){
    case 0:
      colorWipe(strip.Color(34, 167, 240), 70 ); // Blue
      colorWipe(strip.Color(0, 0, 0), 50); // 
      //setState( 1 );
      break;
    case 1:
      //strip.show();
      showi2cPixels();
      //colorWipe(strip.Color(200, 0, 0), 70 ); // Blue
      //colorWipe(strip.Color(0, 0, 0), 50); // 
   
      break;
    case 2:
      // Some example procedures showing how to display to the pixels:
      colorWipe(strip.Color(255, 0, 0), 50); // Red
      colorWipe(strip.Color(0, 0, 0), 50); // Red
      break;
    case 3:
      colorWipe(strip.Color(0, 255, 0), 50); // Green
      colorWipe(strip.Color(0, 0, 0), 50); // Red
      break;
    case 4:
      colorWipe(strip.Color(0, 0, 0), 0); // black
      //setState( 1 );
      break;

    case 5:
       theaterChase(strip.Color(127, 127, 127), 200); // White
       break;
    case 6:
      rainbow(5);
      break;
    case 7:
//      rainbowCycle(20);
      break;
    case 8:
 //     theaterChaseRainbow(50);
      break;
/*  
    case 9:
      crossfade();
      break;
 */
    case 10:
      show_pattern();
      state = 255;
      break;
    // 100 - 199 are commands that read stuff from the buffer
    case 100: // set pallete N
      set_pattern();
      break;
    case 101: // fill pallete N with single RGB
      fill_pattern();
      break;
/*    
    case 103: // cross fade between pallete N and M
      setup_crossfade();
      state = 9;
      break;
*/
    case 104:
      show_pattern();
      state = 255;
      break;
    case 202: 
    case 255:
      break;
    default:
      //colorWipe(strip.Color(0, 0, 0), 0); // black
      strip.show();
      break;
  } // end switch stmt

  nextState = false;
  
  setI2CreadOnly();
  // RPM reading & logging/printing of data
  /*
  if (millis() - lastmillis == refreshRate) { // update every one second, this will be equal to reading frequency(Hz)
    detachInterrupt(digitalPinToInterrupt(rpmPin)); // disable interrupt when calculating
     
    // RPM logging/printing
    rpm = revs * 60 / (refreshRate / 1000); // convert frequency to RPM, this works for one interruption per full rotation.
    Serial.print("RPM: ");
    Serial.println(rpm);
   
    // Finish line 
    Serial.println(" ");
    Serial.flush();     
     
    revs = 0; // restart the RPM counter
    lastmillis = millis(); // update lastmillis
  }
  //attachInterrupt(digitalPinToInterrupt(rpmPin), rpm_engine, FALLING); // Enable interrupt
  */
}
void rpm_engine() {
  revs++;
}
  
void resetBootCounts(){
  bufferI2C[0xF5] = 0;   
  bufferI2C[0xF6] = 0;
  bufferI2C[0xF7] = 0;
  bufferI2C[0xF8] = 0;
  EEPROM.write(NUM_BOOTS_ADDR    ,bufferI2C[0xF5] );
  EEPROM.write(NUM_BOOTS_ADDR + 1,bufferI2C[0xF6] );
  EEPROM.write(NUM_BOOTS_ADDR + 2,bufferI2C[0xF7] );
  EEPROM.write(NUM_BOOTS_ADDR + 3,bufferI2C[0xF8] );  

}
unsigned int numBootsVal = 0;
void readNumBoots(){
  EEPROM.get(NUM_BOOTS_ADDR, numBootsVal);
 
  numBootsVal += 1;
  
  EEPROM.put(NUM_BOOTS_ADDR, numBootsVal );
  
  Serial.print("BootNumber: ");
  Serial.println(numBootsVal);
  bufferI2C[0xF5] = numBootsVal >> 8 ;
  bufferI2C[0xF6] = numBootsVal      ;
}

void readSerialNum(){
  byte serial1,serial2, serial3, serial4;
  
  EEPROM.get(SERIAL_NUM_ADDR + 0, serial1);
  EEPROM.get(SERIAL_NUM_ADDR + 1, serial2);
  EEPROM.get(SERIAL_NUM_ADDR + 2, serial3);
  EEPROM.get(SERIAL_NUM_ADDR + 3, serial4);
  bufferI2C[serialNumBufAddr + 0] = serial1;
  bufferI2C[serialNumBufAddr + 1] = serial2;
  bufferI2C[serialNumBufAddr + 2] = serial3;
  bufferI2C[serialNumBufAddr + 3] = serial4;      
}

void writeSerialNum(){
  EEPROM.put(SERIAL_NUM_ADDR + 0, bufferI2C[serialNumBufAddr + 0]);
  EEPROM.put(SERIAL_NUM_ADDR + 1, bufferI2C[serialNumBufAddr + 1]);
  EEPROM.put(SERIAL_NUM_ADDR + 2, bufferI2C[serialNumBufAddr + 2]);
  EEPROM.put(SERIAL_NUM_ADDR + 3, bufferI2C[serialNumBufAddr + 3]);
}
long lastReadTime   = 0;
#define READ_INTERVAL 100
volatile bool readEEPROM = true;
volatile bool writeEEPROM = false;

/**
 * Read in statuses from inputs and load them into I2CBuffer
 */
void setI2CreadOnly(){
   if (millis() - lastReadTime > READ_INTERVAL ){
     // bufferI2C[80] = pulseIn(FAN_TACH, HIGH, 100) ;
      bufferI2C[0x51] = digitalRead(TPU_PGOOD);
      bufferI2C[0x52] = digitalRead(TPU_PMIC_EN);
      //bufferI2C[0x53] = digitalRead(TPU_INTR);
      bufferI2C[0x54] = digitalRead(TPU_RST_L);
      bufferI2C[0x60] = 0xFF;    
      bufferI2C[0x61] = CODE_REVISON;
      long timestampNow = millis();  
      bufferI2C[0xF0] = timestampNow & 0xFF;
      bufferI2C[0xF1] = (timestampNow >> 8) & 0xFF;
      bufferI2C[0xF2] = (timestampNow >> 16) & 0xFF;
      bufferI2C[0xF3] = (timestampNow >> 24) & 0xFF;
      bufferI2C[0xF4] = 0xF4; 

      
      if(readEEPROM == true){
        readSerialNum() ; 
        readEEPROM = false;
      }
      if(writeEEPROM == true){
        writeSerialNum();
        writeEEPROM = false;
        readEEPROM = true;        
      }      
      
      lastReadTime = millis();
      
   }
   
}


/**
 * Speed is 0 to 255
 */
void setFan(byte fanSpeed){

  // FAN_PWM at zero turns on Fan
  // invert input so 255 is full on, zero is off
  analogWrite(FAN_PWM, constrain(255 - fanSpeed, 0, 255));

}
inline void setState(byte s1){
  state = s1;
  if(state > MAXSTATES){
      state = MAXSTATES;
   }
   //nextState = true;
   readBuffer = false;
}
int getState(){
  return state;  
}
/**
 * Is the boot sequence running
 */
bool isBootSequenceRunning(){
  if(getState() == 0){
    return true;  
  }  
  return false;
}

void cycleStates(){
  if(millis() - lastButtonPress > 100 ){
    state++;
    if(state > MAXSTATES){
      setState(0);
    }
    lastButtonPress = millis();
  }
  nextState = true;
}

// Fill the dots one after the other with a color
void colorWipe(uint32_t c, uint8_t wait) {
  for(uint16_t i=0; i<strip.numPixels() && !nextState; i++) {
    strip.setPixelColor(i, c);
    strip.show();
    delay(wait);
  }
}

void showi2cPixels() {
  for(uint16_t i=0; i<strip.numPixels(); i++) {
    strip.setPixelColor(i, strip.Color(bufferI2C[i * 3], bufferI2C[i * 3+1], bufferI2C[i * 3+2]) ); // set color from i2c
    delay(10);
    strip.show();
  }
  strip.show();
}

void show_pattern() {
  byte pattern_num = bufferI2C[1];
  for(byte i=0; i<strip.numPixels(); i++) {
    strip.setPixelColor(i, strip.Color(pattern[pattern_num][i*3], pattern[pattern_num][i*3+1], pattern[pattern_num][i*3+2] )); // set color from pattern
    delay(10);
  }
  strip.show();
}

/*
byte fade_pattern_0;
byte fade_pattern_1;
byte fade_step;
byte fade_speed;
byte fade_pause;

void setup_crossfade() {
   fade_pattern_0 = bufferI2C[1];
   fade_pattern_1 = bufferI2C[2];
   fade_step      = bufferI2C[3];
   fade_speed     = bufferI2C[4];
   fade_pause     = bufferI2C[5];
}

void crossfade() {
  byte temp;
  uint16_t r,g,b;
  while (!nextState) {
    for(byte fade = 0; fade < 255; fade += fade_step) {
      for(byte i = 0; i < strip.numPixels(); i++) {      
        r = (((pattern[fade_pattern_0][i*3 + 0] * fade)) / 256)
          + ((pattern[fade_pattern_1][i*3 + 0] * (255 - fade)) / 256);
        g = (((pattern[fade_pattern_0][i*3 + 1] * fade)) / 256)
          + ((pattern[fade_pattern_1][i*3 + 1] * (255 - fade)) / 256);
        b = (((pattern[fade_pattern_0][i*3 + 2] * fade)) >> 8)
          + ((pattern[fade_pattern_1][i*3 + 2] * (255 - fade)) / 256);
        strip.setPixelColor(i, strip.Color(r,g,b));   
      }
      strip.show();
      temp = fade_pattern_0;
      fade_pattern_0 = fade_pattern_1;
      fade_pattern_1 = temp; 
      delay(fade_speed);
    }
    delay(fade_pause);
  }
}
*/



void rainbow(uint8_t wait) {
  uint16_t i, j;

  for(j=0; j<256 && !nextState; j++) {
    for(i=0; i<strip.numPixels() && !nextState; i++) {
      strip.setPixelColor(i, Wheel((i+j) & 255));
    }
    strip.show();
    delay(wait);
  }
}
/*
// Slightly different, this makes the rainbow equally distributed throughout
void rainbowCycle(uint8_t wait) {
  uint16_t i, j;

  for(j=0; j<256*5 && !nextState; j++) { // 5 cycles of all colors on wheel
    for(i=0; i< strip.numPixels() && !nextState; i++) {
      strip.setPixelColor(i, Wheel(((i * 256 / strip.numPixels()) + j) & 255));
    }
    strip.show();
    delay(wait);
  }
}
*/
//Theatre-style crawling lights.
void theaterChase(uint32_t c, uint8_t wait) {
  for (int j=0; j<10 && !nextState; j++) {  //do 10 cycles of chasing
    for (int q=0; q < 3 && !nextState; q++) {
      for (int i=0; i < strip.numPixels(); i=i+3) {
        strip.setPixelColor(i+q, c);    //turn every third pixel on
      }
      strip.show();

      delay(wait);

      for (int i=0; i < strip.numPixels() && !nextState; i=i+3) {
        strip.setPixelColor(i+q, 0);        //turn every third pixel off
      }
    }
  }
}

/*
//Theatre-style crawling lights with rainbow effect
void theaterChaseRainbow(uint8_t wait) {
  for (int j=0; j < 256 && !nextState; j++) {     // cycle all 256 colors in the wheel
    for (int q=0; q < 3 && !nextState; q++) {
      for (int i=0; i < strip.numPixels() && !nextState; i=i+3) {
        strip.setPixelColor(i+q, Wheel( (i+j) % 255));    //turn every third pixel on
      }
      strip.show();

      delay(wait);

      for (int i=0; i < strip.numPixels() && !nextState; i=i+3) {
        strip.setPixelColor(i+q, 0);        //turn every third pixel off
      }
    }
  }
}
*/
// Input a value 0 to 255 to get a color value.
// The colours are a transition r - g - b - back to r.
uint32_t Wheel(byte WheelPos) {
  WheelPos = 255 - WheelPos;
  if(WheelPos < 85) {
    return strip.Color(255 - WheelPos * 3, 0, WheelPos * 3);
  }
  if(WheelPos < 170) {
    WheelPos -= 85;
    return strip.Color(0, WheelPos * 3, 255 - WheelPos * 3);
  }
  WheelPos -= 170;
  return strip.Color(WheelPos * 3, 255 - WheelPos * 3, 0);
}


void set_pattern() {
  byte pattern_num = bufferI2C[0];
  byte addrStart   = bufferI2C[1];
  pattern[pattern_num][addrStart * 3] = bufferI2C[2];
  pattern[pattern_num][addrStart * 3] = bufferI2C[3];
  pattern[pattern_num][addrStart * 3] = bufferI2C[4];
}

void fill_pattern() {
  byte pattern_num = bufferI2C[0];
  for (byte i=0; i < NUMPIXELS; i++) {
    pattern[pattern_num][1 + i * 3] = bufferI2C[1];
    pattern[pattern_num][2 + i * 3] = bufferI2C[2];
    pattern[pattern_num][3 + i * 3] = bufferI2C[3];
  }
}



byte lastNumItems = 0;
byte addrStart    = 0;
volatile byte reg          = 0;
// function that executes whenever data is received from master
// this function is registered as an event, see setup()
/**
 * 
 * sudo ./vfctrl_usb  SET_I2C_WITH_REG 74 5 13   5  100 101 102 103 104 105 106 107 108 109 110 116  112  113  0  0  0  0  0  0  0  0  0  0  0  0  0 0  0  0  0  0  0  0  0  0  0  0  0  0  0  0  0 0  0  0  0  0  0  0  0  0  0  
 * SET_I2C_WITH_REG 74 5 13   5 
 *               74 Address
 *                5 start byte
 *               13 length
 *                5 state to set 
 *          101...  12 bytes for colors
 *                  
 **/

void receiveEvent(int howMany) {
  readBuffer = true;
  byte i = 0;

  lastNumItems = howMany;

  /**
   * if how many, then requesting a read, else read pixel values
   */
  if(howMany == 1){
    reg = Wire.read();
    //Serial.println(reg, HEX );
    Serial.println("Reading" );
  }
  else{
    addrStart     = Wire.read() ; // first byte is pixel address or command
    
    if(addrStart < NUMPIXELS) {
      while (1 <= Wire.available()) { // loop through all but the last
        byte c = Wire.read(); // receive byte as a character
        bufferI2C[addrStart * 3 + i] = c;
        i++;
      }
      setState(1);
    }
    else  {
      while (1 <= Wire.available()) { // loop through all but the last
        byte c = Wire.read(); // receive byte as a character
        bufferI2C[addrStart ] = c; 
      }     
    }
    
    if (addrStart == 101){ //0x65
      byte fanSpeed = 0;
      fanSpeed = bufferI2C[101]; 
      setFan(fanSpeed);  
    }
    /**
     * Set the Enable TPU
     */
    if (addrStart == 0x52){
      if(bufferI2C[0x52] == 1){
        digitalWrite(TPU_PMIC_EN, HIGH);
      }
      else{
        digitalWrite(TPU_PMIC_EN, LOW);
      }
    }
    if (addrStart == 0x53){
      if(bufferI2C[0x53] == 1){
        digitalWrite(TPU_RST_L, HIGH);
      }
      else{
        digitalWrite(TPU_RST_L, LOW);
      }
    } 
    if(addrStart == serialNumBufAddr + 3){
      
      writeEEPROM = true;
      //readEEPROM = true;
      
    }    
      
    nextState = true;
  }
}


//byte startingNum = 0;
void requestEvent() {
   //byte count = 0;

   if(reg < 256 && reg >= 0 ){
     Wire.write(bufferI2C[reg]);
     //Wire.write(reg);
   }
   //Wire.write(0x44);
   //Serial.println(bufferI2C[reg]);
}

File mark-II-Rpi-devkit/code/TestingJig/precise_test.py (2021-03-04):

#!/usr/bin/env python3
'''

install directions:
    sudo apt-get -y remove libportaudio2
    sudo apt-get -y install libasound2-dev
    git clone -b alsapatch https://github.com/gglockner/portaudio
    
    cp /home/mycroft/PCBtests/pa_linux_alsa.c /home/mycroft/portaudio/src/hostapi/alsa/pa_linux_alsa.c
    cd portaudio
    ./configure && make
    sudo make install
    sudo ldconfig
    cd ..


   wget http://files.portaudio.com/archives/pa_stable_v190600_20161030.tgz
   tar xvzf pa_stable_v190600_20161030.tgz
   cd portaudio/
   cp /home/mycroft/PCBtests/pa_linux_alsa.c  /home/mycroft/portaudio/src/hostapi/alsa/pa_linux_alsa.c
   ./configure
   make
   sudo make install
   ldconfig
   
   sudo pip3 install precise-runner
   
   
   
run:
   sudo python3 /home/mycroft/PCBtests/precise_test.py
'''

from precise_runner import PreciseEngine, PreciseRunner
from time import sleep
import os
import logging
logging.basicConfig(filename='/home/mycroft/PCBtests/heymycroft.log', format='%(asctime)s %(levelname)-8s %(message)s',
    level=logging.INFO,
    datefmt='%Y-%m-%d %H:%M:%S')

logging.warning('File-started')

def on_activation():
    os.system("aplay /opt/mycroft/mycroft/res/snd/start_listening.wav")
    print("\n *** Hello! *** \n")
    logging.warning('activated')


def on_prediction(confidence):
    #print(confidence)
    #logging.warning(confidence)
    return True
trigger_lvl = 3

engine = PreciseEngine('/home/mycroft/.mycroft/precise/precise-engine/precise-engine', '/home/mycroft/.mycroft/precise/hey-mycroft.pb')

#runner = PreciseRunner(engine, on_activation=lambda: print('hello'))
runner = PreciseRunner(engine, trigger_lvl, sensitivity=0.5, on_activation=on_activation, on_prediction=on_prediction)

runner.start()

# Sleep forever
while True:
    #print("1")
    sleep(1000)

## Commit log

2020-01-20 Create Mark II CAD files.txt
2020-01-28 Create BOM
2020-01-28 Update BOM
2020-01-30 Create STL
2020-01-30 Create threaded insert locations.md
2020-07-14 reorganizing files
    Renamed repo to hard-ware-mycroft-mark-II to encompass all Mark II hardware projects, and renamed Mark-II-rpi-prototype to Mark-II-rpi-ots. Created mark-II-rpi-devkit for the current raspberry pi bas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
    [MIIr_AC_front_pi3_r2.1.STL, MIIr_AC_pi3_r2.1.STL, MIIr_back_bosses_pi3_r2.STL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]
2020-07-14 Initial Design
    [71609-320LFc.stp, Adafruit MAX9744.brd, Adafruit MAX9744.sch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]
2020-07-15 Replace SMD 40pin header, replace with Thru Hole version
    [Mycroft - Mark 2-2020-07-13-17-50-46.csv, Mycroft - Mark 2-2020-07-14-17-53-30.csv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]
2020-07-15 Update BOM - fix OPL numbers for Seeed PCBA
    [Mycroft - Mark 2-2020-07-15-08-26-18.csv, Mycroft - Mark 2-2020-07-15-09-17-59.csv, Mycroft - Mark 2-seeed-2020-07-15-09-18-01.csv]
2020-07-15 fix library so only using 0.3mm drill and bigger
    [Mycroft - Mark 2-B_Cu.gbr, Mycroft - Mark 2-B_Mask.gbr, Mycroft - Mark 2-B_Paste.gbr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]
2020-07-22 Updated KiCAD files to 0.63 for PCB printing & Assembly at JLCPCB
    [AudioAmp.sch, Mycroft - Mark 2-2020-07-22-11-54-13.csv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]
2020-07-22 Add updated PCB Renders
2020-07-24 Change USB IC to CM108B, add in Line Out jack, prep for 2 PCB sandwich
    [AudioAmp.sch, Mycroft - Mark 2-2020-07-23-23-07-48.csv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]
2020-07-24 Change vertical barrel connector, files sent to JLC PCB for printing and assembly.
    [AudioAmp.sch, Mycroft - Mark 2-2020-07-24-10-26-28.csv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]
2020-08-08 Mark 2 - PCB Files to the printer
    [Mycroft - Mark 2-2020-07-25-07-52-20.csv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]
2020-08-17 Update to v0.66 - printed at JLC - 2nd spin
    [AudioAmp.sch, Mycroft - Mark 2-2020-08-14-17-57-11.csv, Mycroft - Mark 2-2020-08-17-08-47-43.csv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]
2020-08-29 Fix missing items in schematic in Github
    [AudioAmp.sch, Mycroft - Mark 2.kicad_pcb, Power.sch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]
2020-08-29 Fix missing items in schematic in Github - add in libraries
2020-09-04 Add in USB Adapter - SJ-202
    [SJ-202-USB Board.DXF, SJ-202-USB-Jumper-2020-09-04-12-42-47.csv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]
2020-09-27 SJ201 - Removed CM108b soundcard, added in I2S to Line out, ATTin402. Moved holes in layout. SJ202 - extened length to plug into USB2.0 port
    [AudioAmp.sch, Mycroft - Mark 2-2020-07-22-11-54-13.csv, Mycroft - Mark 2-2020-07-23-23-07-48.csv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]
2020-09-27 SJ201 Move BOM files into BOM folder
    [Mycroft - Mark 2-2020-07-15-09-50-22.csv, Mycroft - Mark 2-2020-09-27-11-58-07.csv, Mycroft - Mark 2-2020-09-27-13-24-04.csv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]
2020-10-08 SJ-201 v3, sent to PCB Fab. Removed USB Hub, add in I2S to Line Out
    [AudioAmp.sch, Mycroft - Mark 2-2020-09-27-13-24-04.csv, Mycroft - Mark 2-2020-10-04-22-47-19.csv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]
2020-10-08 SJ-202 USB Jumper Update & Readme updates
    [SJ-202-USB-Jumper-2020-10-03-11-46-38.csv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]
2020-11-20 Rev4 Update - Add in Coral TPU, TAS5806, remove I2S * MAX9744. Change Attiny to Attin1614
    [AudioAmp.sch, Coral.sch, Power.sch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]
2020-11-23 Rev4 Update - fix some wiring, export for printing Rev 4
    [AudioAmp.sch, Coral.sch, CoralTPU.SLDPRT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]
2020-12-11 Update README.md
    Updated for Rev 4 board specs.
2021-01-02 SJ-201-R6 for FAB - removed buffer IC
    [AudioAmp.sch, Coral.sch, MCU.sch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]
2021-03-04 Updated files for R6 v2
    [AudioAmp.sch, Coral.sch, MCU.sch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]
2021-03-04 Remove extra images folder, add in Gerbers
    [SJ-201-R6-B_Adhes.gbr, SJ-201-R6-B_CrtYd.gbr, SJ-201-R6-B_Cu.gbr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]
2021-03-04 Update Reference Files, remove unused parts
    [Adafruit MAX9744.brd, Adafruit MAX9744.sch, RH025.1.brd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]
2021-03-05 Update part datasheet for 12v power to 5v
2021-03-08 Cleaned up SJ201 directory
    [Mycroft - Mark 2.kicad_pcb, Mycroft - Mark 2.sch]
2021-03-08 Removed unused files, cleaned up directory, remove SJ202
    [71609-320LFc.stp, AudioAmp.sch, CUI_DEVICES_PJ-090H.step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]
2021-03-14 Update libraries, reorganize files
    [AudioAmp.sch, Coral.sch, CoralTPU.step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]
2021-03-18 Create MkII SJ240 SW19 r9.zip
    Added Zip containing STEP files of the SJ240 R9 enclosure
2021-11-08 MII AC spacer
    Added AC Spacer for SJ240 3D printed design
    [MKII AC spacer r2.STL]
2021-12-07 Added Speaker Spacer for alternate speaker driver
    [MKII speaker_spacer r9.STL]
2021-12-07 Audio Chamber for SJ230 (laser cut enclosure)
    [MKII Audio Chamber r9.STL]
2022-09-23 Add SJ240 3D print files
    The SJ240 is the 3D printed enclosure.
    These STL files can be used to print an enclosure for the Mark II Dev Kit.
    Note that screws and threaded inserts are also required.
2022-09-23 Add info on 3D print files
    Includes link to appropriate threaded inserts
2022-09-23 Add link to Instructables for 3D printed case
2022-10-25 BOM for SJ-201-R10
    [SJ-201-R10-2022-07-29-08-44-49.csv]
2023-02-20 Create MkII SJ250 ASSEM r6.zip
    Mark II production mechanical CAD full assembly in STEP format
2023-02-24 add body assembly instructions
2023-02-24 add images for body assembly
2023-02-24 upload top, speaker and display assembly images
2023-02-24 formatting tweaks to top assembly instructions
2023-02-24 add speaker and display assembly instructions
2023-06-13 Added KiCAD layout file

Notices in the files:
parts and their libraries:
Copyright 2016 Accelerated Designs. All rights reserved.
